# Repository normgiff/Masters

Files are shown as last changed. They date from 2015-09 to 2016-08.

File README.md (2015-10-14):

<!--
Norman Gifford
u0723476
This is my main Page
-->

<head>
<title>University of Utah Masters</title>
<link rel="stylesheet" type="text/css" href="stylesheet.css">

</head>
<body>

<div id="header">
	<h1>Daniel Khoury and Norman Gifford</h1>
	<h2>Computer Engineering Masters Project</h2>
</div>

<div id="main_body">

<p class="center_text">
Welcome to our computer engineering masters project website! Daniel and Norman
are computer engineering masters students at the University of Utah. One of the
important subjects of study st the University of Utah is VLSI (very large circuit 
integration). So important that the university gives it students the opportunity 
design and fabricate a integrated circuit chip. In important part of this process 
is to test these chips an to see if they function properly. The testers they have 
at the school to do this are either so old that it is virtually impossible to find 
replacement parts or it is very complicated to use. For these reasons our masters 
project is to design a tester that will be cheeper and easier to use. Some of the 
features are:

<ul>
	<li>	Real Time Testing.</li>
	<li>	Schmooing both Voltage and Frequency.
</ul

</p>

</div>

</body>
</html>

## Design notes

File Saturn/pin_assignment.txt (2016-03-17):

Header P3 on Numato Saturn: 
Pins 5 - 48, 53 - 88 (80 pins total)
These pins go to the ZIF socket. 

Header P2 on Numato Saturn: 
Pins 7 - 8, 11 - 12, 15 - 44, 53 - 64 (46 pins total)
These pins go to the ZIF socket.

Remaining pins on Header P2: 
65 - 88 (24 pins)

Pins 65 - 66: RX/TX lines for BBB communication
Pins 67 - 71: Four clocks for counter ICs, one reset
Pins 72 - 76: Five output buffer signals
Pins 77:      Enable pin for voltage translators
Pins 78 - 86: One output enable pin (all SRAM ICs), four ~CS signals (one per two ICs), four ~WE signals (one per two ICs)
Pins 87 - 88: Not used

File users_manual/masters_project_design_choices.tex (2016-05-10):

\section{Master's Project: Design Decisions}

\subsection{Initial Plan}
Despite the many areas of improvement for our senior project, we initially believed that a functional tester was adequate for most student-designed VLSI chips. It is worth noting that at the time of our senior project semester, students in VLSI designed their chips using a 0.6 micron process. Generally, chips fabricated using this process cannot run beyond 25 MHz. As such, we believed the best course of action was to polish our system (e.g. simplify the user interface and setup) in order to allow students to test their chips' functionality. For any timing-sensitive chips, students would be advised to construct a development board for their chip and use a logic analyzer or oscilloscope to analyze signals in detail.

When we first proposed expanding upon our senior project for our Master's project, our basic plan was to do the following: 
\begin{itemize}
\item Eliminate the Numato Saturn and fabricate a MOSIS chip containing the finite state machine logic originally used by the Saturn.
\item Replace the double-buffered shift registers inside the Saturn with external double-buffered shift registers controlled by a MOSIS chip.
\item Implement autoschmooing by replacing the trimpot on our variable voltage regulator with a digital pot.
\item Expand upon our C Sharp program (e.g. create schmooing plots).
\item Try to redesign our main PCB with equilibrium tracing.
\end{itemize}

While the plan seemed solid at first, we quickly became concerned that the project may not have been challenging enough for a Master's project. We soon came to believe that attempting to implement both autoschmooing and real-time testing would provide a more suitable challenge to us, and so, we decided to revamp our entire senior project design.

\subsection{Revised Plan}
We redefined the goals of our Master's project as follows: 
\begin{itemize}
\item Simpler interface and setup. Ideally, the entire system would be plug-and-play.
\item Real-time testing (where a test cycle is executed immediately following completion of the preceding test cycle).
\item Timing information (via PCB equilibrium tracing).
\item Automated schmooing.
\item More test cycle configurations.
\end{itemize}

We spent Fall 2015 brainstorming ideas to implement the above goals. We proposed the schematic in Figure \ref{fig:f15_schematic} at the end of the semester. Below, we detail each major component of this schematic.

\begin{figure}
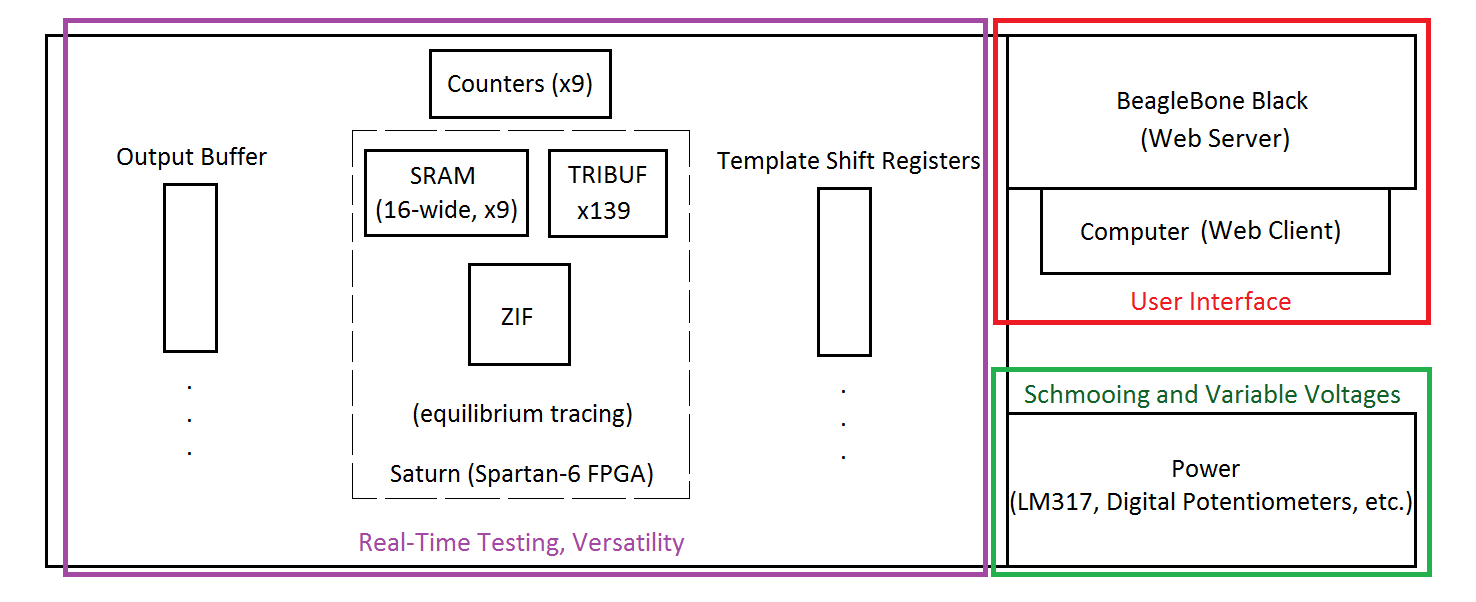
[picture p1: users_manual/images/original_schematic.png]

\caption{Schematic proposed at end of Fall 2015 semester.}
\label{fig:f15_schematic}
\end{figure}

\subsubsection{User Interface}
With our senior project, the user needed to use Windows in order to run our GUI and had to program MicroBlaze every time the system lost power. With our Master's project, we wanted a "plug and play" interface. To eliminate the need for any particular OS, we decided to use a web browser to interface with the testing system. We decided to use the BeagleBone Black board that Norm and Daniel each purchased when they took Advanced Embedded Software in Fall 2014.

The BeagleBone Black works well because it can host a small web server, runs on Linux, has the necessary I/O (SPI, UART, GPIO), and provides plenty of memory. 

\subsubsection{Timing and Voltage Schmooing}
Time schmooing, i.e. modulating the test cycle configuration (delay, width, length) between tests, naturally requires equilibrium tracing. We planned to manually route any PCBs we would design to minimize the difference in trace lengths.

Figure \ref{fig:power_schematic} is a schematic that we designed for voltage schmooing. Much of the schematic is based upon the variable voltage regulator LM317's datasheet. As the LM317 uses a reference voltage of 1.25V, we added a -1.25V bias created by an op-amp buffer (bottom-left of schematic) to set the reference voltage to 0V. We learned of this trick from  \href{http://electronics.stackexchange.com/questions/186760/why-do-linear-voltage-regulators-have-minimum-output-voltage-0-v}{this} StackExchange post. 

\begin{figure}[!h]
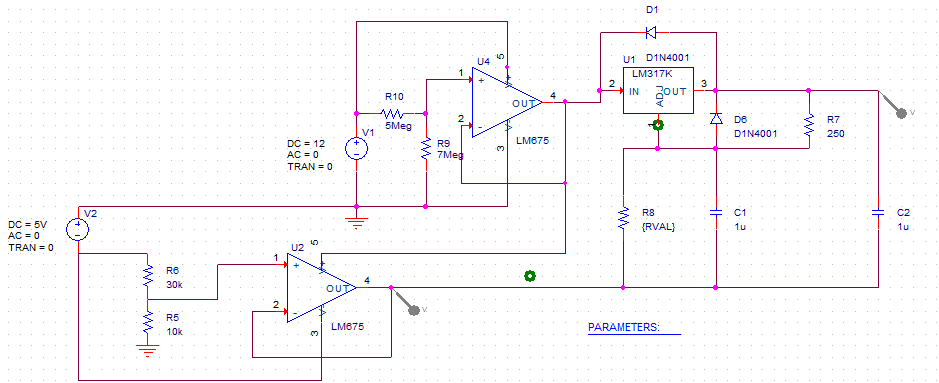
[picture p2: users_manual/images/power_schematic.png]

\caption{Power schematic for voltage schmooing.}
\label{fig:power_schematic}
\end{figure}

We simulated this schematic in PSpice and prototyped the schematic using a trimpot for the variable resistor. Figure \ref{fig:power_results} shows that the output voltage, much to our liking, responds linearly to a change in the resistance of the variable resistor.

There is an important tradeoff worth mentioning with this schematic. A higher variable resistor allows for more granularity in the output voltage. However, there is a small but fixed current that travels through the variable resistor; a larger variable resistor creates a larger error term in the output voltage. Refer to the LM317's datasheet online for more information.

For the variable resistor, we researched digital potentiometers and found that the AD5293, with 10-bit resolution at 20 kOhms, should serve well for the project.

\begin{figure}
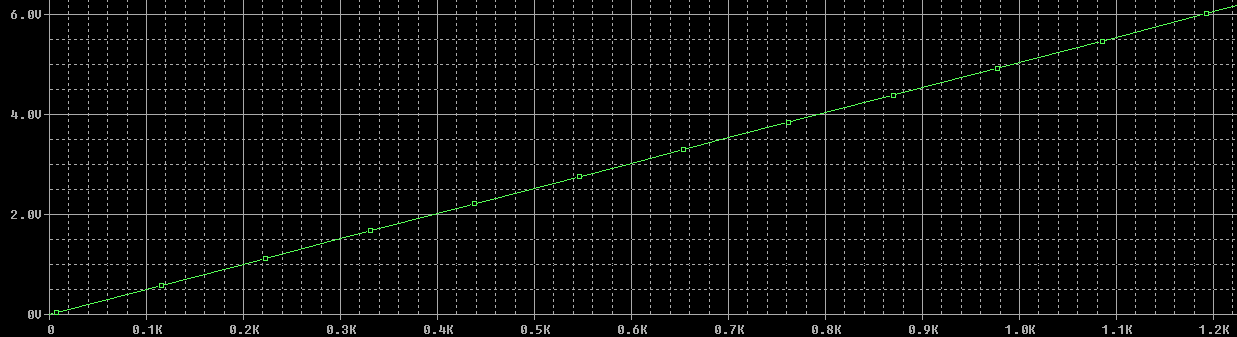
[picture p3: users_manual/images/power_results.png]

\caption{PSpice simulation results for power circuitry.}
\label{fig:power_results}
\end{figure}

\subsubsection{Real-Time Testing}
Devising a plan for real-time testing was easily the most challenging issue we faced. With our senior project, handling one input and output vector at a time was convenient because we only needed one set of double-buffered registers for all of the vectors associated with a test cycle. As such, we had to determine where the input vectors and output vectors should actually be stored.

Ultimately, we proposed the scheme in Figure \ref{fig:real_time_testing}. The basic idea was to store output vectors into external SRAM chips, and then later fetch the SRAM contents using some sort of parallel-to-serial shift register. Not shown in the image, we chose to store the input vectors in the Spartan-6 FPGA's block RAM (which allow for fast reads).

The key idea is that during test execution -- the only moment in which timing is important as far as the DUT goes -- the system only concerns itself with fetching and applying input vectors. 

\begin{figure}
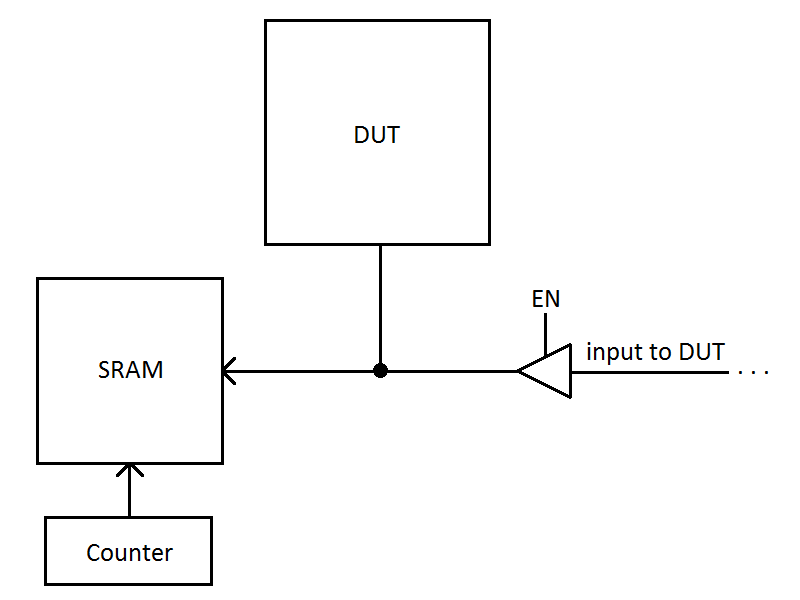
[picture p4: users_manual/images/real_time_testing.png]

\caption{Real-time testing scheme. Input vectors are stored in the FPGA's block RAM; output vectors are stored in separate SRAM chips.}
\label{fig:real_time_testing}
\end{figure}

\subsubsection{Versatility}
Though we had no specific proposals at the end of Fall 2015, we hoped to bring legacy to our project and make it upgradeable and adequate for students to use for at least a few years.

Ultimately, some of the ways we encompassed versatility in our project design is the use of multiple PCBs and the BeagleBone Black web server, which is easy to develop on.

\newpage

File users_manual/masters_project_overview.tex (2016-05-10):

\section{Master's Project: Analysis}

\subsection{Demo Video}
Although we did not have a working Communication Board at the time of our presentation, we were still able to demo our system. The video of our demo is available \href{https://www.youtube.com/watch?v=Cojl8VEp_cA&feature=youtu.be}{here}. Note that the DUT used is a MOSIS-fabricated chip containing several simple combinational and sequnetial circuits.

\subsection{What Worked}
Our demo video proves that the core ideas behind our project are sound: by making use of a Spartan-6 FPGA's block RAM and external circuitry to store output vectors, real-time testing, as well as a decent level of granularity when configuring test cycles, is feasible. 

We are particularly proud of our choice to use a BeagleBone Black for user interfacing. Using a web form to configure the tester is far more straightforward than using the .msa file template supported by the LV500. The BeagleBone Black also provides plenty of memory for storing test configurations and results.

\subsection{Areas of Improvement}
Please refer to Section 8 (Advice for Future Work).

\subsection{Difficulties Encountered}

\subsubsection{Solder Mistakes}
When we first received the DUT Board, Daniel accidentally soldered an SRAM chip upside-down. All of our attempts to remove the SRAM chip failed. Out of concern that we may have damaged the board while trying to remove the chip, we decided to scrap the board and order a new one.

\subsubsection{Communication Board}
The Communication Board, as mentioned early, has proven to be our most challenging board to get right. Power modulation can be tricky!

\subsubsection{Fitting the Verilog}
Initially, we planned to support four force-formats provided by the LV500: R0, R1, DNRZ L, and DNRZ T. When we first synthesized our Verilog, we found that our design required about 110 percent of the available slice LUTs on the board. 

After reducing the number of available force-formats to just R0 (useful for clock signals) and DRNZ L, our design only required 70 percent of the available slice LUTs, but it required about 115 percent of the available area due to routing.

We initially planned to support two completely separate test cycle configurations. To reduce the area required, we modified our design to allow one test cycle configuration, but two different leading edges (delays). After this change, we were able to fit our design into the FPGA board. Our design currently uses about 40 percent of the available slice LUTs and about 60 percent of the available area. 

Lesson learned: the amount of slice LUTs on the Spartan-6 FPGA - a little over 9000 - is not that many!

\subsubsection{Glitches in FPGA Outputs}
The output signals of the FPGA used to clock the counters are sometimes glitchy, causing the counter to increment more than intended. Having a latch driving these outputs does not appear to fix the problem. We will experiment with using the FPGA delay lines to clean the glitches; if that doesn't work, we may try using small external capacitors to clean the glitches.

\subsection{Before We Leave}
As of this writing, Daniel and Norm will both be in Utah before May 28. Before we leave, we plan to do the following:
\begin{itemize}
\item Fix the Communication Board.
\item Write the code that parses the web form and programs the digital potentiometers and the FPGA accordingly.
\item Design housing for the three PCBs.
\item Attempt to fix the glitches in the counter clock signals.
\item Organize and clean up our repository.
\item Update this document accordingly.
\end{itemize}

\newpage

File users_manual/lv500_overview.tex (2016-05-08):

\section{Overview of ASIC Testers}
All ASIC testers build upon the same simple interface: 
\begin{enumerate}
\item The user specifies what outputs to expect from their chip in response to what inputs.
\item The system applies the user-specified inputs to the device under test (DUT) and later samples the outputs of the DUT.
\item The machine reports how the sampled outputs compare to the outputs expected by the user.
\end{enumerate}

Below, we dissect and analyze these three steps both abstractly and via the LV500's implementation. Throughout this section, we define some terminology borrowed from the LV500. 

\subsection{Input and Output Bit Vectors}
Terminology: 
\begin{itemize}
\item \textbf{Input vector}: An ordered list of 0s and 1s that correspond to some ordering of a subset of the DUT's input pins. 
\item \textbf{Output vector}: An ordered list of \textit{expected} 0s and 1s that correspond to some ordering of a subset of the DUT's output pins. 
\end{itemize}

As ASIC testers are generally not designed with any specific DUT in mind, much more information accompanying input and output vectors must be provided.

\subsubsection{Pin Locations}
Any ASIC tester will define "pin locations" that are associated with some kind of socket used to connect a DUT to the tester. Obviously, mapping pins on a DUT to pin locations on an ASIC tester varies per tester. The key idea to keep in mind is that the user does not have to inform the tester of every input and output signal on the DUT. Only the pins on the DUT that the user wishes to test must be mapped to the tester's pin locations. Depending on the tester, any unspecified DUT pins may be left floating or pulled high/low with a resistor.

\subsubsection{Pin Directions}
\begin{flushleft}
Terminology: 
\begin{itemize}
\item \textbf{Pin direction}: A designator that specifies whether a DUT pin is an input or output.
\item \textbf{Template}: A bit vector that maps DUT pins to pin directions.
\end{itemize}
\end{flushleft}

In addition to providing the locations of the DUT pins to test, the user must specify the direction of these types of pins using templates. Every input and output vector is associated with some template. For bidirectional pins, different templates can be applied at different phases throughout a test. One template may designate a signal X as an input while a different template may designate that same signal X as an output. 

Thus far, we have described (abstractly) how to tell an ASIC tester about the pins on a DUT that we wish to test, which of those pins are inputs/outputs, and the signals that we expect to see in response to the signals that we wish to apply to the input pins. We must answer two other questions for the ASIC tester: 

\begin{enumerate}
\item When should input signals be applied to the DUT's input pins, and when should signals from the DUT's output pins be sampled?
\item After we apply the input signals to the DUT, what should we do with the input signals before and after the output pins are sampled?
\end{enumerate}

\subsection{Test Cycles}
One thing we must specify is when input signals to the DUT should be applied and when output signals of the DUT should be sampled.

\begin{flushleft} 
Terminology:  
\begin{itemize}
\item \textbf{Test cycle}: A window of time wherein an input vector is forced upon the DUT and the output signals of the DUT are (later) sampled.
\item \textbf{Test cycle length}: The length (in time) of a test cycle.
\item \textbf{Test cycle delay}: The amount of time between the beginning of the test cycle and when an input vector should be forced upon the DUT.
\item \textbf{Test cycle width}: The amount of time between when an input vector should be forced upon the DUT and when the output signals of the DUT should be sampled.
\item \textbf{Test}: The execution of all input vectors specified by the user.
\end{itemize}
\end{flushleft}

Figure \ref{fig:singleTestCycle} below illustrates how a test cycle can be thought of as just a configurable pulse (though test cycles don't necessarily have to be implemented as an actual pulse). It is important to note that the test cycle itself is NOT sent to the DUT. Test cycles use two edges (a rising edge and falling edge) to signify when to force inputs and sample outputs, respectively.

\begin{flushleft}
Terminology: 
\begin{itemize}
\item \textbf{Leading edge}: A rising edge that corresponds to a test cycle's delay.
\item \textbf{Trailing edge}: A falling edge that corresponds to a test cycle's width.
\end{itemize}
\end{flushleft}

To get a sense of how test cycles are used, consider Figure \ref{fig:ANDGateTestCycle} below. Assume the following setup as the context of this figure: 
\begin{itemize}
\item Our DUT contains three pins mapping to a two-input AND gate that we wish to test.
\item We have informed the ASIC tester of where these three pins are located, which two of the three pins are inputs, and which of the three pins is the output. (We have also named the input pins A and B and the output pin Y for convenience.)
\item We have specified two input vectors: {A = 1, B = 1} and {A = 0, B = 0}, along with two corresponding output vectors: {Y = 1} and {Y = 0}.
\item We specified a test cycle length of 100 ns, a test cycle delay of 20 ns, and a test cycle width of 50 ns.
\end{itemize}

\begin{figure}
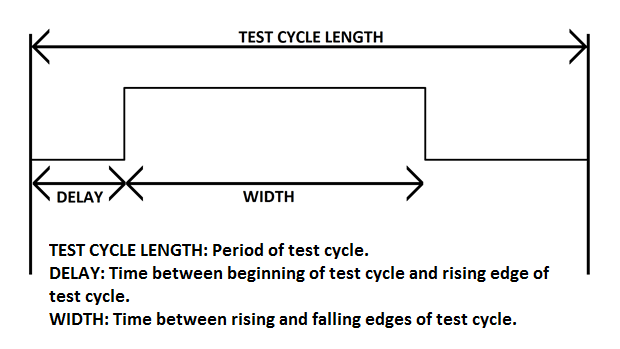
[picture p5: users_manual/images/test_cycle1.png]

\caption{A single test cycle.}
\label{fig:singleTestCycle}
\end{figure}

\begin{figure}
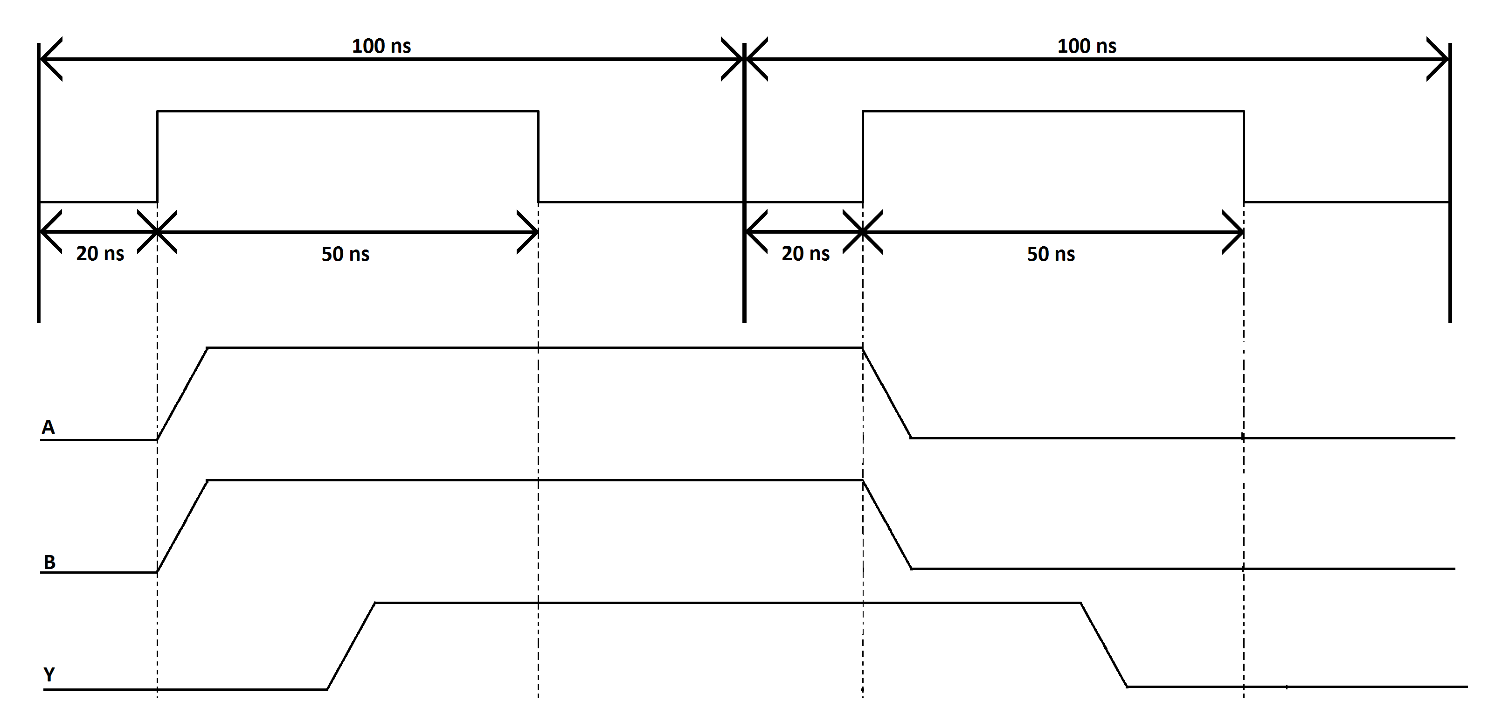
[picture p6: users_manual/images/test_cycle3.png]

\caption{Testing an AND gate with a test cycle configured to have a length of 100 ns, a delay of 20 ns, and a width of 50 ns. Two input vectors (and thus two cycles) are applied to the DUT.}
\label{fig:ANDGateTestCycle}
\end{figure}

\subsection{Force Formats}
Note that in Figure \ref{fig:ANDGateTestCycle}, the inputs A and B latch onto whatever value they are assigned at every leading edge. It may be desirable to have A and B behave differently, however. For instance, we may want A and B to latch onto whatever value they are assigned at every leading edge, but return to 0 at every trailing edge. For versatile testing, an ASIC tester must also provide (what the LV500 calls) force formats to be associated with every input pin.

\begin{flushleft}
Terminology: 
\begin{itemize}
\item \textbf{Force format}: A specification for how an input signal should behave during a test cycle. 
\end{itemize}
\end{flushleft}

\textit{An aside}: The LV500 uses the term "force" to refer to applying inputs to DUT pins, hence the phrase "force format".

The LV500 defines five natural force-formats: 
\begin{itemize}
\item \textbf{R0}: Inputs latch onto their assigned values on leading edges, but return to 0 on trailing edges. (Return to zero.)
\item \textbf{R1}: Inputs latch onto their assigned values on leading edges, but return to 1 on trailing edges. (Return to one.)
\item \textbf{DNRZ L}: Inputs latch onto their assigned values on leading edges. (Delayed non-return-to-zero, leading edge.)
\item \textbf{DNRZ T}: Inputs latch onto their assigned values on trailing edges. (Delayed non-return-to-zero, trailing edge.)
\item \textbf{R INH}: Inputs latch onto their assigned values on leading edges, but return to high-Z on trailing edges. (Return to inhibited.)
\end{itemize}

Figure \ref{fig:ANDGateTestCycleFF} below is the same setup as Figure \ref{fig:ANDGateTestCycle}, but with the R0 force-format used for A and B (as opposed to the DNRZ L force-format). Note that A and B do not have to be assigned the same force-format! Any ASIC tester should allow every individual pin to be associated with its own force-format. In this case, there is nothing invalid about input A being associated force-format R0 and input B being associated force-format R1, for instance.

\begin{figure}
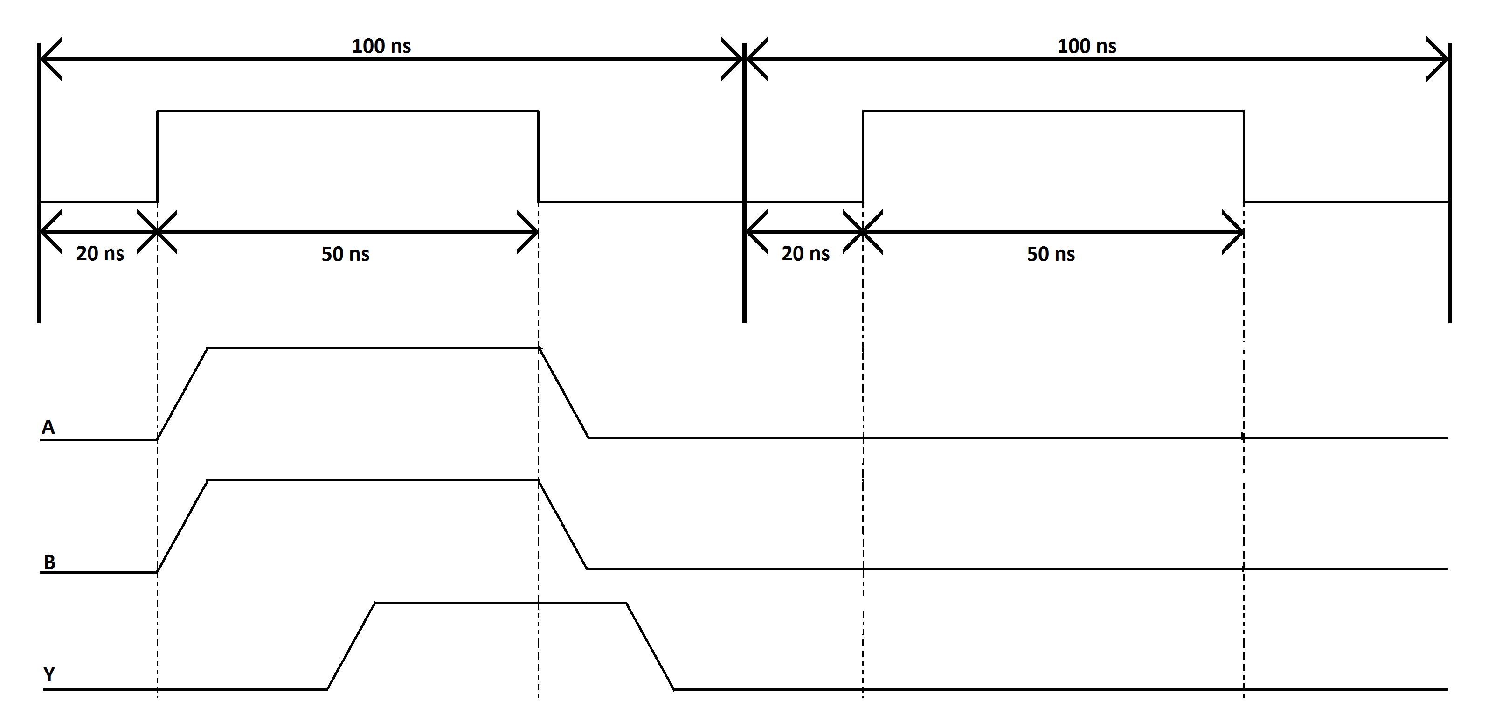
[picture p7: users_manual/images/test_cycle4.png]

\caption{The same configuration as Figure \ref{fig:ANDGateTestCycle} but with a different force format for the inputs.}
\label{fig:ANDGateTestCycleFF}
\end{figure}

\subsection{Combinational Circuits vs. Sequential Circuits}
As shown with Figures \ref{fig:ANDGateTestCycle} and \ref{fig:ANDGateTestCycleFF}, testing a combinational circuit is fairly straightforward. On the other hand, testing a sequential circuit requires more functionality from an ASIC tester. We certainly don't want to transition the clock signal at the same time as the inputs -- otherwise, we may violate the setup times of registers within the DUT. A solution to this problem is to allow every pin to be associated with a test cycle. Consider Figure \ref{fig:DFFTestCycles} below, which demonstrates testing a D Flip-Flop (DFF). We associate the D input to the DFF with the uppermost test cycle and the CLK input to the DFF with the lowermost test cycle. As seen in the figure, we allow D 20 ns to settle on the input to the DFF before we transition the clock. Note that the output of the DFF, Q, needs to be associated with one of the two test cycles in the figure. Whichever test cycle Q is associated with, we sample Q on the trailing edge of the cycle.

\begin{figure}
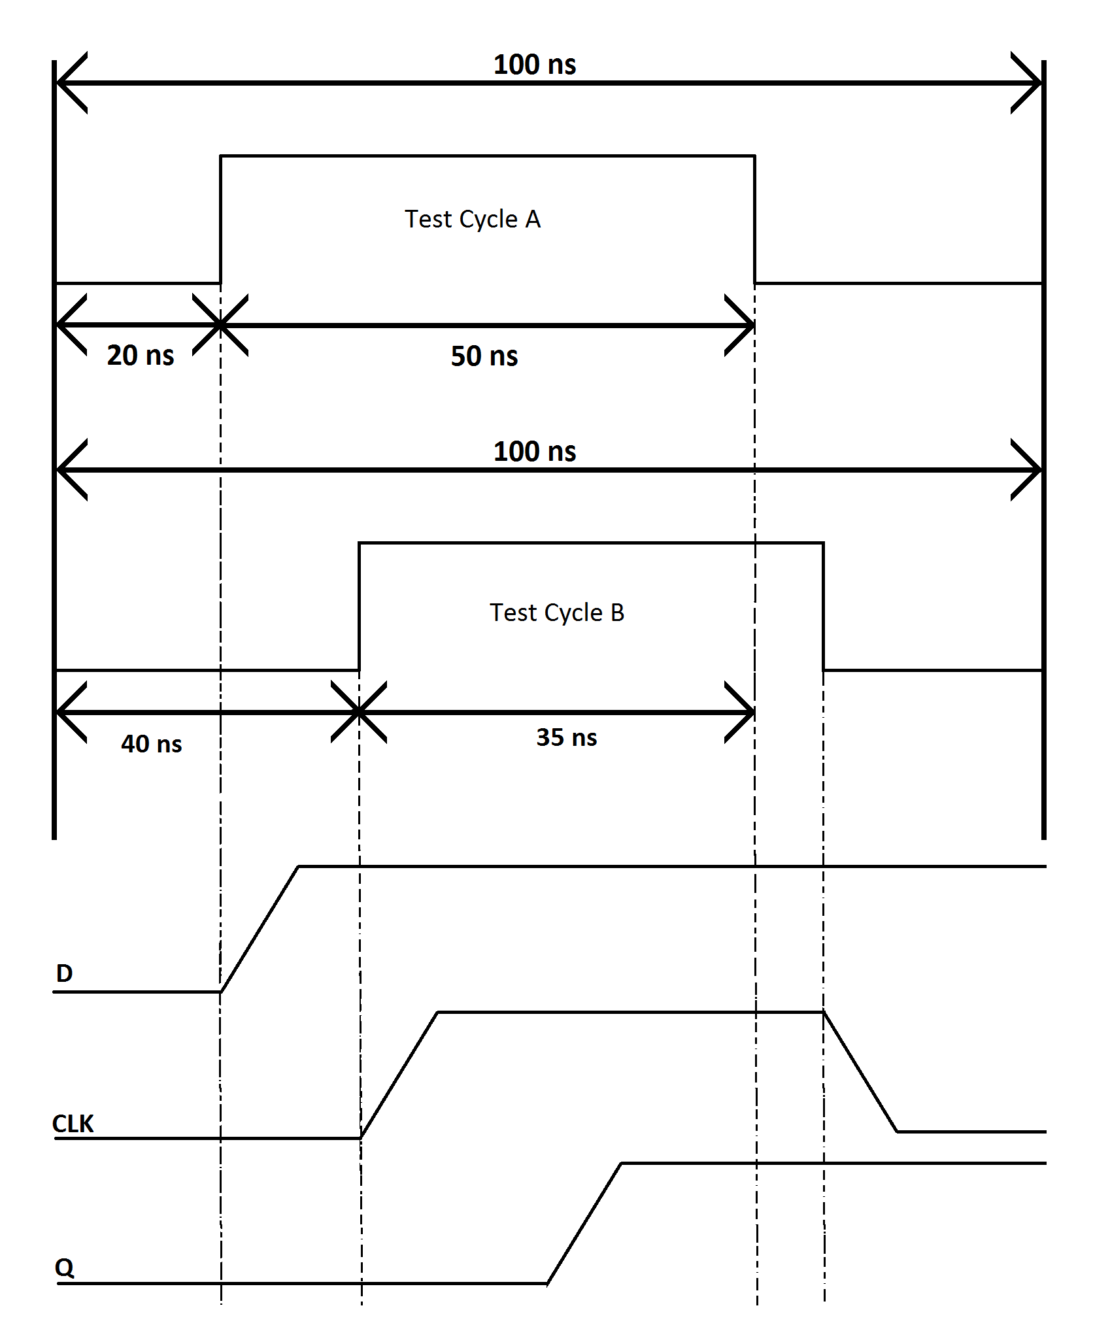
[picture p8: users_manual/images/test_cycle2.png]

\caption{Testing a D Flip-Flop.}
\label{fig:DFFTestCycles}
\end{figure}

\subsection{Electrical and Dynamic Configurations}
A DUT may require a variety of different VDDs -- 5V, 3.3V, 1.8V, etc., so an ASIC tester needs to provide different VDDs for different chips. More interesting, however, is how a DUT may respond to unideal high and low voltage values. For instance, if we know that logic low values may range between 0V and 0.5V and that logic high values may range between 4.2V and 5V, it'd be interesting to know how a DUT will respond to these kinds of voltage values.

Additionally, it may be worth knowing how fast our DUT is. Consider Figure \ref{fig:DFFTestCycles}, where we test a DFF. One way to estimate the setup time of the DFF would be to gradually bring the two leading edges closer to each other until the Q output fails to meet our expectations.

\begin{flushleft}
Terminology: 
\begin{itemize}
\item \textbf{Schmooing}: Repeating a test some number of times, with just one electrical or timing characteristic differing between tests.
\end{itemize}
\end{flushleft}

Consider Figure \ref{fig:ANDGateTestCycleFF}, where we perform a simple test of an AND gate using two input vectors. An example of schmooing would be repeating the entire test, but with the VDD for the input signals starting at 5V for the first test and dropping by 0.2V on each subsequent test until VDD reaches 4.2V. (So, a total of five tests, where each test consists of two test cycles.) Another example, with Figure \ref{fig:DFFTestCycles}, would be to increase the delay of the uppermost test cycle by 1 ns on each subsequent test up to 40 ns. (So, a total of 20 tests.)

Even better, the LV500 allows users to generate plots of the percentage of output vectors that pass in comparison to the one or two electrical/timing characteristics schmooed. 

\subsection{Further Reading}
Refer to \href{https://view.officeapps.live.com/op/view.aspx?src=http://www.ece.utah.edu/~kstevens/6712/tester.ppt}{these slides}, created by Ken Stevens and Erik Brunvand, for more information on how the LV500 works.

\newpage

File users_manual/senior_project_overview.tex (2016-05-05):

\section{Senior Project Overview}

In 2014, Erik Brunvand proposed the idea of constructing an ASIC tester using an FPGA and a digital clock manager. Daniel immediately took interest in the idea and later formed a team with Norm Gifford, Tyler Martinsen, and Ruben Gottardi. This section glosses over our senior project to provide context of where the ideas for our Master's project stem from. Detailed information about our senior project can be found on our repository. 

\subsection{Project Architecture}

\subsubsection{Hardware Flow}
Figure \ref{fig:senior_project_hardware_flow} illustrates the four hardware components of their board: 
\begin{itemize}
\item A \textbf{PC} provides a program for user-interfacing. Written in C Sharp, this program first reads and parses a text file that configures the tester. (This text file is largely based upon the .msa file format used by the LV500.) Through a serial connection, the PC then transmits the contents of the text file to a Xilinx \textbf{MicroBlaze} processor running on a \textbf{Digilent Atlys board}. 
\item The \textbf{MicroBlaze} processor simply converts the serial commands retrieved from the PC into SPI commands suited for the \textbf{Numato Saturn Spartan-6 FPGA board}.
\item The \textbf{Numato Saturn} houses the logic that is used to execute a single test cycle. In particular, the FPGA sends signals to the DUT on the \textbf{main PCB} and samples output signals from the DUT. 
\item The \textbf{main PCB} simply contains 139 voltage translators and a ZIF socket to house the DUT. 
\end{itemize}

\begin{figure}
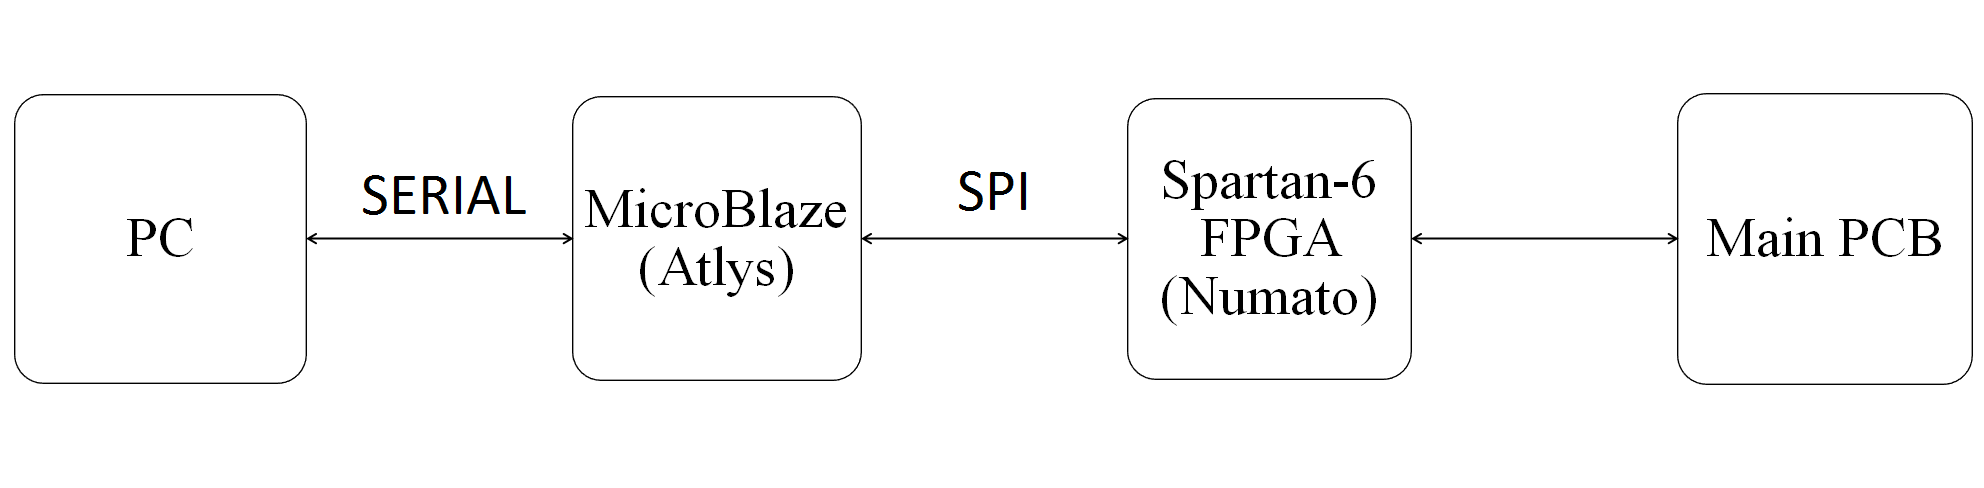
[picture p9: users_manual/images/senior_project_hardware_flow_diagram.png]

\caption{Senior project hardware flow diagram.}
\label{fig:senior_project_hardware_flow}
\end{figure}

\subsubsection{Software Flow}

Figure \ref{fig:senior_project_software_flow} illustrates the flow of the C Sharp program used to interface with the tester. The key observation is that the C Sharp program parses and transmits to the MicroBlaze processor a \textbf{single} input vector at a time. For every input vector parsed, that input vector makes its way to the Numato Saturn, which executes that test vector and samples the outputs of the DUT. The C Sharp program then sends a request to the MicroBlaze processor, asking for the output vector stored in the FPGA. After retrieving the output vector and comparing the sampled bits to the bits expected by the user, the C Sharp program parses and transmits the next input vector. When all input vectors are processed, the results are displayed to the user.

\begin{figure}
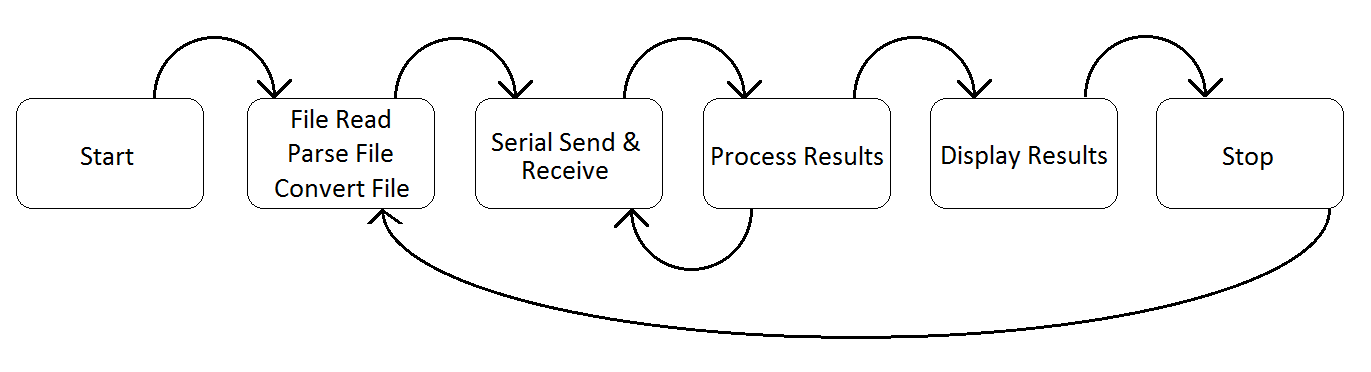
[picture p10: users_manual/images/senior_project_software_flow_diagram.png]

\caption{Senior project hardware flow diagram.}
\label{fig:senior_project_software_flow}
\end{figure}

\subsection{What Worked}
There are three features of our system that we excelled in: 
\begin{itemize}
\item \textbf{Functional testing} appeared to work fine. Our system was able to correctly test circuits like an inverter, AND gate, OR gate, and DFF. (A note: We define functional testing as simply seeing if the outputs of a DUT respond correctly to the inputs applied to the DUT, with no timing or electrical characteristics of the DUT taken into account.)
\item Unlike the LV500, our system \textbf{does not contain fixed VDD and GND locations} for the DUT. VDD and GND are provided to the DUT using jumper wires and jumper pins. 
\item \textbf{Manual schooming} was enabled using a variable voltage regulator and separate power jacks for the DUT VDD and FPGA VDD.
\end{itemize}

\subsection{Areas of Improvement}
Although functional testing - the key feature of our system - appeared to work, there were several areas of improvement that prevented our project from serving as a substitute for the LV500 and Verigy 93000 testers: 
\begin{itemize}
\item Since every input vector must travel through the entire hardware pipeline and back, \textbf{real-time testing}, which we define as executing a test cycle immediately after the completion of a preceding test cycle, is not possible with the design that we chose. Real-time testing can help provide more detailed timing information about a DUT.
\item \textbf{Autoschmooing}, which we define as schmooing controlled by the hardware/software, is not supported. Obviously, autoschmooing is far more convenient than manual schmooing, and autoschmooing allows the system to generate plots of when the DUT's output vectors match expectations and when they don't.
\item Our system only supports \textbf{one template}, due to lack of time. Multiple templates are needed for any chips with bidirectional pins.
\item The MicroBlaze processor had to be reprogrammed everytime power was cut off from the Atlys board. This issue, along with the inclusion of the Atlys board itself, made the system as a whole \textbf{clumsy and unintuitive to use}. (A note: We intended to program MicroBlaze onto the Numato Saturn but had difficulties doing so.)
\item We attempted to utilize a PLL package provided by Xilinx to allow dynamically-reconfigurable frequencies, phase shifts, and duty cycles for the internal test cycles (i.e. the clock waveforms that represent the length, width, and delay of a test cycle). The PLL proved to be problematic, however; the best performance we obtained was from fixing the frequencies of the PLL's outputs at 2 MHz and offering just a few options for phase shifts and duty cycles. Having \textbf{highly configurable} test cycles is crucial to obtain timing information about a chip.
\item  Because our main PCB board lacked equilibrium tracing, we were unable to provide a \textbf{reasonable average for the wire delay} between the DUT and FPGA, which again impeded our ability to provide timing information of the DUT to the user.
\end{itemize}

\newpage

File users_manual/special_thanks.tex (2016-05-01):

\section{Special Thanks}

We are sincerely grateful to the following people: 
\begin{itemize}
\item Ken Stevens, our Master's project advisor, for providing us with proper guidance throughout this project.
\item Erik Brunvand, our senior project advisor, for providing us with FPGA boards for prototyping and the ZIF socket we used for our DUT board.
\item Michelle Gifford, Norm's wife, for helping to create the housing for our project.
\item Advanced Circuits, our go-to PCB manufacturer, for offering student prices that cannot be found anywhere else. 
\item Our families, who put up with our absences and will need to get to know us again.
\end{itemize}

\newpage

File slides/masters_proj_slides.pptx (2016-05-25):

## The LV600 The Spiritual Successor to the Tektronix LV500

Norm Gifford
Daniel Khoury
Project Advisor: Ken Stevens

## Motivation

- CS 6712 requires chip testing, but…
  - LV500 is unreliable
    - Calibration fails
    - Several sectors are dead
  - Verigy 93000 is not operational
    - HDD is dead
    - Support expired
- Potential legacy
- Fun, challenging project

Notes: Norm

## Senior Project (Fall 2014)

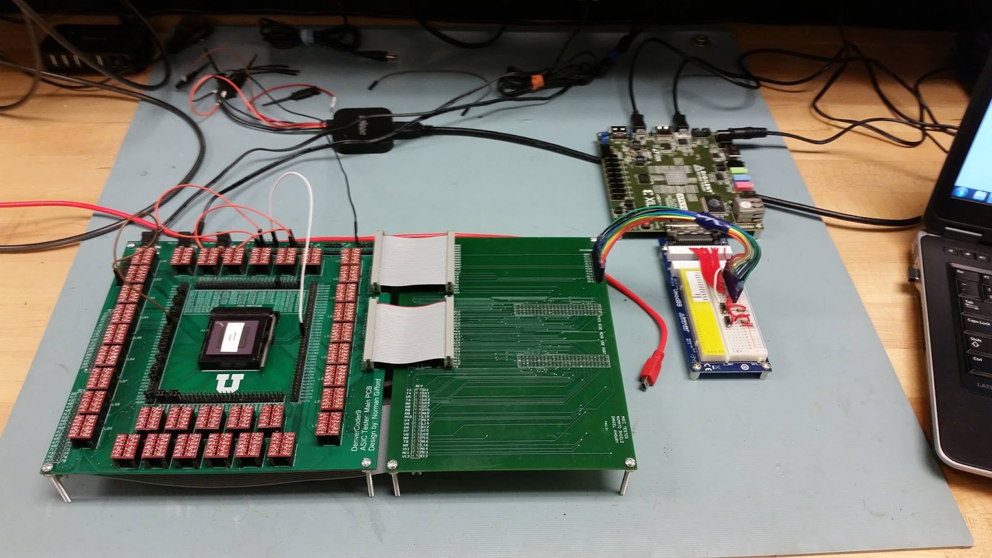
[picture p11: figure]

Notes: Norm

## Senior Project (Fall 2014)

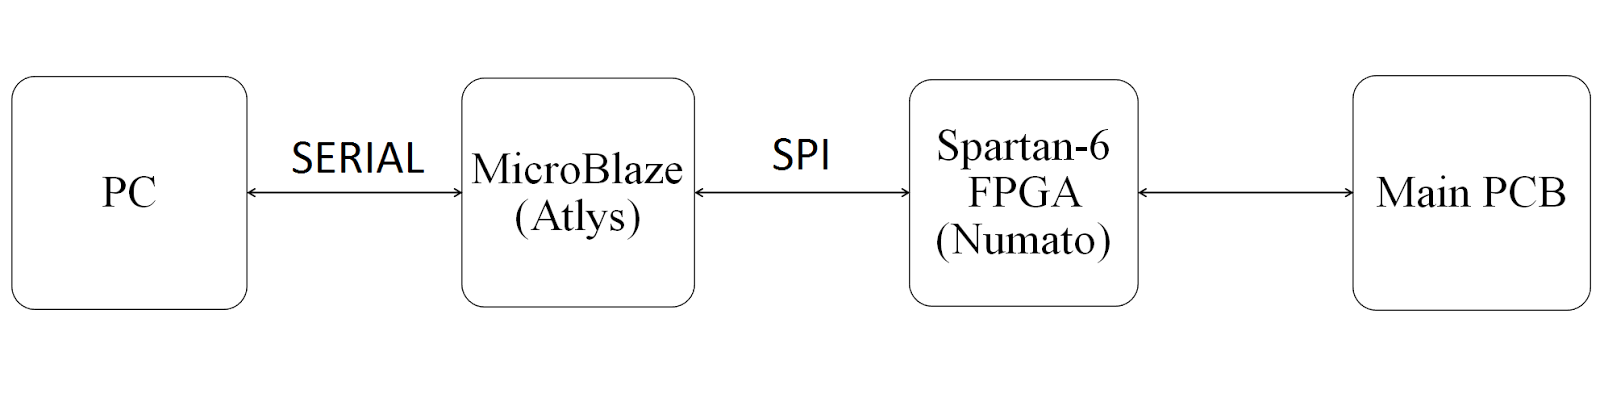
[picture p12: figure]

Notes: Norm
Slow system (huge latency between sending test vector and getting output vector)

## Senior Project (Fall 2014)

- What worked well:
  - Functional testing!
  - Unfixed power and ground locations
  - Manual schmooing
- Areas of improvement:
  - Real-time testing
  - Autoschmooing
  - Support for multiple templates
  - Interface and setup
  - Configuration options for test cycles
  - Accurate timing information

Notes: Norm

## Master’s Project: Initial Plan

- Redo our senior project, but…
  - Simplify the user interface and setup
  - Replace the FPGA logic with a MOSIS-fabricated chip
  - Try to automate schmooing
  - Equilibrium tracing (for accurate timing info)
- Issues:
  - Constrained by MOSIS fabrication deadlines
  - Lack of versatility

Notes: Daniel

## Master’s Project: Revised Plan

- Complete revamp of our senior project design
- Main goals:
  - Simpler interface and setup
  - Real-time testing
  - Timing information (via equilibrium tracing)
  - Automated schmooing
  - More test cycle configurations
- Fall 2015 semester dedicated to planning and prototyping
- Spring 2016 semester dedicated to implementation

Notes: Daniel

## Simpler Interface and Setup

- BeagleBone Black web server
  - Web form to fill out and submit tests
  - Commands FPGA via RX/TX lines
- Numato Saturn FPGA
  - Configuration programs flashes Verilog onto the board

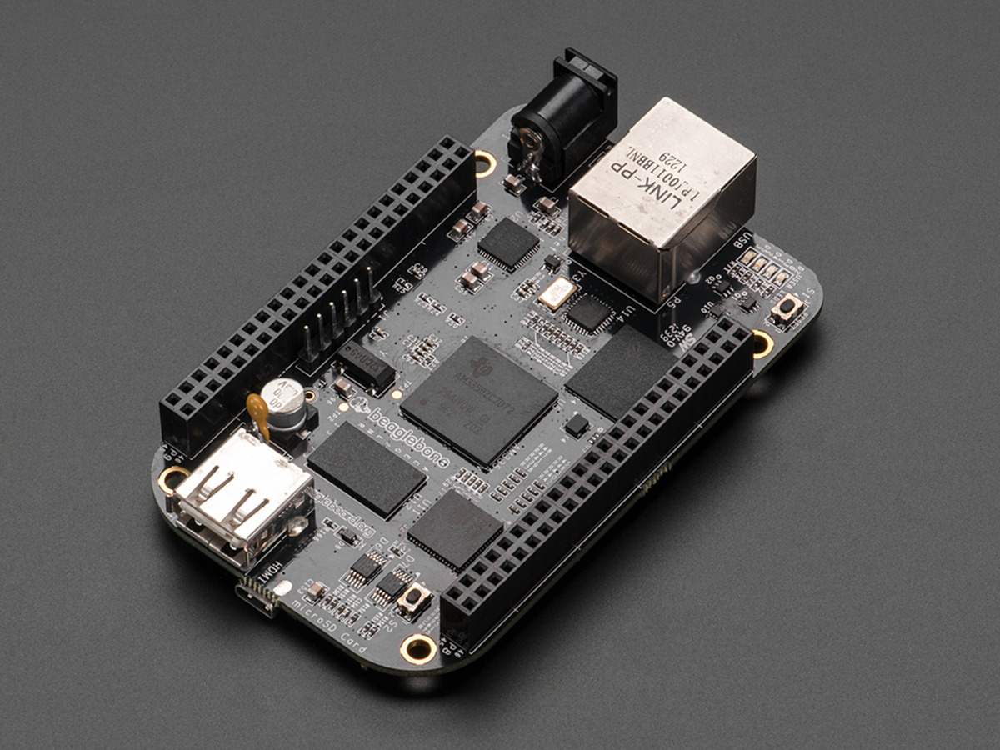
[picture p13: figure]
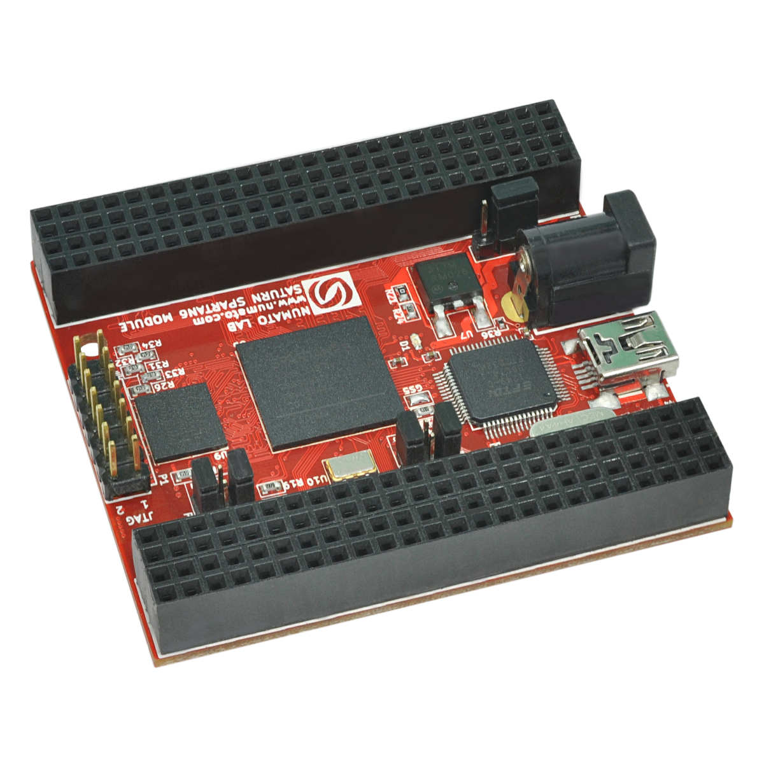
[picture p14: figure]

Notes: Norm

## Real-Time Testing

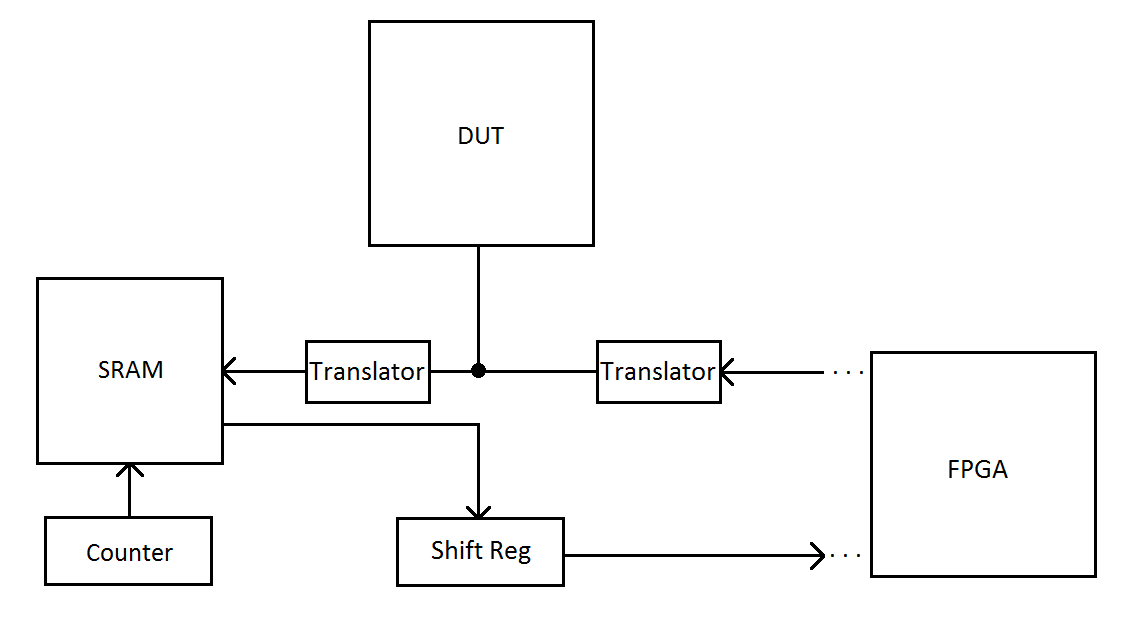
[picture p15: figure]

All bit vectors stored in block RAM for fast read access

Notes: Norm

## Automated Schmooing

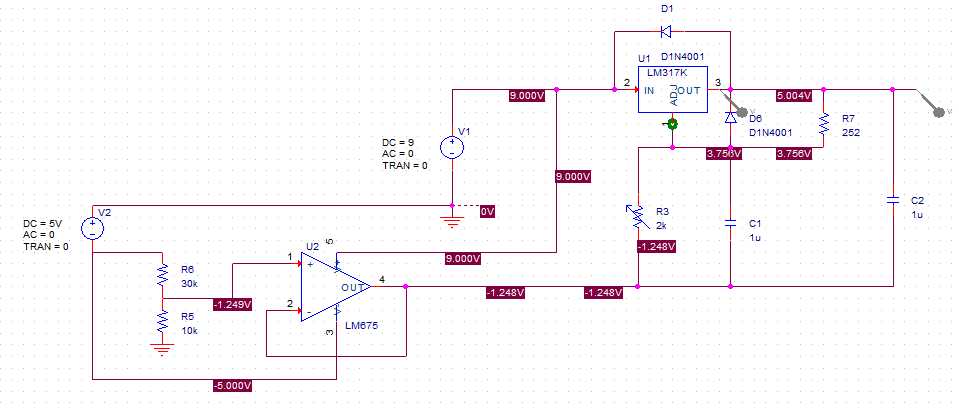
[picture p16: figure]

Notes: Daniel

## Automated Schmooing


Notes: Daniel

## Test Cycle Configurations: Original Idea

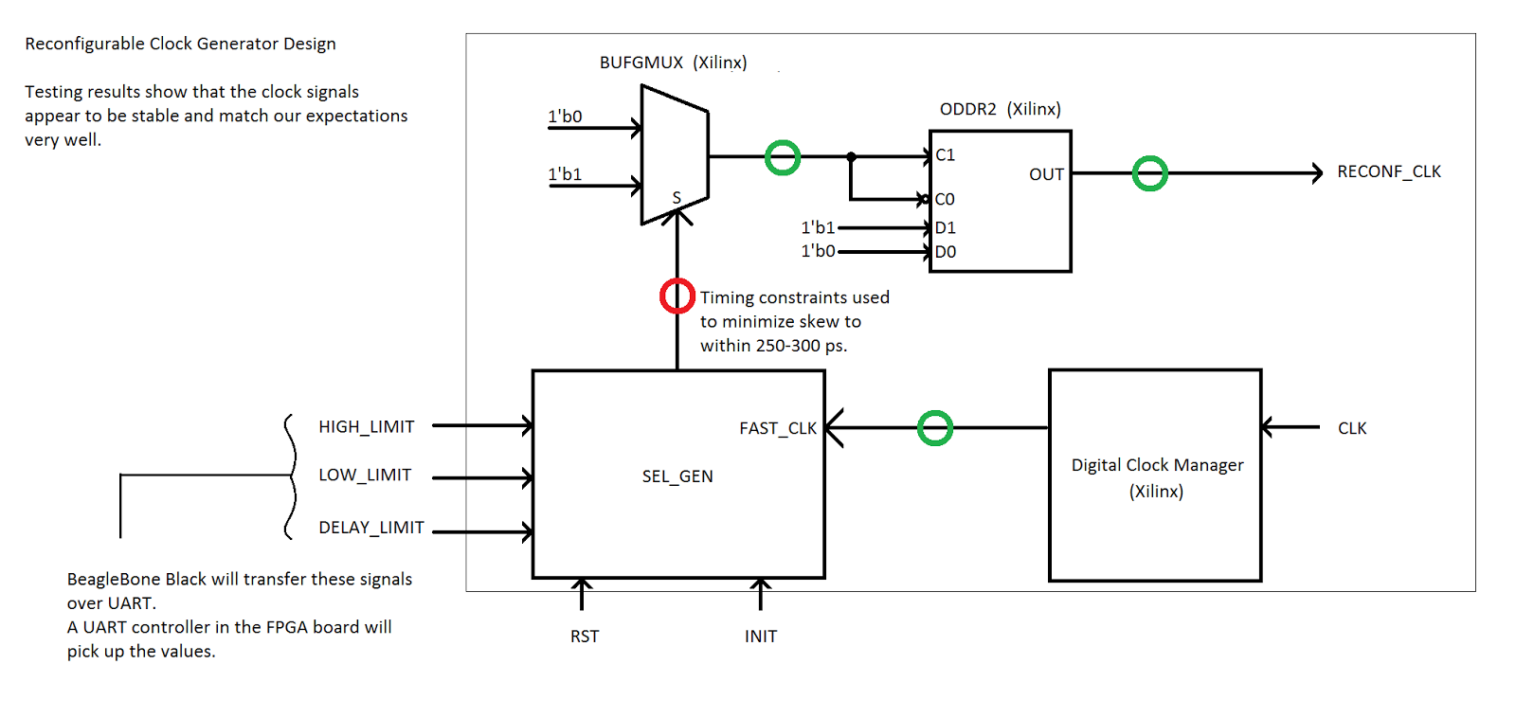
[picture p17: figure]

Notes: Daniel

## Test Cycle Configurations: Later Idea

- Key insight: No need to create the actual test cycle waveforms inside the FPGA
- Instead, count clock edges
  - User specifies leading edges, trailing edge, cycle length as multiples of 10 ns

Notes: Daniel

## PCBs

- Three PCBs:
  - Numato shield
  - Communication board
  - DUT board
- Boards designed with versatility in mind

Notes: Norm

## PCBs: Numato Shield

- Four-layer board
- Manually routed
- Equilibrium tracing
  - Surprisingly tedious and difficult
  - Tolerance: 200 mil

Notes: Norm

## PCBs: Communication Board

- Two-layer board
- Autorouted
- Core functionality:
  - Connects BBB to FPGA via RX/TX lines
  - Connects BBB to schmooing circuitry
  - Connects FPGA to DUT board
  - Contains voltage translators (between FPGA and DUT)

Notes: Norm

## PCBs: DUT Board

- Four-layer board
- Autorouted
  - Trickiest part was component placement
  - 100 minutes to route!
- Contains:
  - ZIF socket (thank you Erik!)
  - Four counters
  - Eight SRAM blocks
  - 16 voltage translators
  - 16 parallel->serial shift registers

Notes: Norm

## Software Flow

- User fills out and submits web form
- BeagleBone Black (BBB) transmits all bit vectors and configuration data to FPGA
- BBB instructs FPGA to execute tests
- FPGA signals BBB when tests are complete
- BBB commands FPGA to send back output vectors
- BBB displays test results

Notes: Norm

## Software Flow (Continued)

- Mostly PHP and HTML
  - PHP provides exec function, can call C code that parses web form input
  - Output stream (printf statements) passed back to web form
- AJAX used to dynamically add/remove vectors
- (Online)
- C code consists of UART and SPI libraries
  - UART for FPGA communication
  - SPI to control digital pots in power circuitry

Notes: Norm

## Hardware Flow

- Handshaking protocol between BBB and FPGA
- Commands BBB can send to FPGA:
  - Store input vector
  - Store cycle vector
  - Store template vector
  - Store force-format vector
  - Store cycle configuration data
  - Execute tests
  - Send back output vector

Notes: Daniel

## Hardware Flow

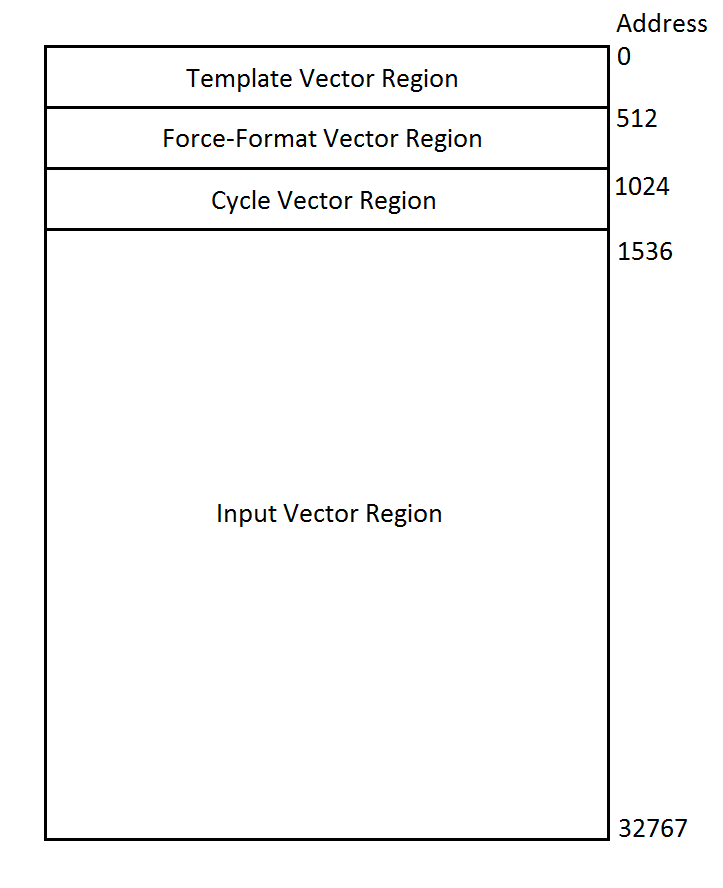
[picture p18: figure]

- All vectors are 128-bit wide
- Up to four templates
- Total number of input vectors: 244
  - Good enough for most chips

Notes: Daniel

## Hardware Flow (Continued)

- FPGA responds to BBB commands as follows
- Store input/cycle/template/force-format vector:
  - Save vector in block RAM
  - If input vector, track how many vectors have been written
- Store cycle configuration data:
  - Load counters with delays for leading edges, trailing edge, cycle length

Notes: Daniel

## Hardware Flow (Continued)

- Execute tests:
  - While there are more input vectors to read:
    - Beginning of cycle: Fetch next input vector
    - Leading edge: Apply inputs, enable SRAM blocks (write-mode)
    - Trailing edge: Disable SRAM blocks
    - End of cycle: Increment counter
      - If the template associated with the new input vector has not changed, load the fetched input vector
      - Else pause real-time testing, load the template, cycle, and force-format vectors associated with the new template, then load the fetched input vector and resume real-time testing
  - Reset the counter

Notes: Daniel

## Design Challenges: PCBs

- Communication board failed twice
  - First time: Short between 3V3 and GND (manufacturing error?)
  - Second time: Power and ground reversed on barrel jacks
  - Third time is the charm!
    - Should have ready mid-May.
- Autorouting the DUT board proved difficult
  - Component placement is key!

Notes: Norm

## Design Challenges: Verilog

- Initial Verilog design included R0, R1, DNRZ_L, DNRZ_T force formats (2-bit encoding)
  - Design required 108% of available LUTs
- Removed DNRZ_T and R1 force formats (1-bit encoding)
  - Design required 70% of available LUTs, but 115% of FPGA area
- Removed ability to specify two different test cycles, replaced with one test cycle but two leading edges
  - Design now utilizes 40% of available LUTs, 70% of available area
- Some timing-sensitive FPGA outputs (e.g. counter clock) are glitchy
  - Capacitors may smooth out glitches – need to investigate

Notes: Daniel

## Demo!

https://www.youtube.com/watch?v=Cojl8VEp_cA

## Remaining Contemporary Work

- Finish web server code that parses web form into C code arguments
- Fix communication board
- Documentation

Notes: Norm

## Estimated cost

- PCBs: ~$220
  - Two four-layer boards + shipping: $170
  - One two-layer board + shipping: $50
- Parts for PCBs: ~$250 (not including ZIF socket)
- Numato shield: ~$80 (student discount)
- BeagleBone Black: ~$50
- Total cost: ~$600 (closer to ~$1000 if we include failed boards and repurchasing parts)

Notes: Norm

## Future Ideas: Web Server

- Security measures…
  - Anyone can log in as root right now…
- User accounts and passwords
- Store test vectors in database
- Schmooing plots

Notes: Norm

## Future Ideas: Hardware

- Bigger, better FPGA
  - Xilinx Spartan-6 isn’t designed to handle very high frequencies
  - 7-series Xilinx FPGAs are designed for fast clock speeds, but are extremely expensive
  - Snickerdoodle board: https://www.crowdsupply.com/krtkl/snickerdoodle
    - ZYNQ SoC (ARM processor + FPGA)
    - Provides 150 I/O pins
    - $150
- Conditional test vectors may be possible with two FPGAs, or an FPGA with ~300 pins
  - Area of further investigation

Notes: Daniel

## Design Challenges: Verilog

- Initial Verilog design included R0, R1, DNRZ_L, DNRZ_T force formats (2-bit encoding)
  - Design required 108% of available LUTs
- Removed DNRZ_T and R1 force formats (1-bit encoding)
  - Design required 70% of available LUTs, but 115% of FPGA area
- Removed ability to specify two different test cycles, replaced with one test cycle but two leading edges
  - Design now utilizes 40% of available LUTs, 70% of available area

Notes: Daniel

## Reflection and Impact

- Project pushed us to our limits
  - Verilog is over 2000 lines, more than 50 states for “main” FSM
  - Hardware boards by far the most complicated we have ever designed
- Proud of our design choices
  - Things we learned (amongst other things):
    - How to utilize hierarchical schematics and autorouting rules in Altium
    - The Spartan-6 FPGA is (relatively) limited!
    - Glitch-free FPGA outputs can be difficult to achieve
      - Double-buffering signals seems to help
    - PHP can call C executables!

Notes: Daniel

## Special Thanks

- Ken Stevens
  - Awesome project advisor, provided useful feedback
- Erik Brunvand
  - Provided (expensive) ZIF socket, FPGA boards, and useful feedback
- Advanced Circuits
  - Reasonable prices (and free popcorn with every board purchase)

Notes: Daniel and Norm wrap up talk

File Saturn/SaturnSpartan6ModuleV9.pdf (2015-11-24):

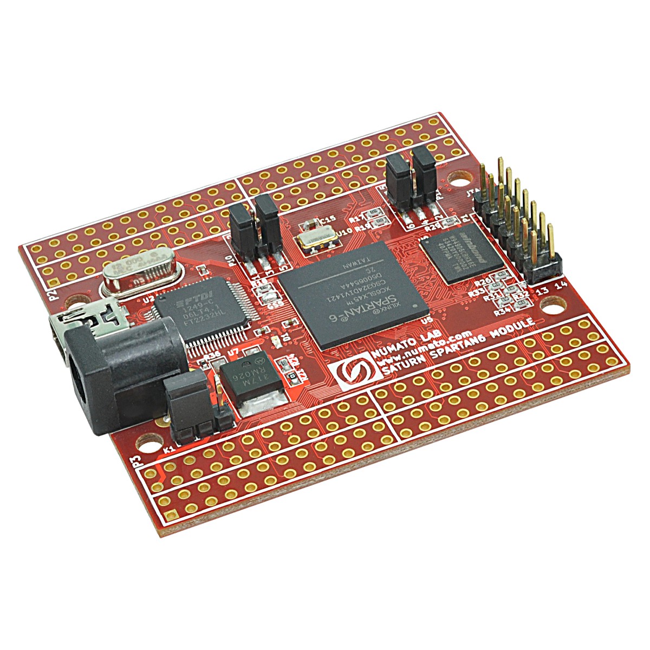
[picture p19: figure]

# Saturn Spartan 6 FPGA Development Board

## User Guide

www.numato.com | Rev 9

## Get in touch with us!

Please feel free to send a mail to one of the mail IDs below or use the Contact Us page at http://www.numato.com to drop us a quick message.

Technical Help
Got technical questions? Please write to help@numato.com

Sales Team
Questions about making payments, volume discounts, academic/open source discounts, purchase orders and quotes? Please write to sales@numato.com

Webmaster
Questions/Suggestions about our website? Please write to webmaster@numato.com

Like us on Facebook! https://www.facebook.com/numato

Visit our blog http://www.numato.cc for news, updates and specials.

Mailing Address
Numato Systems Pvt Ltd
1st Floor, #56C Wipro Avenue
Phase 1 - Electronic City
Bangalore, KA-560100, India

* Mail orders, phone orders and direct pick up are not available at this time. Please visit our online store to place your order. Estimated shipping time to your address will be displayed in the shopping cart before checkout.

You may use, modify or share this publication or part of thereof adhering to Creative Commons Attribution-ShareAlike 3.0 Unported (CC BY-SA 3.0) License.
See complete license text at http://creativecommons.org/licenses/by-sa/3.0/
All trademarks are property of their respective owners.

1 | Saturn Spartan 6 FPGA Developmant Board – User Guide

## Introduction

Saturn is an easy to use FPGA Development board featuring Xilinx Spartan-6 FPGA. Saturn is specially designed for experimenting and learning system design with FPGAs. This development board features Xilinx XC6SLX series FPGA with FTDI’s FT2232H Dual-Channel USB device. The high speed USB 2.0 interface provides fast and easy configuration download to the on-board SPI flash. No programmer or special downloader cable is needed to download the bit stream to the board.

Applications
- Product Prototype Development
| • Development and testing of custom embedded processors
- Signal Processing
- Communication devices development
| • Educational tool for Schools and Universities

Board features
| • FPGA: Spartan-6 XC6SLX9, LX16, LX25 or LX45 in CSG324 package
- DDR: 166MHz 512Mb LPDDR
| • Flash memory: 128 Mb SPI flash memory (N25Q128A13ESE40E)
- 100MHz CMOS oscillator
| • High Speed USB 2.0 interface for On-board flash programming. FT2232H Channel A is dedicated for SPI Flash /JTAG Programming. Channel B can be used for custom

applications.
| • On-board voltage regulators for single power rail operation
- FPGA configuration via JTAG and USB
| • Maximum 158 IOs for user defined purposes
XC6SLX9 - 118 IOs
XC6SLX16 - 150 IOs
XC6SLX25 - 144 IOs
XC6SLX45 - 136 IOs
FT2232H - 8 IOs

©2015 NUMATO SYSTEMS PVT LTD www.numato.com

## How to use the module

The following section describes how to use this module.

### Components/Tools required

Along with the module, you may need the items in the list below for easy and fast installation.

1. USB A to Mini B cable.
2. DC Power supply (Optional).

### Connection Diagram

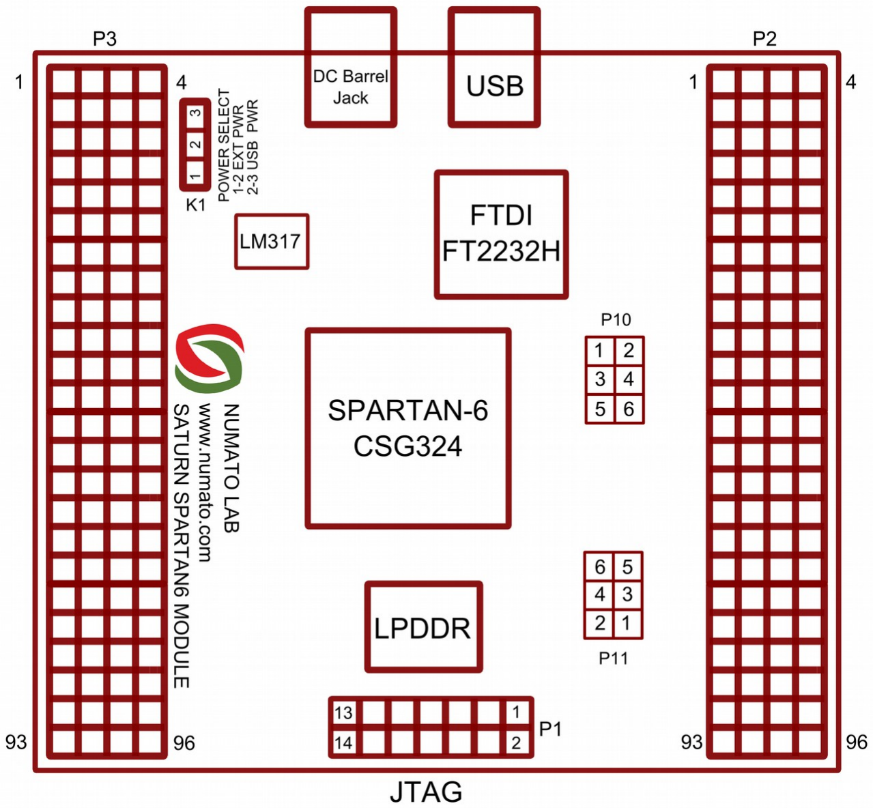
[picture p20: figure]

This diagram should be used as a reference only. For detailed information, see Saturn schematics at the end of this document. Details of individual connectors are as below.

©2015 NUMATO SYSTEMS PVT LTD www.numato.com

## USB Interface

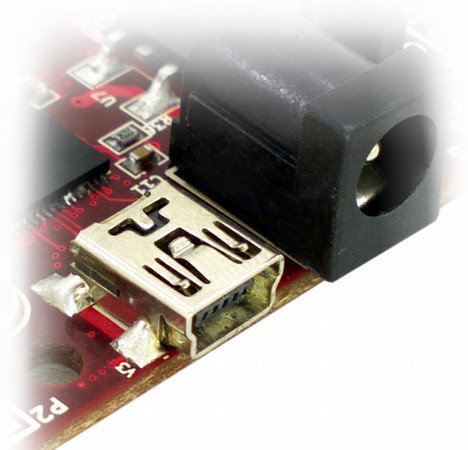
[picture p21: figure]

The on board full speed USB controller helps a PC/Linux/Mac computer to communicate with this module. Use a USB A to Mini B cable to connect with a PC. By default the module is powered from USB so make sure not to overcrowd unpowered USB hubs (the picture on the right shows USB Mini connector).

Visit http://numato.com/cables-accessories to buy cables and accessories for this product.

## DC Power Supply

This module uses +5V power supply to function properly. By default the board is configured to use +5V supply from USB. So an external +5V power is not required unless USB port is unable to supply enough current. In most cases USB ports are capable of providing enough current for the module. Current requirement for this board largely depends on your application. Please consult FPGA data sheet for more details on power requirements. If for any reason, an external 5V power supply needs to be used for the module, the Power select jumper should be configured properly before connecting the power supply. Please refer to the marking
on the board for more details.

## Power Select

The Power Select header K1 is used to configure the power source for the board. The jumper in pin 2 and 3 is shorted to switch the power source to on board USB port and pin 1 and 2 to use the external DC power.

## JTAG Connector

JTAG connector provides access to FPGA's JTAG pins. A XILINX platform cable can be used to for JTAG programming.

©2015 NUMATO SYSTEMS PVT LTD www.numato.com

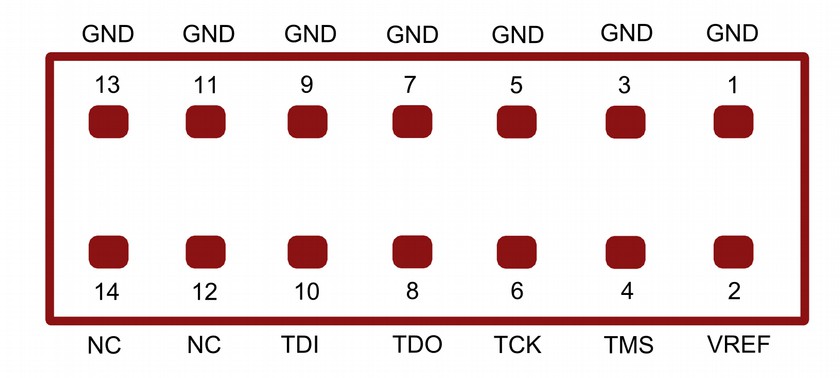
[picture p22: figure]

## JTAG/SPI Configuration on FT2232H channel A

Channel A of FT2232H can be connected to the SPI bus that connects the SPI Flash chip to the FPGA or to the JTAG pins of the FPGA. By connecting SPI bus to FT2232H channel A, the SPI flash can be directly programmed to save the configuration permanently. This is the default configuration set when Saturn is shipped. When FT2232H channel A is connected to SPI, Saturn Configuration Downloader utility can be used to program the board.

When FT2232H channel A is connected to FPGA JTAG, the JTAG signals can be accessed directly through FT2232H. Saturn Configuration Downloader utility currently does not support programming FPGA SRAM through JTAG.

Please see the tables below for information about selecting SPI or JTAG for FT2232H channel A. SPI must be selected for Saturn Configuration Downloader utility to work.
Header P10
Jumber Configration for SPI | Jumber Configration for JTAG
1 - 2 | 2 - 4
5 - 6 | 3 - 5
Header P11
Jumber Configration for SPI | Jumber Configration for JTAG
1 - 2 | 2 - 4
5 - 6 | 3 - 5

©2015 NUMATO SYSTEMS PVT LTD www.numato.com

## GPIOs

This device is equipped with a maximum 158 user IO pins that can be used for various custom applications. Out of 158 user IOs 56 are length matched which can be used as differential pairs. Header P3

Pin No. On The Header | Spartan-6 (CSG324) Pin No. | Pin No. On The Header | Spartan-6 (CSG324) Pin No.
1 | GND | 2 | 3V3
3 | VCCIN | 4 | GND
5 | G13 | 6 | H12
7 | K14 | 8 | J13
9 | H16 | 10 | H15
11 | H14 | 12 | H13
13 | G14 | 14 | F14
15 | G18 | 16 | G16
17 | F16 | 18 | F15
19 | F18 | 20 | F17
21 | E18 | 22 | E16
23 | D18 | 24 | D17
25 | C18 | 26 | C17
27 | A16 | 28 | B16
29 | A15 | 30 | C15
31 | C14 | 32 | D14
33 | A14 | 34 | B14
35 | E13 | 36 | F13
37 | A13 | 38 | C13
39 | E12 | 40 | F12
41 | C12 | 42 | D12
43 | A12 | 44 | B12
45 | E11 | 46 | F11

©2015 NUMATO SYSTEMS PVT LTD www.numato.com

47 | C11 | 48 | D11
49 | GND | 50 | GND
51 | GND | 52 | GND
53 | F10 | 54 | G11
55 | A11 | 56 | B11
57 | A10 | 58 | C10
59 | F9 | 60 | G9
61 | C9 | 62 | D9
63 | A9 | 64 | B9
65 | F8 | 66 | G8
67 | E8 | 68 | E7
69 | C8 | 70 | D8
71 | A8 | 72 | B8
73 | E6 | 74 | F7
75 | A7 | 76 | C7
77 | A6 | 78 | B6
79 | C6 | 80 | D6
81 | A5 | 82 | C5
83 | A4 | 84 | B4
85 | A3 | 86 | B3
87 | A2 | 88 | B2
89 | GND | 90 | GND
91 | GND | 92 | GND
93 | 3V3 | 94 | 3V3
95 | 3V3 | 96 | 3V3
Header P2
Pin No. On The Header | Spartan-6 (CSG324) Pin No. | Pin No. On The Header | Spartan-6 (CSG324) Pin No.
1 | ACBUS0* | 2 | ACBUS1

©2015 NUMATO SYSTEMS PVT LTD www.numato.com

3 | 3V3 | 4 | GND
5 | ACBUS2 | 6 | ACBUS3
7 | K12 | 8 | K13
9 | ACBUS4 | 10 | ACBUS5
11 | L14 | 12 | M13
13 | ACBUS6 | 14 | ACBUS7
15 | M14 | 16 | N14
17 | L12 | 18 | L13
19 | L15 | 20 | L16
21 | K15 | 22 | K16
23 | N15 | 24 | N16
25 | T17 | 26 | T18
27 | P15 | 28 | P16
29 | U16 | 30 | V16
31 | U17 | 32 | U18
33 | T14 | 34 | V14
35 | U15 | 36 | V15
37 | T12 | 38 | V12
39 | U13 | 40 | V13
41 | R11 | 42 | T11
43 | M11 | 44 | N11
45 | GND | 46 | GND
47 | GND | 48 | GND
49 | GND | 50 | GND
51 | GND | 52 | GND
53 | N10 | 54 | P11
55 | U11 | 56 | V11
57 | R10 | 58 | T10
59 | M10 | 60 | N9
61 | T9 | 62 | V9

©2015 NUMATO SYSTEMS PVT LTD www.numato.com

63 | R8 | 64 | T8
65 | N7 | 66 | P8
67 | M8 | 68 | N8
69 | U7 | 70 | V7
71 | U8 | 72 | V8
73 | R7 | 74 | T7
75 | N6 | 76 | P7
77 | N5 | 78 | P6
79 | T6 | 80 | V6
81 | R5 | 82 | T5
83 | U5 | 84 | V5
85 | R3 | 86 | T3
87 | T4 | 88 | V4
89 | INITB | 90 | 3V3
91 | PROGB | 92 | 3V3
93 | GND | 94 | GND
95 | GND | 96 | GND
* ACBUS0 - ACBUS7 are pins of FTDI FT2232H Dual-Channel USB device.

VCC
Ground
GPIO
FTDI IO
No Connect Pins In LX9(CSG324)
SL No. | Pin No On The Header P3 | Spartan-6 (CSG324)
1 | 37 | A13
2 | 38 | C13
3 | 39 | E12
4 | 40 | F12

©2015 NUMATO SYSTEMS PVT LTD www.numato.com

5 | 41 | C12
6 | 42 | D12
7 | 45 | E11
8 | 46 | F11
9 | 53 | F10
10 | 54 | G11
11 | 65 | F8
12 | 66 | G8
13 | 67 | E8
14 | 68 | E7
15 | 73 | E6
16 | 74 | F7
SL No. | Pin No On The Header P2 | Spartan-6 (CSG324)
1 | 35 | U15
2 | 36 | V15
3 | 37 | T12
4 | 38 | V12
5 | 43 | M11
6 | 44 | N11
7 | 53 | N10
8 | 54 | P11
9 | 59 | M10
10 | 60 | N9
11 | 65 | N7
12 | 66 | P8
13 | 67 | M8
14 | 68 | N8
15 | 75 | N6
16 | 76 | P7

©2015 NUMATO SYSTEMS PVT LTD www.numato.com

No Connect Pins In LX25 (CSG324)

SL No. | Pin No On The HeaderP3 | Spartan-6 (CSG324)
1 | 65 | F8
2 | 66 | G8
3 | 67 | E8
4 | 68 | E7
5 | 73 | E6
6 | 74 | F7
No Connect Pins In LX45(CSG324)
SL No. | Pin No On The Header P3 | Spartan-6 (CSG324)
1 | 39 | E12
2 | 40 | F12
3 | 41 | C12
4 | 42 | D12
5 | 45 | E11
6 | 46 | F11
7 | 53 | F10
8 | 54 | G11
9 | 65 | F8
10 | 66 | G8
11 | 67 | E8
12 | 68 | E7
13 | 73 | E6
14 | 74 | F7
FT2232H – Spartan-6 (CSG324) FPGA Connection Details
FTDI Pin No. | Pin Function (245 FIFO) | Spartan-6 Pin No.
38 | D0 | L17
39 | D1 | L18

©2015 NUMATO SYSTEMS PVT LTD www.numato.com

40 | D2 | M16
41 | D3 | M18
43 | D4 | N17
44 | D5 | N18
45 | D6 | P17
46 | D7 | P18
48 | RXF# | K18
52 | TXE# | K17
53 | RD# | J18
54 | WR# | J16
55 | SIWUB | H18

©2015 NUMATO SYSTEMS PVT LTD www.numato.com

## Driver Installation

Windows
This product requires a driver to be installed for proper functioning when used with Windows. The D2XX driver can be downloaded from http://www.ftdichip.com/Drivers/D2XX.htm. Windows Users run the CDM v2.08.30 WHQL Certified.exe application that will prompt to install the FTDI CDM drivers. When driver installation is complete, the module should appear in Saturn Flash Config Tool as Saturn Spartan 6 FPGA Module (see the picture).

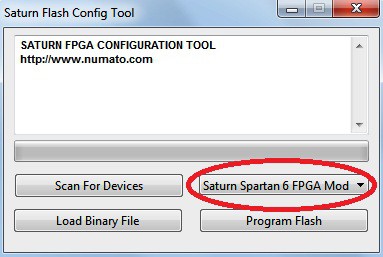
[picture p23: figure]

©2015 NUMATO SYSTEMS PVT LTD www.numato.com

## Generating Bit Stream for Saturn

HDL design needs to be converted to bit stream before it can be programmed to FPGA. Saturn at this
time | accepts | only | binary | (.bin) | bit | stream | created | by | XILINX | ISE
(http://www.xilinx.com/tools/webpack.htm). Once the HDL is synthesized, it is easy to create a binary bit stream out of it. Please follow the steps below to generate binary bit stream from your design using ISE Web Pack.
Step 1: Right click on the “Generate Programming File” option in “Processes” window.

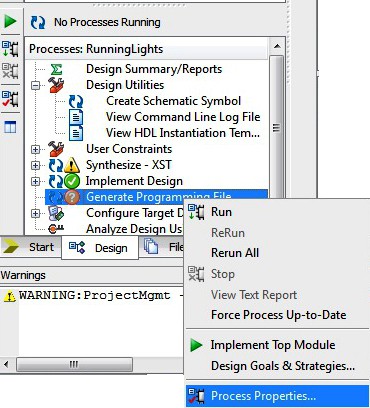
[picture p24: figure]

©2015 NUMATO SYSTEMS PVT LTD www.numato.com

Step 2: Select “Process Properties” from the pop up menu. In the dialog box, check “Create Binary Configuration File” Check box and click “Apply”.


Step 3: Click “OK” to close the dialog box. Right click on “Generate Programming File” option again and select “Run”. Now you will be able to find a “.bin” file in the project directory and that file can be used for Saturn configuration.

©2015 NUMATO SYSTEMS PVT LTD www.numato.com

## Powering Up Saturn

Saturn is factory configured to be powered directly from USB port so make sure that you are using a USB port that can power the board properly. It is recommended to connect the board directly to the PC instead using a hub. It is practically very difficult to estimate the power consumption of the board, as it depends heavily on your design and the clock used. XILINX provides tools to estimate the power consumption. In any case if power from USB is not enough for your application, external supply can be applied to the board. Jumper PWRSEL should be set up properly (short pin 1-2) to use the board on external power. Saturn requires three different voltages, a 3.3V, a 1.8V supplies and a 1.3V supply. On-board regulators derive these voltages from the USB/Ext power supply.

©2015 NUMATO SYSTEMS PVT LTD www.numato.com

Configuring Saturn Spartan6 Module

The Saturn Spartan6 module can be configured by two methods,

a) Using Spartan configuration tool through USB.
b) Using the Xilinx programming cable.

Configuring Saturn using configuration tool

Saturn has an on-board FTDI FT2232 device which facilitates easy reprogramming of on-board SPI flash through USB interface. The FTDI receives bit stream from the host application and program it in to the SPI Flash and lets the FPGA boot from the flash. The Saturn configuration application can be downloaded from www.numato.com for free.

Step 1: Open Saturn Config Tool. Click “Scan for Devices” if “Saturn Spartan 6 FPGA Module” is not detected automatically.


©2015 NUMATO SYSTEMS PVT LTD www.numato.com

Step 2: Click on “Load Binary” Select the “.bin” file, then click on “Program Flash” button. Wait till “Programming Completed” appears on the screen.


©2015 NUMATO SYSTEMS PVT LTD www.numato.com

## Configuring Saturn using JTAG

Saturn Spartan6 module features an on-board JTAG connector which facilitates easy reprogramming of SRAM and on-board SPI flash through JTAG programmer like “XILINX Platform-cable usb”. Programming Saturn using JTAG requires “XILINX ISE iMPACT” software which is bundled with XILINX ISE Design Suite. To program the SPI flash we need a ".mcs" file needs to be generated from the ".bit" file. Steps for generating ".mcs" file are as below. Programming FPGA SRAM does not require a “.mcs” file to be generated.
Generating ".mcs" file for Saturn
Step 1: Open ISE iMPACT. Click on “Create PROM file(PROM file formatter)”. In the dialog box, select “Configure Single FPGA” in storage device type. Then click on the green arrow on the right side.


©2015 NUMATO SYSTEMS PVT LTD www.numato.com

Step 2: Select 128M in Storage Device (bits).Now click on “Add Storage Device”, then the green arrow on the right side.


Step 3: Set an output file name and the output file location (the ".mcs" file will be generated at this location which will be required later for programming the FPGA), then click OK twice, then select the “.bit” file we already generated then click Open and click NO when it prompts to add another device file.


©2015 NUMATO SYSTEMS PVT LTD www.numato.com

Step 4: Double click on “Generate File”. “Generate Succeeded” will be displayed as shown in fig below if the “.mcs” the file is generated successfully.


©2015 NUMATO SYSTEMS PVT LTD www.numato.com

## Programming FPGA using ISE iMPACT

Step 1: Open ISE iMPACT. Click on “Boundary Scan” in the iMPACT flows window on the left top corner. Then right click on the window panel on the right. Select “Initialize Chain”.


©2015 NUMATO SYSTEMS PVT LTD www.numato.com


Step 2: If the device is detected properly you will get a pop up window as shown below, Click OK. Then right click on the SPI/BPI (next to the black arrow in the below fig.), select Add SPI/BPI Flash.
Step 3: Select the ".mcs" file we already created and click OK. Now choose “N25Q128” in the dialogue box appeared, then click OK.

©2015 NUMATO SYSTEMS PVT LTD www.numato.com

Step 4. Click on “Flash”, Double Click on Program, select OK. If the programming is successful, a confirmation message will be displayed.


©2015 NUMATO SYSTEMS PVT LTD www.numato.com

## Length matched GPIOs Pairs

This device is equipped with a maximum of 158 user IOs. Of those, 45 IO pairs are length matched which can be used as differential pairs.

Pin No. on the Header P3 | Spartan-6 Differential Pair
9-10 | H15-H16
17-18 | F16-F15
19-20 | F17-F18
21-22 | E16-E18
23-24 | D17-D18
25-26 | C17-C18
27-28 | B16-A16
31-32 | C14-D14
33-34 | B14-A14
37-38 | C13-A13
41-42 | D12-C12
43-44 | B12-A12
47-48 | D11-C11
53-54 | G11-F10
55-56 | B11-A11
57-58 | C10-A10
59-60 | F9-G9
61-62 | D9-C9
63-64 | B9-A9
69-70 | D8-C8
71-72 | B8-A8

©2015 NUMATO SYSTEMS PVT LTD www.numato.com

75-76 | C7-A7
77-78 | B6-A6
79-80 | C6-D6
81-82 | C5-A5
83-84 | A4-B4
85-86 | B3-A3
87-88 | B2-A2
Pin No. on the Header P2 | Spartan-6 Differential Pair
7-8 | K13-K12
17-18 | L12-L13
19-20 | L15-L16
21-22 | K15-K16
23-24 | N15-N16
33-34 | T14-V14
57-58 | R10-T10
61-62 | T9-V9
63-64 | R8-T8
69-70 | U7-V7
71-72 | U8-V8
73-74 | R7-T7
79-80 | T6-V6
81-82 | R5-T5
83-84 | U5-V5
85-86 | R3-T3
87-88 | T4-V4

©2015 NUMATO SYSTEMS PVT LTD www.numato.com

## Technical Specifications

Parameter * | Value | Unit
Basic Specifications
Number of GPIOs | 158 (Max)
On-board oscillator frequency (FXO-HC536R) | 100 | MHz
LPDDR Capacity | 512 | Mb
LPDDR Clock | 166 | MHz
SPI Flash Memory (N25Q128A13ESE40E) | 128 | Mb
Power supply voltage (USB or external) | 5 – 6 | V
FPGA Specifications
Internal supply voltage relative to GND | –0.5 to 1.32 | V
Auxiliary supply voltage relative to GND | –0.5 to 3.75 | V
Output drivers supply voltage relative to GND | –0.5 to 3.75 | V
* | All parameters considered nominal. Numato Systems Pvt Ltd reserve the right to modify products without notice.

©2015 NUMATO SYSTEMS PVT LTD www.numato.com

## Physical Dimensions


### Schematics

See next page.

©2015 NUMATO SYSTEMS PVT LTD www.numato.com

# ram.sch DDR-D[0..15]

# DDR-RAS DDR-BA0 DDR-BA1 DDR-UDQS

C Date: 15 apr 2014; Size: A4; Rev:; POWER; power.sch; GPIOS; gpios.sch; GPIO-P[1..82]; GPIO-N[1..82]; FTDI-AC[0..7]; INITB PROGB; RAM; DDR-LDM; DDR-CK_P DDR-CK_N; RZQ; SPARTAN6; spartan6.sch; DDR-RAS DDR-CAS; DDR-LDQS; PROGB; INITB; TMS TCK; TDO; TDI FT2232H; POWER SUPPLY; GPIOs; SPARTAN 6 FPGA CSG324; FTDI2232H; ftdi.sch; U1-SCK; U1-SDO U1-SDI U1-CS; TMS TCK TDI TDO

U1-SCK
U1-SDO
U1-SDI
DDR-UDQS U1-RXF# U1-TXE# U1-RD# U1-WR# U1-SIWUB

DDR-D[0..15]
DDR-A[0..12] DDR-UDM

DDR-LDQS
LPDDR
DDR-CKE DDR-WE DDR-CAS

DDR-CK_P
DDR-CK_N
DDR-BA0 DDR-BA1 DDR-WE DDR-CKE

U1-D[0..7] U1-RXF# U1-TXE# U1-RD# U1-WR# U1-SIWUB

License: CC BY-SA
http://www.numato.com
File: saturn.sch Sheet: / Numato Lab

Title: SATURN SPARTAN6 FPGA MODULE
KiCad E.D.A.

## LM1117 ADJ 1

## LM1117ADJ 1


License: CC BY-SA ADJ 1

http://www.numato.com
Sheet: /POWER/ Numato Lab
File: power.sch

Title: SATURN SPARTAN6 FPGA MODULE
KiCad E.D.A.


License: CC BY-SA
http://www.numato.com
Sheet: /GPIOS/ Numato Lab
File: gpios.sch

Title: SATURN SPARTAN6 FPGA MODULE
KiCad E.D.A.


DDR-UDQS
DDR-LDQS DDR-UDM

DDR-CKE DDR-WE DDR-CAS

http://www.numato.com
File: ram.sch Sheet: /RAM/ Numato Lab

Title: SATURN SPARTAN6 FPGA MODULE
KiCad E.D.A.

# IO_L45P_M3A3_3 L7 U5D

DDR-D0 DDR-D1 DDR-D2 DDR-D3 DDR-D4 DDR-D5 DDR-D6 DDR-D7 DDR-D8 DDR-D9 DDR-D10 DDR-D11 DDR-D12 DDR-D13 DDR-D14 DDR-D15 DDR-D[0..15]


U1-SDI
U1-SDO
GPIO-P60 GPIO-P61 GPIO-P62 GPIO-P63 GPIO-P64 GPIO-P65 GPIO-P66 GPIO-P67 GPIO-P68 GPIO-P69 GPIO-P70 GPIO-P71 GPIO-P72 GPIO-P73 GPIO-P74 GPIO-P75 GPIO-P76 GPIO-P77 GPIO-P78 GPIO-P79 GPIO-P80 GPIO-P81 GPIO-P82
GPIO-N60 GPIO-N61 GPIO-N62 GPIO-N63 GPIO-N64 GPIO-N65 GPIO-N66 GPIO-N67 GPIO-N68 GPIO-N69 GPIO-N70 GPIO-N71 GPIO-N72 GPIO-N73 GPIO-N74 GPIO-N75 GPIO-N76 GPIO-N77 GPIO-N78 GPIO-N79 GPIO-N80 GPIO-N81 GPIO-N82

DDR-LDQS DDR-UDM
DDR-A0 DDR-A1 DDR-A2 DDR-A3 DDR-A4 DDR-A5 DDR-A6 DDR-A7 DDR-A8 DDR-A9 DDR-A10 DDR-A11 DDR-A12 DDR-A[0..12]

GCLK2
INIT_B U1-D0 U1-D1 U1-D2 U1-D3 U1-D4 U1-D5 U1-D6 U1-D7 U1-RXF# U1-TXE# U1-RD# U1-WR# U1-SIWUB

License: CC BY-SA
http://www.numato.com
Sheet: /SPARTAN6/ Numato Lab
File: spartan6.sch

Title: SATURN SPARTAN6 FPGA MODULE
KiCad E.D.A.

# R5 12K R6 4K7 VCC1V8 C12


9 AGND 10 VCCIO 20 ACBUS4 30 BDBUS2 40 VREGIN 50 PWREN 60 GND 11 ADBUS4 21 VCCIO 31 BDBUS3 41 GND 51 EEDATA 61 VCORE 12 ADBUS5 22 ACBUS5 32 VCCIO 42 BCBUS1 52 EECLK 62 TEST 13 ADBUS6 23 ACBUS6 33 BDBUS4 43 BCBUS2 53 EECS 63 RESET 14 ADBUS7 24 ACBUS7 34 BDBUS5 44 BCBUS3 54 VCORE 64 GND 15 GND 25 GND 35 BDBUS6 45 BCBUS4 55 ADBUS0 16 ACBUS0 26 SUSPEND 36 BDBUS7 46 VCCIO 56 ADBUS1 17 ACBUS1 27 VCORE 37 GND 47 BCBUS5 57 ADBUS2 18 ACBUS2 28 BDBUS0 38 BCBUS0 48 BCBUS6 58 ADBUS3 19 ACBUS3 29 BDBUS1 39 VREGOUT 49 BCBUS7 59 U2 FT2232H VCC3V3

Jumper on - J1,J2,J3,J4 - JTAG COMMUNICATION
Jumper on - S1,S2,S3,S4 - SPI COMMUNICATION

5 REF 6 DM 7 DP 8 VPLL

EEPROM FOR FT2232H R¹ 10K EEDATA

http://www.numato.com
File: ftdi.sch Sheet: /FTDI2232H/ Numato Lab

Title: SATURN SPARTAN6 FPGA MODULE
KiCad E.D.A.

Saturn V4 GPIO Easy Reference

HEADER P3


Pin No. On The Header | Spartan-6 (CSG324) Pin No. | Pin Description | Pin No. On The Header | Spartan-6 (CSG324) Pin No. | Pin Description | Pin No. On The Header | Spartan-6 (CSG324) Pin No. | Pin Description | Pin No. On The Header | Spartan-6 (CSG324) Pin No. | Pin Description
1 | GND | NA | 2 | 3V3 | NA | 3 | VCCIN | NA | 4 | GND | NA
5 | G13 | IO_L32N_A16_M1A9_1 | 6 | H12 | IO_L32P_A17_M1A8_1 | 7 | K14 | IO_L39N_M1ODT_1 | 8 | J13 | IO_L39P_M1A3_1
9 | H16 | IO_L37N_A6_M1A1_1 | 10 | H15 | IO_L37P_A7_M1A0_1 | 11 | H14 | IO_L36N_A8_M1BA1_1 | 12 | H13 | IO_L36P_A9_M1BA0_1
13 | G14 | IO_L30N_A20_M1A11_1 | 14 | F14 | IO_L30P_A21_M1RESET_1 | 15 | G18 | IO_L38N_A4_M1CLKN_1 | 16 | G16 | IO_L38P_A5_M1CLK_1
17 | F16 | IO_L1N_A24_VREF_1 | 18 | F15 | IO_L1P_A25_1 | 19 | F18 | IO_L35N_A10_M1A2_1 | 20 | F17 | IO_L35P_A11_M1A7_1
21 | E18 | IO_L33N_A14_M1A4_1 | 22 | E16 | IO_L33P_A15_M1A10_1 | 23 | D18 | IO_L31N_A18_M1A12_1 | 24 | D17 | IO_L31P_A19_M1CKE_1
25 | C18 | IO_L29N_A22_M1A14_1 | 26 | C17 | IO_L29P_A23_M1A13_1 | 27 | A16 | IO_L66N_SCP0_0 | 28 | B16 | IO_L66P_SCP1_0
29 | A15 | IO_L64N_SCP4_0 | 30 | C15 | IO_L64P_SCP5_0 | 31 | C14 | IO_L65N_SCP2_0 | 32 | D14 | IO_L65P_SCP3_0
33 | A14 | IO_L62N_VREF_0 | 34 | B14 | IO_L62P_0 | 35 | E13 | IO_L63N_SCP6_0 | 36 | F13 | IO_L63P_SCP7_0
37 | A13 | IO_L50N_0 | 38 | C13 | IO_L50P_0 | 39 | E12 | IO_L51N_0 | 40 | F12 | IO_L51P_0
41 | C12 | IO_L47N_0 | 42 | D12 | IO_L47P_0 | 43 | A12 | IO_L41N_0 | 44 | B12 | IO_L41P_0
45 | E11 | IO_L42N_0 | 46 | F11 | IO_L42P_0 | 47 | C11 | IO_L36N_GCLK14_0 | 48 | D11 | IO_L36P_GCLK15_0
49 | GND | NA | 50 | GND | NA | 51 | GND | NA | 52 | GND | NA
53 | F10 | IO_L40N_0 | 54 | G11 | IO_L40P_0 | 55 | A11 | IO_L39N_0 | 56 | B11 | IO_L39P_0
57 | A10 | IO_L37N_GCLK12_0 | 58 | C10 | IO_L37P_GCLK13_0 | 59 | F9 | IO_L38N_VREF_0 | 60 | G9 | IO_L38P_0
61 | C9 | IO_L34N_GCLK18_0 | 62 | D9 | IO_L34P_GCLK19_0 | 63 | A9 | IO_L35N_GCLK16_0 | 64 | B9 | IO_L35P_GCLK17_0
65 | F8 | IO_L32N_0 | 66 | G8 | IO_L32P_0 | 67 | E8 | IO_L9N_0 | 68 | E7 | IO_L9P_0
69 | C8 | IO_L11N_0 | 70 | D8 | IO_L11P_0 | 71 | A8 | IO_L33N_0 | 72 | B8 | IO_L33P_0
73 | E6 | IO_L7N_0 | 74 | F7 | IO_L7P_0 | 75 | A7 | IO_L10N_0 | 76 | C7 | IO_L10P_0
77 | A6 | IO_L8N_VREF_0 | 78 | B6 | IO_L8P_0 | 79 | C6 | IO_L3N_0 | 80 | D6 | IO_L3P_0
81 | A5 | IO_L6N_0 | 82 | C5 | IO_L6P_0 | 83 | A4 | IO_L5N_0 | 84 | B4 | IO_L5P_0
85 | A3 | IO_L4N_0 | 86 | B3 | IO_L4P_0 | 87 | A2 | IO_L2N_0 | 88 | B2 | IO_L2P_0
89 | GND | NA | 90 | GND | NA | 91 | GND | NA | 92 | GND | NA
93 | 3V3 | NA | 94 | 3V3 | NA | 95 | 3V3 | NA | 96 | 3V3 | NA

HEADER P2

Pin No. On The Header | Spartan-6 (CSG324) Pin No. | Pin Description | Pin No. On The Header | Spartan-6 (CSG324) Pin No. | Pin Description | Pin No. On The Header | Spartan-6 (CSG324) Pin No. | Pin Description | Pin No. On The Header | Spartan-6 (CSG324) Pin No. | Pin Description
1 | FTDI-26 | ACBUS0 | 2 | FTDI-27 | ACBUS1 | 3 | 3V3 | NA | 4 | GND | NA
5 | FTDI-28 | ACBUS2 | 6 | FTDI-29 | ACBUS3 | 7 | K12 | IO_L34P_A13_M1WE_1 | 8 | K13 | IO_L34N_A12_M1BA2_1
9 | FTDI-30 | ACBUS4 | 10 | FTDI-32 | ACBUS5 | 11 | L14 | IO_L61P_1 | 12 | M13 | IO_L61N_1
13 | FTDI-33 | ACBUS6 | 14 | FTDI-34 | ACBUS7 | 15 | M14 | IO_L53P_1 | 16 | N14 | IO_L53N_VREF_1
17 | L12 | IO_L40P_GCLK11_M1A5_1 | 18 | L13 | IO_L40N_GCLK10_M1A6_1 | 19 | L15 | IO_L42P_GCLK7_M1UDM_1 | 20 | L16 | IO_L42N_GCLK6_TRDY1_M1LDM_1
21 | K15 | IO_L41P_GCLK9_IRDY1_M1RASN_1 | 22 | K16 | IO_L41N_GCLK8_M1CASN_1 | 23 | N15 | IO_L50P_M1UDQS_1 | 24 | N16 | IO_L50N_M1UDQSN_1
25 | T17 | IO_L51P_M1DQ12_1 | 26 | T18 | IO_L51N_M1DQ13_1 | 27 | P15 | IO_L74P_AWAKE_1 | 28 | P16 | IO_L74N_DOUT_BUSY_1
29 | U16 | IO_L2P_CMPCLK_2 | 30 | V16 | IO_L2N_CMPMOSI_2 | 31 | U17 | IO_L52P_M1DQ14_1 | 32 | U18 | IO_L52N_M1DQ15_1
33 | T14 | IO_L12P_D1_MISO2_2 | 34 | V14 | IO_L12N_D2_MISO3_2 | 35 | U15 | IO_L5P_2 | 36 | V15 | IO_L5N_2
37 | T12 | IO_L19P_2 | 38 | V12 | IO_L19N_2 | 39 | U13 | IO_L14P_D11_2 | 40 | V13 | IO_L14N_D12_2
41 | R11 | IO_L16P_2 | 42 | T11 | IO_L16N_VREF_2 | 43 | M11 | IO_L15P_2 | 44 | N11 | IO_L15N_2
45 | GND | NA | 46 | GND | NA | 47 | GND | NA | 48 | GND | NA
49 | GND | NA | 50 | GND | NA | 51 | GND | NA | 52 | GND | NA
53 | N10 | IO_L20P_2 | 54 | P11 | IO_L20N_2 | 55 | U11 | IO_L23P_2 | 56 | V11 | IO_L23N_2
57 | R10 | IO_L29P_GCLK3_2 | 58 | T10 | IO_L29N_GCLK2_2 | 59 | M10 | IO_L22P_2 | 60 | N9 | IO_L22N_2
61 | T9 | IO_L32P_GCLK29_2 | 62 | V9 | IO_L32N_GCLK28_2 | 63 | R8 | IO_L31P_GCLK31_D14_2 | 64 | T8 | IO_L31N_GCLK30_D15_2
65 | N7 | IO_L44P_2 | 66 | P8 | IO_L44N_2 | 67 | M8 | IO_L40P_2 | 68 | N8 | IO_L40N_2
69 | U7 | IO_L43P_2 | 70 | V7 | IO_L43N_2 | 71 | U8 | IO_L41P_2 | 72 | V8 | IO_L41N_VREF_2
73 | R7 | IO_L46P_2 | 74 | T7 | IO_L46N_2 | 75 | N6 | IO_L47P_2 | 76 | P7 | IO_L47N_2
77 | N5 | IO_L64P_D8_2 | 78 | P6 | IO_L64N_D9_2 | 79 | T6 | IO_L45P_2 | 80 | V6 | IO_L45N_2
81 | R5 | IO_L48P_D7_2 | 82 | T5 | IO_L48N_RDWR_B_VREF_2 | 83 | U5 | IO_L49P_D3_2 | 84 | V5 | IO_L49N_D4_2
85 | R3 | IO_L62P_D5_2 | 86 | T3 | IO_L62N_D6_2 | 87 | T4 | IO_L63P_2 | 88 | V4 | IO_L63N_2
89 | U3 | IO_L65P_INIT_B_2 | 90 | 3V3 | NA | 91 | V2 | PROGRAM_B_2 | 92 | 3V3 | NA
93 | GND | NA | 94 | GND | NA | 95 | GND | NA | 96 | GND | NA

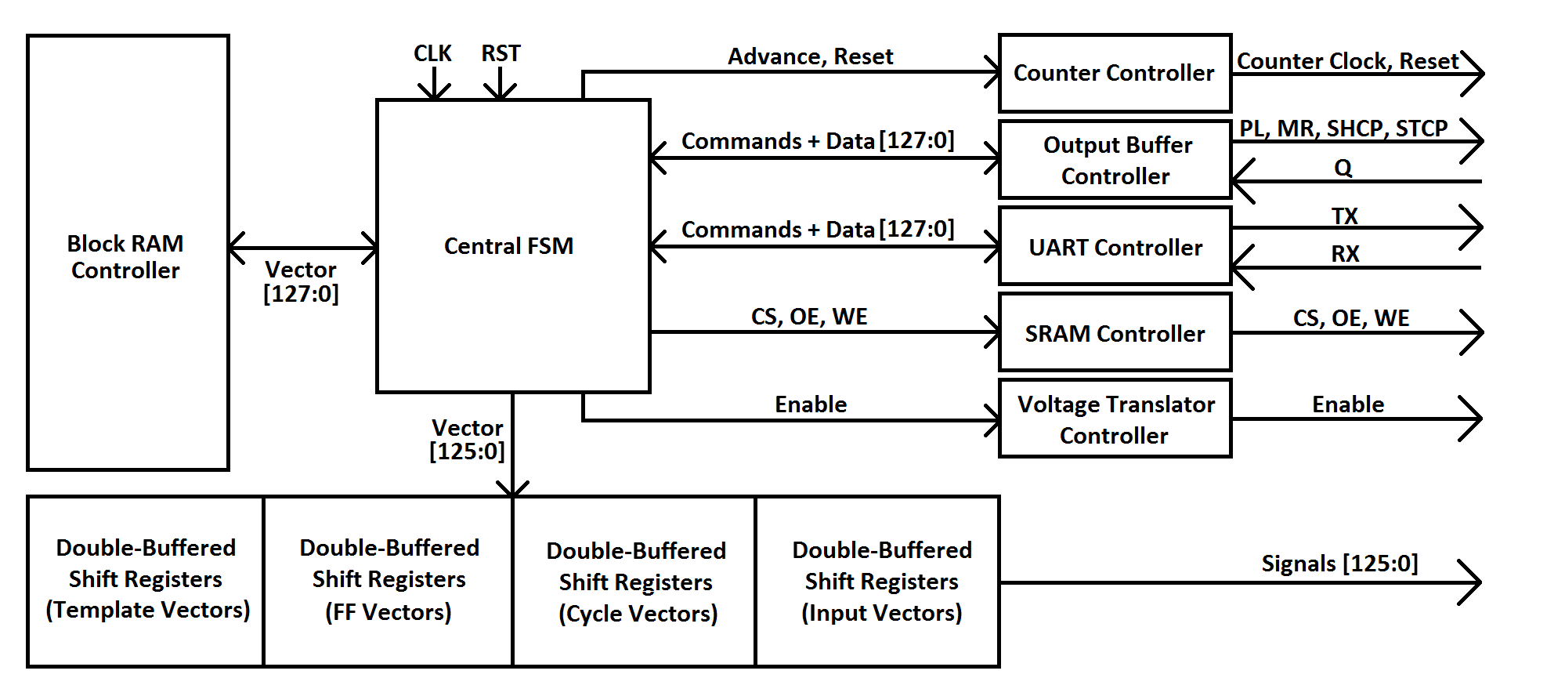
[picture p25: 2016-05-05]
users_manual/images/verilog_schematic.png

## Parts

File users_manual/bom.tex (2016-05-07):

\section{Bill of Materials}

To reconstruct our system costs about \textbf{\$660.51}. Parts that end with * mean that shipping charges are included in the price per unit. Unit prices do not include bulk discounts.

% This list isn't going to change so I'm just computing the numbers off-hand. Also there are better ways to specify the column widths but meh.

\begin{flushleft}
\textbf{PCBs and Development Boards:}
\end{flushleft}
\begin{center}
    \begin{tabular}{| p{0.213\textwidth} | p{0.142\textwidth} | p{0.142\textwidth} | p{0.142\textwidth} | p{0.071\textwidth} | p{0.142\textwidth} |}
    \hline
    Part & Desc. & Supplier & Unit \$ & Amt & Total \$ \\ \hline
    2-Layer PCB* & Comm. Board & Advanced Circuits & 52.80 & 1 & 52.80 \\ \hline
    4-Layer PCB* & Numato Shield, DUT Board & Advanced Circuits & 85.80 & 2 & 171.00 \\ \hline
    BeagleBone Black Rev C* & Web Server & SparkFun & 60.30 & 1 & 60.30 \\ \hline
    Saturn V9* & Spartan-6 FPGA Development Board & Numato & 91.96 & 1 & 91.96 \\ \hline
    \end{tabular}
\end{center}
\textbf{Total cost of PCBs and Development Boards: \$376.06}

\pagebreak

\begin{flushleft}
\textbf{PCB Components:}

Note: We estimate shipping costs as 10 percent of the total cost of all these parts.
\end{flushleft}
\begin{center}
    \begin{tabular}{| p{0.213\textwidth} | p{0.142\textwidth} | p{0.142\textwidth} | p{0.142\textwidth} | p{0.071\textwidth} | p{0.142\textwidth} |}
    \hline
    Part & Desc. & Supplier & Unit \$ & Amt & Total \$ \\ \hline
    200-6313-9UN-1900 & ZIF Socket & Digikey & 44.25 & 1 & 44.25 \\ \hline
    74HC597PW & Output Buffer & Digikey & 0.512 & 16 & 8.19 \\ \hline
    74VHC4040FT & Counter & Digikey & 0.54 & 4 & 2.16 \\ \hline
    AD5293 & Digital Pot & Digikey & 6.31 & 2 & 12.62 \\ \hline
    IDT71V016SA & SRAM & Digikey & 2.71 & 1 & 21.68 \\ \hline
    MAX3004 & Low-to-High Level Shifter & Digikey & 3.012 & 16 & 48.19 \\ \hline
    MAX3012 & High-to-Low Level Shifter & Digikey & 3.012 & 16 & 48.19 \\ \hline
    LM317KTTR & Adjustable Voltage Regulator & Digikey & 0.93 & 2 & 1.86 \\ \hline
    LM321MFX & Op. Amps & Digikey & 0.573 & 1 & 2.92 \\ \hline
    PJ-002AH-SMT-TR & Barrel Jack Connectors & Digikey & 1.89 & 2 & 3.78 \\ \hline
    2x20 Headers & Extra-Tall, Female, SMT & Adafruit & 2.95 & 20 & 59.00 \\ \hline
    Miscellaneous & 0603, Headers, Wall Warts, etc. & Adafruit, Amazon, Digikey & N/A & N/A & Roughly 50.00 \\ \hline
    \end{tabular}
\end{center}
\begin{flushleft}
\textbf{Total cost (with estimated shipping): \$284.45}
\end{flushleft}

\newpage

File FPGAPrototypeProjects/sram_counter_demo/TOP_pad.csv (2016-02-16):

#Release 14.7 - par P.20131013 (nt64)
#Copyright (c) 1995-2013 Xilinx | Inc. All rights reserved.
#Mon Feb 15 17:32:03 2016
#
## NOTE: This file is designed to be imported into a spreadsheet program
# such as Microsoft Excel for viewing | printing and sorting. The
# character is used as the data field separator. This file is also designed
# to support parsing.
#
#INPUT FILE: TOP_map.ncd
#OUTPUT FILE: TOP_pad.csv
#PART TYPE: xc7a100t
#SPEED GRADE: -3
#PACKAGE: csg324
#
# Pinout by Pin Number:
#
# ----- | ----- | ----- | ----- | ----- | ----- | ----- | ----- | ----- | ----- | ----- | ----- | ----- | ----- | -----
Pin Number | Signal Name | Pin Usage | Pin Name | Direction | IO Standard | IO Bank Number | Drive (mA) | Slew Rate | Termination | IOB Delay | Voltage | Constraint | IO Register | Signal Integrity
A1 |  | IOB33S | IO_L9N_T1_DQS_AD7N_35 | UNUSED |  | 35
A2 |  |  | GND
A3 |  | IOB33S | IO_L8N_T1_AD14N_35 | UNUSED |  | 35
A4 |  | IOB33M | IO_L8P_T1_AD14P_35 | UNUSED |  | 35
A5 |  | IOB33S | IO_L3N_T0_DQS_AD5N_35 | UNUSED |  | 35
A6 |  | IOB33M | IO_L3P_T0_DQS_AD5P_35 | UNUSED |  | 35
A7 |  |  | VCCO_35 |  |  | 35 |  |  |  |  | 3.30
A8 |  | IOB33S | IO_L12N_T1_MRCC_16 | UNUSED |  | 16
A9 |  | IOB33S | IO_L14N_T2_SRCC_16 | UNUSED |  | 16
A10 |  | IOB33M | IO_L14P_T2_SRCC_16 | UNUSED |  | 16
A11 |  | IOB33S | IO_L4N_T0_15 | UNUSED |  | 15
A12 |  |  | GND
A13 |  | IOB33M | IO_L9P_T1_DQS_AD3P_15 | UNUSED |  | 15
A14 |  | IOB33S | IO_L9N_T1_DQS_AD3N_15 | UNUSED |  | 15
A15 |  | IOB33M | IO_L8P_T1_AD10P_15 | UNUSED |  | 15
A16 |  | IOB33S | IO_L8N_T1_AD10N_15 | UNUSED |  | 15
A17 |  |  | VCCO_15 |  |  | 15 |  |  |  |  | 3.30
A18 |  | IOB33S | IO_L10N_T1_AD11N_15 | UNUSED |  | 15
B1 |  | IOB33M | IO_L9P_T1_DQS_AD7P_35 | UNUSED |  | 35
B2 |  | IOB33S | IO_L10N_T1_AD15N_35 | UNUSED |  | 35
B3 |  | IOB33M | IO_L10P_T1_AD15P_35 | UNUSED |  | 35
B4 |  | IOB33S | IO_L7N_T1_AD6N_35 | UNUSED |  | 35
B5 |  |  | GND
B6 |  | IOB33S | IO_L2N_T0_AD12N_35 | UNUSED |  | 35
B7 |  | IOB33M | IO_L2P_T0_AD12P_35 | UNUSED |  | 35
B8 |  | IOB33M | IO_L12P_T1_MRCC_16 | UNUSED |  | 16
B9 |  | IOB33S | IO_L11N_T1_SRCC_16 | UNUSED |  | 16
B10 |  |  | VCCO_16 |  |  | 16 |  |  |  |  | any******
B11 |  | IOB33M | IO_L4P_T0_15 | UNUSED |  | 15
B12 |  | IOB33S | IO_L3N_T0_DQS_AD1N_15 | UNUSED |  | 15
B13 | CHIP1_DATA<0> | IOB33 | IO_L2P_T0_AD8P_15 | BIDIR | LVCMOS33 | 15 | 12 | SLOW |  | NONE |  | LOCATED | NO | NONE
B14 |  | IOB33S | IO_L2N_T0_AD8N_15 | UNUSED |  | 15
B15 |  |  | GND
B16 |  | IOB33M | IO_L7P_T1_AD2P_15 | UNUSED |  | 15
B17 |  | IOB33S | IO_L7N_T1_AD2N_15 | UNUSED |  | 15
B18 |  | IOB33M | IO_L10P_T1_AD11P_15 | UNUSED |  | 15
C1 |  | IOB33S | IO_L16N_T2_35 | UNUSED |  | 35
C2 |  | IOB33M | IO_L16P_T2_35 | UNUSED |  | 35
C3 |  |  | VCCO_35 |  |  | 35 |  |  |  |  | 3.30
C4 |  | IOB33M | IO_L7P_T1_AD6P_35 | UNUSED |  | 35
C5 |  | IOB33S | IO_L1N_T0_AD4N_35 | UNUSED |  | 35
C6 |  | IOB33M | IO_L1P_T0_AD4P_35 | UNUSED |  | 35
C7 |  | IOB33S | IO_L4N_T0_35 | UNUSED |  | 35
C8 |  |  | GND
C9 |  | IOB33M | IO_L11P_T1_SRCC_16 | UNUSED |  | 16
C10 |  | IOB33S | IO_L13N_T2_MRCC_16 | UNUSED |  | 16
C11 |  | IOB33M | IO_L13P_T2_MRCC_16 | UNUSED |  | 16
C12 |  | IOB33M | IO_L3P_T0_DQS_AD1P_15 | UNUSED |  | 15
C13 |  |  | VCCO_15 |  |  | 15 |  |  |  |  | 3.30
C14 |  | IOB33S | IO_L1N_T0_AD0N_15 | UNUSED |  | 15
C15 |  | IOB33S | IO_L12N_T1_MRCC_15 | UNUSED |  | 15
C16 |  | IOB33M | IO_L20P_T3_A20_15 | UNUSED |  | 15
C17 | CHIP2_DATA<1> | IOB33 | IO_L20N_T3_A19_15 | BIDIR | LVCMOS33 | 15 | 12 | SLOW |  | NONE |  | LOCATED | NO | NONE
C18 |  |  | GND
D1 |  |  | GND
D2 |  | IOB33S | IO_L14N_T2_SRCC_35 | UNUSED |  | 35
D3 |  | IOB33S | IO_L12N_T1_MRCC_35 | UNUSED |  | 35
D4 |  | IOB33S | IO_L11N_T1_SRCC_35 | UNUSED |  | 35
D5 |  | IOB33M | IO_L11P_T1_SRCC_35 | UNUSED |  | 35
D6 |  |  | VCCO_35 |  |  | 35 |  |  |  |  | 3.30
D7 |  | IOB33S | IO_L6N_T0_VREF_35 | UNUSED |  | 35
D8 |  | IOB33M | IO_L4P_T0_35 | UNUSED |  | 35
D9 |  | IOB33S | IO_L6N_T0_VREF_16 | UNUSED |  | 16
D10 |  | IOB33S | IO_L19N_T3_VREF_16 | UNUSED |  | 16
D11 |  |  | GND
D12 |  | IOB33M | IO_L6P_T0_15 | UNUSED |  | 15
D13 |  | IOB33S | IO_L6N_T0_VREF_15 | UNUSED |  | 15
D14 |  | IOB33M | IO_L1P_T0_AD0P_15 | UNUSED |  | 15
D15 |  | IOB33M | IO_L12P_T1_MRCC_15 | UNUSED |  | 15
D16 |  |  | VCCO_15 |  |  | 15 |  |  |  |  | 3.30
D17 | CHIP1_DATA<2> | IOB33 | IO_L16N_T2_A27_15 | BIDIR | LVCMOS33 | 15 | 12 | SLOW |  | NONE |  | LOCATED | NO | NONE
D18 | CHIP2_DATA<2> | IOB33 | IO_L21N_T3_DQS_A18_15 | BIDIR | LVCMOS33 | 15 | 12 | SLOW |  | NONE |  | LOCATED | NO | NONE
E1 |  | IOB33S | IO_L18N_T2_35 | UNUSED |  | 35
E2 |  | IOB33M | IO_L14P_T2_SRCC_35 | UNUSED |  | 35
E3 | CLK | IOB33 | IO_L12P_T1_MRCC_35 | INPUT | LVCMOS33 | 35 |  |  |  | NONE |  | LOCATED | NO | NONE
E4 |  |  | GND
E5 |  | IOB33S | IO_L5N_T0_AD13N_35 | UNUSED |  | 35
E6 |  | IOB33M | IO_L5P_T0_AD13P_35 | UNUSED |  | 35
E7 |  | IOB33M | IO_L6P_T0_35 | UNUSED |  | 35
E8 |  |  | VCCBATT_0
E9 |  |  | CCLK_0
E10 |  |  | TCK_0
E11 |  |  | TDI_0
E12 |  |  | TMS_0
E13 |  |  | TDO_0
E14 |  |  | GND
E15 |  | IOB33M | IO_L11P_T1_SRCC_15 | UNUSED |  | 15
E16 | RST | IOB33 | IO_L11N_T1_SRCC_15 | INPUT | LVCMOS33 | 15 |  |  |  | NONE |  | LOCATED | NO | NONE
E17 | CHIP1_DATA<3> | IOB33 | IO_L16P_T2_A28_15 | BIDIR | LVCMOS33 | 15 | 12 | SLOW |  | NONE |  | LOCATED | NO | NONE
E18 | CHIP2_DATA<3> | IOB33 | IO_L21P_T3_DQS_15 | BIDIR | LVCMOS33 | 15 | 12 | SLOW |  | NONE |  | LOCATED | NO | NONE
F1 |  | IOB33M | IO_L18P_T2_35 | UNUSED |  | 35
F2 |  |  | VCCO_35 |  |  | 35 |  |  |  |  | 3.30
F3 |  | IOB33S | IO_L13N_T2_MRCC_35 | UNUSED |  | 35
F4 |  | IOB33M | IO_L13P_T2_MRCC_35 | UNUSED |  | 35
F5 |  | IOB33 | IO_0_35 | UNUSED |  | 35
F6 |  | IOB33S | IO_L19N_T3_VREF_35 | UNUSED |  | 35
F7 |  |  | GND
F8 |  |  | VCCINT |  |  |  |  |  |  |  | 1.0
F9 |  |  | GND
F10 |  |  | VCCBRAM
F11 |  |  | GND
F12 |  |  | VCCAUX |  |  |  |  |  |  |  | 1.8
F13 |  | IOB33M | IO_L5P_T0_AD9P_15 | UNUSED |  | 15
F14 | CHIP1_DATA<1> | IOB33 | IO_L5N_T0_AD9N_15 | BIDIR | LVCMOS33 | 15 | 12 | SLOW |  | NONE |  | LOCATED | NO | NONE
F15 |  | IOB33M | IO_L14P_T2_SRCC_15 | UNUSED |  | 15
F16 |  | IOB33S | IO_L14N_T2_SRCC_15 | UNUSED |  | 15
F17 |  |  | GND
F18 |  | IOB33S | IO_L22N_T3_A16_15 | UNUSED |  | 15
G1 |  | IOB33S | IO_L17N_T2_35 | UNUSED |  | 35
G2 |  | IOB33S | IO_L15N_T2_DQS_35 | UNUSED |  | 35
G3 |  | IOB33S | IO_L20N_T3_35 | UNUSED |  | 35
G4 |  | IOB33M | IO_L20P_T3_35 | UNUSED |  | 35
G5 |  |  | VCCO_35 |  |  | 35 |  |  |  |  | 3.30
G6 |  | IOB33M | IO_L19P_T3_35 | UNUSED |  | 35
G7 |  |  | VCCINT |  |  |  |  |  |  |  | 1.0
G8 |  |  | GND
G9 |  |  | VCCINT |  |  |  |  |  |  |  | 1.0
G10 |  |  | GND
G11 |  |  | VCCBRAM
G12 |  |  | GND
G13 | CHIP2_DATA<0> | IOB33 | IO_0_15 | BIDIR | LVCMOS33 | 15 | 12 | SLOW |  | NONE |  | LOCATED | NO | NONE
G14 | WE_BAR | IOB33 | IO_L15N_T2_DQS_ADV_B_15 | OUTPUT | LVCMOS33 | 15 | 12 | SLOW |  |  |  | LOCATED | NO | NONE
G15 |  |  | VCCO_15 |  |  | 15 |  |  |  |  | 3.30
G16 |  | IOB33S | IO_L13N_T2_MRCC_15 | UNUSED |  | 15
G17 |  | IOB33S | IO_L18N_T2_A23_15 | UNUSED |  | 15
G18 |  | IOB33M | IO_L22P_T3_A17_15 | UNUSED |  | 15
H1 |  | IOB33M | IO_L17P_T2_35 | UNUSED |  | 35
H2 |  | IOB33M | IO_L15P_T2_DQS_35 | UNUSED |  | 35
H3 |  |  | GND
H4 |  | IOB33S | IO_L21N_T3_DQS_35 | UNUSED |  | 35
H5 |  | IOB33S | IO_L24N_T3_35 | UNUSED |  | 35
H6 |  | IOB33M | IO_L24P_T3_35 | UNUSED |  | 35
H7 |  |  | GND
H8 |  |  | VCCINT |  |  |  |  |  |  |  | 1.0
H9 |  |  | GNDADC_0
H10 |  |  | VCCADC_0
H11 |  |  | GND
H12 |  |  | VCCAUX |  |  |  |  |  |  |  | 1.8
H13 |  |  | GND
H14 |  | IOB33M | IO_L15P_T2_DQS_15 | UNUSED |  | 15
H15 |  | IOB33S | IO_L19N_T3_A21_VREF_15 | UNUSED |  | 15
H16 |  | IOB33M | IO_L13P_T2_MRCC_15 | UNUSED |  | 15
H17 |  | IOB33M | IO_L18P_T2_A24_15 | UNUSED |  | 15
H18 |  |  | VCCO_15 |  |  | 15 |  |  |  |  | 3.30
J1 |  |  | VCCO_35 |  |  | 35 |  |  |  |  | 3.30
J2 |  | IOB33S | IO_L22N_T3_35 | UNUSED |  | 35
J3 |  | IOB33M | IO_L22P_T3_35 | UNUSED |  | 35
J4 |  | IOB33M | IO_L21P_T3_DQS_35 | UNUSED |  | 35
J5 |  | IOB33 | IO_25_35 | UNUSED |  | 35
J6 |  |  | GND
J7 |  |  | VCCINT |  |  |  |  |  |  |  | 1.0
J8 |  |  | GND
J9 |  |  | VREFN_0
J10 |  | IPAD | VP_0 | UNUSED |  | 0
J11 |  |  | VCCINT |  |  |  |  |  |  |  | 1.0
J12 |  |  | GND
J13 |  | IOB33S | IO_L17N_T2_A25_15 | UNUSED |  | 15
J14 |  | IOB33M | IO_L19P_T3_A22_15 | UNUSED |  | 15
J15 |  | IOB33S | IO_L24N_T3_RS0_15 | UNUSED |  | 15
J16 |  |  | GND
J17 |  | IOB33M | IO_L23P_T3_FOE_B_15 | UNUSED |  | 15
J18 |  | IOB33S | IO_L23N_T3_FWE_B_15 | UNUSED |  | 15
K1 |  | IOB33S | IO_L23N_T3_35 | UNUSED |  | 35
K2 |  | IOB33M | IO_L23P_T3_35 | UNUSED |  | 35
K3 |  | IOB33M | IO_L2P_T0_34 | UNUSED |  | 34
K4 |  |  | VCCO_34 |  |  | 34 |  |  |  |  | 3.30
K5 |  | IOB33M | IO_L5P_T0_34 | UNUSED |  | 34
K6 |  | IOB33 | IO_0_34 | UNUSED |  | 34
K7 |  |  | GND
K8 |  |  | VCCINT |  |  |  |  |  |  |  | 1.0
K9 |  | IPAD | VN_0 | UNUSED |  | 0
K10 |  |  | VREFP_0
K11 |  |  | GND
K12 |  |  | VCCAUX |  |  |  |  |  |  |  | 1.8
K13 |  | IOB33M | IO_L17P_T2_A26_15 | UNUSED |  | 15
K14 |  |  | VCCO_15 |  |  | 15 |  |  |  |  | 3.30
K15 |  | IOB33M | IO_L24P_T3_RS1_15 | UNUSED |  | 15
K16 |  | IOB33 | IO_25_15 | UNUSED |  | 15
K17 |  | IOB33M | IO_L1P_T0_D00_MOSI_14 | UNUSED |  | 14
K18 |  | IOB33S | IO_L1N_T0_D01_DIN_14 | UNUSED |  | 14
L1 |  | IOB33M | IO_L1P_T0_34 | UNUSED |  | 34
L2 |  |  | GND
L3 |  | IOB33S | IO_L2N_T0_34 | UNUSED |  | 34
L4 |  | IOB33S | IO_L5N_T0_34 | UNUSED |  | 34
L5 |  | IOB33S | IO_L6N_T0_VREF_34 | UNUSED |  | 34
L6 |  | IOB33M | IO_L6P_T0_34 | UNUSED |  | 34
L7 |  |  | VCCINT |  |  |  |  |  |  |  | 1.0
L8 |  |  | GND
L9 |  |  | DXN_0
L10 |  |  | DXP_0
L11 |  |  | VCCINT |  |  |  |  |  |  |  | 1.0
L12 |  |  | GND
L13 |  | IOB33M | IO_L6P_T0_FCS_B_14 | UNUSED |  | 14
L14 |  | IOB33M | IO_L2P_T0_D02_14 | UNUSED |  | 14
L15 |  | IOB33M | IO_L3P_T0_DQS_PUDC_B_14 | UNUSED |  | 14
L16 |  | IOB33S | IO_L3N_T0_DQS_EMCCLK_14 | UNUSED |  | 14
L17 |  |  | VCCO_14 |  |  | 14 |  |  |  |  | 3.30
L18 |  | IOB33M | IO_L4P_T0_D04_14 | UNUSED |  | 14
M1 |  | IOB33S | IO_L1N_T0_34 | UNUSED |  | 34
M2 |  | IOB33S | IO_L4N_T0_34 | UNUSED |  | 34
M3 |  | IOB33M | IO_L4P_T0_34 | UNUSED |  | 34
M4 |  | IOB33M | IO_L16P_T2_34 | UNUSED |  | 34
M5 |  |  | GND
M6 |  | IOB33M | IO_L18P_T2_34 | UNUSED |  | 34
M7 |  |  | GND
M8 |  |  | VCCINT |  |  |  |  |  |  |  | 1.0
M9 |  |  | GND
M10 |  |  | VCCINT |  |  |  |  |  |  |  | 1.0
M11 |  |  | GND
M12 |  |  | VCCAUX |  |  |  |  |  |  |  | 1.8
M13 |  | IOB33S | IO_L6N_T0_D08_VREF_14 | UNUSED |  | 14
M14 |  | IOB33S | IO_L2N_T0_D03_14 | UNUSED |  | 14
M15 |  |  | GND
M16 |  | IOB33M | IO_L10P_T1_D14_14 | UNUSED |  | 14
M17 |  | IOB33S | IO_L10N_T1_D15_14 | UNUSED |  | 14
M18 |  | IOB33S | IO_L4N_T0_D05_14 | UNUSED |  | 14
N1 |  | IOB33S | IO_L3N_T0_DQS_34 | UNUSED |  | 34
N2 |  | IOB33M | IO_L3P_T0_DQS_34 | UNUSED |  | 34
N3 |  |  | VCCO_34 |  |  | 34 |  |  |  |  | 3.30
N4 |  | IOB33S | IO_L16N_T2_34 | UNUSED |  | 34
N5 |  | IOB33M | IO_L13P_T2_MRCC_34 | UNUSED |  | 34
N6 |  | IOB33S | IO_L18N_T2_34 | UNUSED |  | 34
N7 |  |  | VCCINT |  |  |  |  |  |  |  | 1.0
N8 |  |  | GND
N9 |  |  | VCCINT |  |  |  |  |  |  |  | 1.0
N10 |  |  | GND
N11 |  |  | VCCINT |  |  |  |  |  |  |  | 1.0
N12 |  |  | GND
N13 |  |  | VCCO_14 |  |  | 14 |  |  |  |  | 3.30
N14 |  | IOB33M | IO_L8P_T1_D11_14 | UNUSED |  | 14
N15 |  | IOB33M | IO_L11P_T1_SRCC_14 | UNUSED |  | 14
N16 |  | IOB33S | IO_L11N_T1_SRCC_14 | UNUSED |  | 14
N17 |  | IOB33M | IO_L9P_T1_DQS_14 | UNUSED |  | 14
N18 |  |  | GND
P1 |  |  | GND
P2 | LED_OUT<15> | IOB33 | IO_L15P_T2_DQS_34 | OUTPUT | LVCMOS33 | 34 | 12 | SLOW |  |  |  | LOCATED | NO | NONE
P3 |  | IOB33S | IO_L14N_T2_SRCC_34 | UNUSED |  | 34
P4 |  | IOB33M | IO_L14P_T2_SRCC_34 | UNUSED |  | 34
P5 | LED_OUT<12> | IOB33 | IO_L13N_T2_MRCC_34 | OUTPUT | LVCMOS33 | 34 | 12 | SLOW |  |  |  | LOCATED | NO | NONE
P6 |  |  | VCCO_34 |  |  | 34 |  |  |  |  | 3.30
P7 |  |  | INIT_B_0
P8 |  |  | CFGBVS_0
P9 |  |  | PROGRAM_B_0
P10 |  |  | DONE_0
P11 |  |  | M2_0
P12 |  |  | M0_0
P13 |  |  | M1_0
P14 |  | IOB33S | IO_L8N_T1_D12_14 | UNUSED |  | 14
P15 |  | IOB33M | IO_L13P_T2_MRCC_14 | UNUSED |  | 14
P16 |  |  | VCCO_14 |  |  | 14 |  |  |  |  | 3.30
P17 |  | IOB33M | IO_L12P_T1_MRCC_14 | UNUSED |  | 14
P18 |  | IOB33S | IO_L9N_T1_DQS_D13_14 | UNUSED |  | 14
R1 | LED_OUT<11> | IOB33 | IO_L17P_T2_34 | OUTPUT | LVCMOS33 | 34 | 12 | SLOW |  |  |  | LOCATED | NO | NONE
R2 | LED_OUT<14> | IOB33 | IO_L15N_T2_DQS_34 | OUTPUT | LVCMOS33 | 34 | 12 | SLOW |  |  |  | LOCATED | NO | NONE
R3 |  | IOB33M | IO_L11P_T1_SRCC_34 | UNUSED |  | 34
R4 |  |  | GND
R5 | SEED<3> | IOB33 | IO_L19N_T3_VREF_34 | INPUT | LVCMOS33 | 34 |  |  |  | NONE |  | LOCATED | NO | NONE
R6 | SEED<4> | IOB33 | IO_L19P_T3_34 | INPUT | LVCMOS33 | 34 |  |  |  | NONE |  | LOCATED | NO | NONE
R7 | SEED<5> | IOB33 | IO_L23P_T3_34 | INPUT | LVCMOS33 | 34 |  |  |  | NONE |  | LOCATED | NO | NONE
R8 | LED_OUT<2> | IOB33 | IO_L24P_T3_34 | OUTPUT | LVCMOS33 | 34 | 12 | SLOW |  |  |  | LOCATED | NO | NONE
R9 |  |  | VCCO_0 |  |  | 0 |  |  |  |  | any******
R10 |  | IOB33 | IO_25_14 | UNUSED |  | 14
R11 |  | IOB33 | IO_0_14 | UNUSED |  | 14
R12 |  | IOB33M | IO_L5P_T0_D06_14 | UNUSED |  | 14
R13 |  | IOB33S | IO_L5N_T0_D07_14 | UNUSED |  | 14
R14 |  |  | GND
R15 |  | IOB33S | IO_L13N_T2_MRCC_14 | UNUSED |  | 14
R16 |  | IOB33M | IO_L15P_T2_DQS_RDWR_B_14 | UNUSED |  | 14
R17 |  | IOB33S | IO_L12N_T1_MRCC_14 | UNUSED |  | 14
R18 |  | IOB33M | IO_L7P_T1_D09_14 | UNUSED |  | 14
T1 |  | IOB33S | IO_L17N_T2_34 | UNUSED |  | 34
T2 |  |  | VCCO_34 |  |  | 34 |  |  |  |  | 3.30
T3 |  | IOB33S | IO_L11N_T1_SRCC_34 | UNUSED |  | 34
T4 | LED_OUT<5> | IOB33 | IO_L12N_T1_MRCC_34 | OUTPUT | LVCMOS33 | 34 | 12 | SLOW |  |  |  | LOCATED | NO | NONE
T5 | LED_OUT<4> | IOB33 | IO_L12P_T1_MRCC_34 | OUTPUT | LVCMOS33 | 34 | 12 | SLOW |  |  |  | LOCATED | NO | NONE
T6 | LED_OUT<3> | IOB33 | IO_L23N_T3_34 | OUTPUT | LVCMOS33 | 34 | 12 | SLOW |  |  |  | LOCATED | NO | NONE
T7 |  |  | GND
T8 | LED_OUT<0> | IOB33 | IO_L24N_T3_34 | OUTPUT | LVCMOS33 | 34 | 12 | SLOW |  |  |  | LOCATED | NO | NONE
T9 |  | IOB33M | IO_L24P_T3_A01_D17_14 | UNUSED |  | 14
T10 |  | IOB33S | IO_L24N_T3_A00_D16_14 | UNUSED |  | 14
T11 |  | IOB33M | IO_L19P_T3_A10_D26_14 | UNUSED |  | 14
T12 |  |  | VCCO_14 |  |  | 14 |  |  |  |  | 3.30
T13 |  | IOB33M | IO_L23P_T3_A03_D19_14 | UNUSED |  | 14
T14 |  | IOB33M | IO_L14P_T2_SRCC_14 | UNUSED |  | 14
T15 |  | IOB33S | IO_L14N_T2_SRCC_14 | UNUSED |  | 14
T16 |  | IOB33S | IO_L15N_T2_DQS_DOUT_CSO_B_14 | UNUSED |  | 14
T17 |  |  | GND
T18 |  | IOB33S | IO_L7N_T1_D10_14 | UNUSED |  | 14
U1 | LED_OUT<13> | IOB33 | IO_L7P_T1_34 | OUTPUT | LVCMOS33 | 34 | 12 | SLOW |  |  |  | LOCATED | NO | NONE
U2 |  | IOB33M | IO_L9P_T1_DQS_34 | UNUSED |  | 34
U3 | LED_OUT<9> | IOB33 | IO_L8N_T1_34 | OUTPUT | LVCMOS33 | 34 | 12 | SLOW |  |  |  | LOCATED | NO | NONE
U4 |  | IOB33M | IO_L8P_T1_34 | UNUSED |  | 34
U5 |  |  | VCCO_34 |  |  | 34 |  |  |  |  | 3.30
U6 | LED_OUT<7> | IOB33 | IO_L22N_T3_34 | OUTPUT | LVCMOS33 | 34 | 12 | SLOW |  |  |  | LOCATED | NO | NONE
U7 | LED_OUT<6> | IOB33 | IO_L22P_T3_34 | OUTPUT | LVCMOS33 | 34 | 12 | SLOW |  |  |  | LOCATED | NO | NONE
U8 | SEED<6> | IOB33 | IO_25_34 | INPUT | LVCMOS33 | 34 |  |  |  | NONE |  | LOCATED | NO | NONE
U9 | SEED<7> | IOB33 | IO_L21P_T3_DQS_34 | INPUT | LVCMOS33 | 34 |  |  |  | NONE |  | LOCATED | NO | NONE
U10 |  |  | GND
U11 | COUNTER_RST | IOB33 | IO_L19N_T3_A09_D25_VREF_14 | OUTPUT | LVCMOS33 | 14 | 12 | SLOW |  |  |  | LOCATED | NO | NONE
U12 |  | IOB33M | IO_L20P_T3_A08_D24_14 | UNUSED |  | 14
U13 |  | IOB33S | IO_L23N_T3_A02_D18_14 | UNUSED |  | 14
U14 |  | IOB33M | IO_L22P_T3_A05_D21_14 | UNUSED |  | 14
U15 |  |  | VCCO_14 |  |  | 14 |  |  |  |  | 3.30
U16 |  | IOB33M | IO_L18P_T2_A12_D28_14 | UNUSED |  | 14
U17 |  | IOB33M | IO_L17P_T2_A14_D30_14 | UNUSED |  | 14
U18 |  | IOB33S | IO_L17N_T2_A13_D29_14 | UNUSED |  | 14
V1 | LED_OUT<10> | IOB33 | IO_L7N_T1_34 | OUTPUT | LVCMOS33 | 34 | 12 | SLOW |  |  |  | LOCATED | NO | NONE
V2 |  | IOB33S | IO_L9N_T1_DQS_34 | UNUSED |  | 34
V3 |  |  | GND
V4 | LED_OUT<8> | IOB33 | IO_L10N_T1_34 | OUTPUT | LVCMOS33 | 34 | 12 | SLOW |  |  |  | LOCATED | NO | NONE
V5 | SEED<0> | IOB33 | IO_L10P_T1_34 | INPUT | LVCMOS33 | 34 |  |  |  | NONE |  | LOCATED | NO | NONE
V6 | SEED<1> | IOB33 | IO_L20N_T3_34 | INPUT | LVCMOS33 | 34 |  |  |  | NONE |  | LOCATED | NO | NONE
V7 | SEED<2> | IOB33 | IO_L20P_T3_34 | INPUT | LVCMOS33 | 34 |  |  |  | NONE |  | LOCATED | NO | NONE
V8 |  |  | VCCO_34 |  |  | 34 |  |  |  |  | 3.30
V9 | LED_OUT<1> | IOB33 | IO_L21N_T3_DQS_34 | OUTPUT | LVCMOS33 | 34 | 12 | SLOW |  |  |  | LOCATED | NO | NONE
V10 | INIT | IOB33 | IO_L21P_T3_DQS_14 | INPUT | LVCMOS33 | 14 |  |  |  | NONE |  | LOCATED | NO | NONE
V11 |  | IOB33S | IO_L21N_T3_DQS_A06_D22_14 | UNUSED |  | 14
V12 |  | IOB33S | IO_L20N_T3_A07_D23_14 | UNUSED |  | 14
V13 |  |  | GND
V14 |  | IOB33S | IO_L22N_T3_A04_D20_14 | UNUSED |  | 14
V15 | COUNTER_CLK | IOB33 | IO_L16P_T2_CSI_B_14 | OUTPUT | LVCMOS33 | 14 | 12 | SLOW |  |  |  | LOCATED | NO | NONE
V16 |  | IOB33S | IO_L16N_T2_A15_D31_14 | UNUSED |  | 14
V17 |  | IOB33S | IO_L18N_T2_A11_D27_14 | UNUSED |  | 14
V18 |  |  | VCCO_14 |  |  | 14 |  |  |  |  | 3.30
# ----- | ----- | ----- | ----- | ----- | ----- | ----- | ----- | ----- | ----- | ----- | ----- | ----- | ----- | -----
#
#* Default value.
#** This default Pullup/Pulldown value can be overridden in Bitgen.
#All RSVD_0 pins must be tied to GROUND.
#****** Special VCCO requirements may apply. Please consult the device
# family datasheet for specific guideline on VCCO requirements.
#
#
#

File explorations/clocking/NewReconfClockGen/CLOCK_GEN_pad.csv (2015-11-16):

#Release 14.7 - par P.20131013 (nt64)
#Copyright (c) 1995-2013 Xilinx | Inc. All rights reserved.
#Sun Nov 15 23:26:03 2015
#
## NOTE: This file is designed to be imported into a spreadsheet program
# such as Microsoft Excel for viewing | printing and sorting. The
# character is used as the data field separator. This file is also designed
# to support parsing.
#
#INPUT FILE: CLOCK_GEN_map.ncd
#OUTPUT FILE: CLOCK_GEN_pad.csv
#PART TYPE: xc6slx16
#SPEED GRADE: -3
#PACKAGE: csg324
#
# Pinout by Pin Number:
#
# ----- | ----- | ----- | ----- | ----- | ----- | ----- | ----- | ----- | ----- | ----- | ----- | ----- | ----- | -----
Pin Number | Signal Name | Pin Usage | Pin Name | Direction | IO Standard | IO Bank Number | Drive (mA) | Slew Rate | Termination | IOB Delay | Voltage | Constraint | IO Register | Signal Integrity
A1 |  |  | GND
A2 |  | IOBS | IO_L2N_0 | UNUSED |  | 0
A3 |  | IOBS | IO_L4N_0 | UNUSED |  | 0
A4 |  | IOBS | IO_L5N_0 | UNUSED |  | 0
A5 |  | IOBS | IO_L6N_0 | UNUSED |  | 0
A6 | LOW_LEVEL_LIMIT<0> | IOB | IO_L8N_VREF_0 | INPUT | LVCMOS33 | 0 |  |  |  | NONE |  | LOCATED | NO | NONE
A7 |  | IOBS | IO_L10N_0 | UNUSED |  | 0
A8 |  | IOBS | IO_L33N_0 | UNUSED |  | 0
A9 |  | IOBS | IO_L35N_GCLK16_0 | UNUSED |  | 0
A10 | LOW_LEVEL_LIMIT<5> | IOB | IO_L37N_GCLK12_0 | INPUT | LVCMOS33 | 0 |  |  |  | NONE |  | LOCATED | NO | NONE
A11 |  | IOBS | IO_L39N_0 | UNUSED |  | 0
A12 |  | IOBS | IO_L41N_0 | UNUSED |  | 0
A13 | HIGH_LEVEL_LIMIT<1> | IOB | IO_L50N_0 | INPUT | LVCMOS33 | 0 |  |  |  | NONE |  | LOCATED | NO | NONE
A14 | HIGH_LEVEL_LIMIT<2> | IOB | IO_L62N_VREF_0 | INPUT | LVCMOS33 | 0 |  |  |  | NONE |  | LOCATED | NO | NONE
A15 | HIGH_LEVEL_LIMIT<3> | IOB | IO_L64N_SCP4_0 | INPUT | LVCMOS33 | 0 |  |  |  | NONE |  | LOCATED | NO | NONE
A16 |  | IOBS | IO_L66N_SCP0_0 | UNUSED |  | 0
A17 |  |  | TCK
A18 |  |  | GND
B1 |  |  | VCCAUX |  |  |  |  |  |  |  | 2.5
B2 |  | IOBM | IO_L2P_0 | UNUSED |  | 0
B3 |  | IOBM | IO_L4P_0 | UNUSED |  | 0
B4 |  | IOBM | IO_L5P_0 | UNUSED |  | 0
B5 |  |  | VCCO_0 |  |  | 0 |  |  |  |  | any******
B6 |  | IOBM | IO_L8P_0 | UNUSED |  | 0
B7 |  |  | GND
B8 |  | IOBM | IO_L33P_0 | UNUSED |  | 0
B9 |  | IOBM | IO_L35P_GCLK17_0 | UNUSED |  | 0
B10 |  |  | VCCO_0 |  |  | 0 |  |  |  |  | any******
B11 |  | IOBM | IO_L39P_0 | UNUSED |  | 0
B12 |  | IOBM | IO_L41P_0 | UNUSED |  | 0
B13 |  |  | GND
B14 |  | IOBM | IO_L62P_0 | UNUSED |  | 0
B15 |  |  | VCCO_0 |  |  | 0 |  |  |  |  | any******
B16 |  | IOBM | IO_L66P_SCP1_0 | UNUSED |  | 0
B17 |  |  | VCCAUX |  |  |  |  |  |  |  | 2.5
B18 |  |  | TMS
C1 |  | IOBS | IO_L83N_VREF_3 | UNUSED |  | 3
C2 |  | IOBM | IO_L83P_3 | UNUSED |  | 3
C3 |  |  | GND
C4 |  | IOBS | IO_L1N_VREF_0 | UNUSED |  | 0
C5 |  | IOBM | IO_L6P_0 | UNUSED |  | 0
C6 |  | IOBS | IO_L3N_0 | UNUSED |  | 0
C7 |  | IOBM | IO_L10P_0 | UNUSED |  | 0
C8 | LOW_LEVEL_LIMIT<2> | IOB | IO_L11N_0 | INPUT | LVCMOS33 | 0 |  |  |  | NONE |  | LOCATED | NO | NONE
C9 | LOW_LEVEL_LIMIT<4> | IOB | IO_L34N_GCLK18_0 | INPUT | LVCMOS33 | 0 |  |  |  | NONE |  | LOCATED | NO | NONE
C10 |  | IOBM | IO_L37P_GCLK13_0 | UNUSED |  | 0
C11 |  | IOBS | IO_L36N_GCLK14_0 | UNUSED |  | 0
C12 | HIGH_LEVEL_LIMIT<0> | IOB | IO_L47N_0 | INPUT | LVCMOS33 | 0 |  |  |  | NONE |  | LOCATED | NO | NONE
C13 |  | IOBM | IO_L50P_0 | UNUSED |  | 0
C14 |  | IOBS | IO_L65N_SCP2_0 | UNUSED |  | 0
C15 |  | IOBM | IO_L64P_SCP5_0 | UNUSED |  | 0
C16 |  |  | GND
C17 |  | IOBM | IO_L29P_A23_M1A13_1 | UNUSED |  | 1
C18 | HIGH_LEVEL_LIMIT<4> | IOB | IO_L29N_A22_M1A14_1 | INPUT | LVCMOS33 | 1 |  |  |  | NONE |  | LOCATED | NO | NONE
D1 |  | IOBS | IO_L52N_M3A9_3 | UNUSED |  | 3
D2 |  | IOBM | IO_L52P_M3A8_3 | UNUSED |  | 3
D3 |  | IOBS | IO_L54N_M3A11_3 | UNUSED |  | 3
D4 |  | IOBM | IO_L1P_HSWAPEN_0 | UNUSED |  | 0
D5 |  |  | GND
D6 |  | IOBM | IO_L3P_0 | UNUSED |  | 0
D7 |  |  | VCCO_0 |  |  | 0 |  |  |  |  | any******
D8 |  | IOBM | IO_L11P_0 | UNUSED |  | 0
D9 |  | IOBM | IO_L34P_GCLK19_0 | UNUSED |  | 0
D10 |  |  | GND
D11 |  | IOBM | IO_L36P_GCLK15_0 | UNUSED |  | 0
D12 |  | IOBM | IO_L47P_0 | UNUSED |  | 0
D13 |  |  | VCCO_0 |  |  | 0 |  |  |  |  | any******
D14 |  | IOBM | IO_L65P_SCP3_0 | UNUSED |  | 0
D15 |  |  | TDI
D16 |  |  | TDO
D17 |  | IOBM | IO_L31P_A19_M1CKE_1 | UNUSED |  | 1
D18 |  | IOBS | IO_L31N_A18_M1A12_1 | UNUSED |  | 1
E1 |  | IOBS | IO_L50N_M3BA2_3 | UNUSED |  | 3
E2 |  |  | VCCO_3 |  |  | 3 |  |  |  |  | any******
E3 |  | IOBM | IO_L50P_M3WE_3 | UNUSED |  | 3
E4 |  | IOBM | IO_L54P_M3RESET_3 | UNUSED |  | 3
E5 |  |  | VCCAUX |  |  |  |  |  |  |  | 2.5
E6 | LOW_LEVEL_LIMIT<1> | IOB | IO_L7N_0 | INPUT | LVCMOS33 | 0 |  |  |  | NONE |  | LOCATED | NO | NONE
E7 |  | IOBM | IO_L9P_0 | UNUSED |  | 0
E8 |  | IOBS | IO_L9N_0 | UNUSED |  | 0
E9 |  |  | VCCAUX |  |  |  |  |  |  |  | 2.5
E10 |  |  | VCCO_0 |  |  | 0 |  |  |  |  | any******
E11 |  | IOBS | IO_L42N_0 | UNUSED |  | 0
E12 |  | IOBS | IO_L51N_0 | UNUSED |  | 0
E13 |  | IOBS | IO_L63N_SCP6_0 | UNUSED |  | 0
E14 |  |  | VCCAUX |  |  |  |  |  |  |  | 2.5
E15 |  |  | GND
E16 |  | IOBM | IO_L33P_A15_M1A10_1 | UNUSED |  | 1
E17 |  |  | VCCO_1 |  |  | 1 |  |  |  |  | any******
E18 | HIGH_LEVEL_LIMIT<5> | IOB | IO_L33N_A14_M1A4_1 | INPUT | LVCMOS33 | 1 |  |  |  | NONE |  | LOCATED | NO | NONE
F1 |  | IOBS | IO_L48N_M3BA1_3 | UNUSED |  | 3
F2 |  | IOBM | IO_L48P_M3BA0_3 | UNUSED |  | 3
F3 |  | IOBS | IO_L51N_M3A4_3 | UNUSED |  | 3
F4 |  | IOBM | IO_L51P_M3A10_3 | UNUSED |  | 3
F5 |  | IOBS | IO_L55N_M3A14_3 | UNUSED |  | 3
F6 |  | IOBM | IO_L55P_M3A13_3 | UNUSED |  | 3
F7 |  | IOBM | IO_L7P_0 | UNUSED |  | 0
F8 | LOW_LEVEL_LIMIT<3> | IOB | IO_L32N_0 | INPUT | LVCMOS33 | 0 |  |  |  | NONE |  | LOCATED | NO | NONE
F9 |  | IOBS | IO_L38N_VREF_0 | UNUSED |  | 0
F10 | LOW_LEVEL_LIMIT<6> | IOB | IO_L40N_0 | INPUT | LVCMOS33 | 0 |  |  |  | NONE |  | LOCATED | NO | NONE
F11 |  | IOBM | IO_L42P_0 | UNUSED |  | 0
F12 |  | IOBM | IO_L51P_0 | UNUSED |  | 0
F13 |  | IOBM | IO_L63P_SCP7_0 | UNUSED |  | 0
F14 |  | IOBM | IO_L30P_A21_M1RESET_1 | UNUSED |  | 1
F15 |  | IOBM | IO_L1P_A25_1 | UNUSED |  | 1
F16 | HIGH_LEVEL_LIMIT<6> | IOB | IO_L1N_A24_VREF_1 | INPUT | LVCMOS33 | 1 |  |  |  | NONE |  | LOCATED | NO | NONE
F17 |  | IOBM | IO_L35P_A11_M1A7_1 | UNUSED |  | 1
F18 |  | IOBS | IO_L35N_A10_M1A2_1 | UNUSED |  | 1
G1 |  | IOBS | IO_L46N_M3CLKN_3 | UNUSED |  | 3
G2 |  |  | GND
G3 |  | IOBM | IO_L46P_M3CLK_3 | UNUSED |  | 3
G4 |  |  | VCCO_3 |  |  | 3 |  |  |  |  | any******
G5 |  |  | GND
G6 |  | IOBS | IO_L53N_M3A12_3 | UNUSED |  | 3
G7 |  |  | VCCINT |  |  |  |  |  |  |  | 1.2
G8 |  | IOBM | IO_L32P_0 | UNUSED |  | 0
G9 |  | IOBM | IO_L38P_0 | UNUSED |  | 0
G10 |  |  | VCCAUX |  |  |  |  |  |  |  | 2.5
G11 |  | IOBM | IO_L40P_0 | UNUSED |  | 0
G12 |  |  | GND
G13 | RST | IOB | IO_L32N_A16_M1A9_1 | INPUT | LVCMOS33 | 1 |  |  |  | NONE |  | LOCATED | NO | NONE
G14 |  | IOBS | IO_L30N_A20_M1A11_1 | UNUSED |  | 1
G15 |  |  | VCCO_1 |  |  | 1 |  |  |  |  | any******
G16 |  | IOBM | IO_L38P_A5_M1CLK_1 | UNUSED |  | 1
G17 |  |  | GND
G18 |  | IOBS | IO_L38N_A4_M1CLKN_1 | UNUSED |  | 1
H1 |  | IOBS | IO_L41N_GCLK26_M3DQ5_3 | UNUSED |  | 3
H2 |  | IOBM | IO_L41P_GCLK27_M3DQ4_3 | UNUSED |  | 3
H3 |  | IOBS | IO_L44N_GCLK20_M3A6_3 | UNUSED |  | 3
H4 |  | IOBM | IO_L44P_GCLK21_M3A5_3 | UNUSED |  | 3
H5 |  | IOBS | IO_L49N_M3A2_3 | UNUSED |  | 3
H6 |  | IOBM | IO_L49P_M3A7_3 | UNUSED |  | 3
H7 |  | IOBM | IO_L53P_M3CKE_3 | UNUSED |  | 3
H8 |  |  | GND
H9 |  |  | VCCINT |  |  |  |  |  |  |  | 1.2
H10 |  |  | GND
H11 |  |  | VCCINT |  |  |  |  |  |  |  | 1.2
H12 |  | IOBM | IO_L32P_A17_M1A8_1 | UNUSED |  | 1
H13 |  | IOBM | IO_L36P_A9_M1BA0_1 | UNUSED |  | 1
H14 |  | IOBS | IO_L36N_A8_M1BA1_1 | UNUSED |  | 1
H15 |  | IOBM | IO_L37P_A7_M1A0_1 | UNUSED |  | 1
H16 | INIT | IOB | IO_L37N_A6_M1A1_1 | INPUT | LVCMOS33 | 1 |  |  |  | NONE |  | LOCATED | NO | NONE
H17 |  | IOBM | IO_L43P_GCLK5_M1DQ4_1 | UNUSED |  | 1
H18 |  | IOBS | IO_L43N_GCLK4_M1DQ5_1 | UNUSED |  | 1
J1 |  | IOBS | IO_L40N_M3DQ7_3 | UNUSED |  | 3
J2 |  |  | VCCO_3 |  |  | 3 |  |  |  |  | any******
J3 |  | IOBM | IO_L40P_M3DQ6_3 | UNUSED |  | 3
J4 |  |  | GND
J5 |  |  | VCCO_3 |  |  | 3 |  |  |  |  | any******
J6 |  | IOBS | IO_L47N_M3A1_3 | UNUSED |  | 3
J7 |  | IOBM | IO_L47P_M3A0_3 | UNUSED |  | 3
J8 |  |  | VCCINT |  |  |  |  |  |  |  | 1.2
J9 |  |  | GND
J10 |  |  | VCCINT |  |  |  |  |  |  |  | 1.2
J11 |  |  | GND
J12 |  |  | VCCAUX |  |  |  |  |  |  |  | 2.5
J13 |  | IOBM | IO_L39P_M1A3_1 | UNUSED |  | 1
J14 |  |  | VCCO_1 |  |  | 1 |  |  |  |  | any******
J15 |  |  | GND
J16 |  | IOBM | IO_L44P_A3_M1DQ6_1 | UNUSED |  | 1
J17 |  |  | VCCO_1 |  |  | 1 |  |  |  |  | any******
J18 |  | IOBS | IO_L44N_A2_M1DQ7_1 | UNUSED |  | 1
K1 |  | IOBS | IO_L38N_M3DQ3_3 | UNUSED |  | 3
K2 |  | IOBM | IO_L38P_M3DQ2_3 | UNUSED |  | 3
K3 |  | IOBS | IO_L42N_GCLK24_M3LDM_3 | UNUSED |  | 3
K4 |  | IOBM | IO_L42P_GCLK25_TRDY2_M3UDM_3 | UNUSED |  | 3
K5 |  | IOBS | IO_L43N_GCLK22_IRDY2_M3CASN_3 | UNUSED |  | 3
K6 |  | IOBS | IO_L45N_M3ODT_3 | UNUSED |  | 3
K7 |  |  | VCCAUX |  |  |  |  |  |  |  | 2.5
K8 |  |  | GND
K9 |  |  | VCCINT |  |  |  |  |  |  |  | 1.2
K10 |  |  | GND
K11 |  |  | VCCINT |  |  |  |  |  |  |  | 1.2
K12 |  | IOBM | IO_L34P_A13_M1WE_1 | UNUSED |  | 1
K13 |  | IOBS | IO_L34N_A12_M1BA2_1 | UNUSED |  | 1
K14 |  | IOBS | IO_L39N_M1ODT_1 | UNUSED |  | 1
K15 |  | IOBM | IO_L41P_GCLK9_IRDY1_M1RASN_1 | UNUSED |  | 1
K16 |  | IOBS | IO_L41N_GCLK8_M1CASN_1 | UNUSED |  | 1
K17 |  | IOBM | IO_L45P_A1_M1LDQS_1 | UNUSED |  | 1
K18 |  | IOBS | IO_L45N_A0_M1LDQSN_1 | UNUSED |  | 1
L1 |  | IOBS | IO_L37N_M3DQ1_3 | UNUSED |  | 3
L2 |  | IOBM | IO_L37P_M3DQ0_3 | UNUSED |  | 3
L3 |  | IOBS | IO_L39N_M3LDQSN_3 | UNUSED |  | 3
L4 |  | IOBM | IO_L39P_M3LDQS_3 | UNUSED |  | 3
L5 |  | IOBM | IO_L43P_GCLK23_M3RASN_3 | UNUSED |  | 3
L6 |  | IOBM | IO_L31P_3 | UNUSED |  | 3
L7 |  | IOBM | IO_L45P_M3A3_3 | UNUSED |  | 3
L8 |  |  | VCCINT |  |  |  |  |  |  |  | 1.2
L9 |  |  | GND
L10 |  |  | VCCINT |  |  |  |  |  |  |  | 1.2
L11 |  |  | GND
L12 |  | IOBM | IO_L40P_GCLK11_M1A5_1 | UNUSED |  | 1
L13 |  | IOBS | IO_L40N_GCLK10_M1A6_1 | UNUSED |  | 1
L14 |  | IOBM | IO_L61P_1 | UNUSED |  | 1
L15 |  | IOBM | IO_L42P_GCLK7_M1UDM_1 | UNUSED |  | 1
L16 |  | IOBS | IO_L42N_GCLK6_TRDY1_M1LDM_1 | UNUSED |  | 1
L17 |  | IOBM | IO_L46P_FCS_B_M1DQ2_1 | UNUSED |  | 1
L18 |  | IOBS | IO_L46N_FOE_B_M1DQ3_1 | UNUSED |  | 1
M1 |  | IOBS | IO_L36N_M3DQ9_3 | UNUSED |  | 3
M2 |  |  | GND
M3 |  | IOBM | IO_L36P_M3DQ8_3 | UNUSED |  | 3
M4 |  |  | VCCO_3 |  |  | 3 |  |  |  |  | any******
M5 |  | IOBS | IO_L31N_VREF_3 | UNUSED |  | 3
M6 |  |  | GND
M7 |  |  | VCCINT |  |  |  |  |  |  |  | 1.2
M8 |  | IOBM | IO_L40P_2 | UNUSED |  | 2
M9 |  |  | VCCAUX |  |  |  |  |  |  |  | 2.5
M10 |  | IOBM | IO_L22P_2 | UNUSED |  | 2
M11 |  | IOBM | IO_L15P_2 | UNUSED |  | 2
M12 |  |  | VCCINT |  |  |  |  |  |  |  | 1.2
M13 |  | IOBS | IO_L61N_1 | UNUSED |  | 1
M14 |  | IOBM | IO_L53P_1 | UNUSED |  | 1
M15 |  |  | VCCO_1 |  |  | 1 |  |  |  |  | any******
M16 |  | IOBM | IO_L47P_FWE_B_M1DQ0_1 | UNUSED |  | 1
M17 |  |  | GND
M18 |  | IOBS | IO_L47N_LDC_M1DQ1_1 | UNUSED |  | 1
N1 |  | IOBS | IO_L35N_M3DQ11_3 | UNUSED |  | 3
N2 |  | IOBM | IO_L35P_M3DQ10_3 | UNUSED |  | 3
N3 |  | IOBS | IO_L1N_VREF_3 | UNUSED |  | 3
N4 |  | IOBM | IO_L1P_3 | UNUSED |  | 3
N5 | OUT1 | IOB | IO_L64P_D8_2 | OUTPUT | LVCMOS33 | 2 | 24 | FAST |  |  |  | LOCATED | YES | NONE
N6 |  | IOBM | IO_L47P_2 | UNUSED |  | 2
N7 |  | IOBM | IO_L44P_2 | UNUSED |  | 2
N8 |  | IOBS | IO_L40N_2 | UNUSED |  | 2
N9 |  | IOBS | IO_L22N_2 | UNUSED |  | 2
N10 |  | IOBM | IO_L20P_2 | UNUSED |  | 2
N11 |  | IOBS | IO_L15N_2 | UNUSED |  | 2
N12 |  | IOBM | IO_L13P_M1_2 | UNUSED |  | 2
N13 |  |  | GND
N14 |  | IOBS | IO_L53N_VREF_1 | UNUSED |  | 1
N15 |  | IOBM | IO_L50P_M1UDQS_1 | UNUSED |  | 1
N16 |  | IOBS | IO_L50N_M1UDQSN_1 | UNUSED |  | 1
N17 |  | IOBM | IO_L48P_HDC_M1DQ8_1 | UNUSED |  | 1
N18 |  | IOBS | IO_L48N_M1DQ9_1 | UNUSED |  | 1
P1 |  | IOBS | IO_L34N_M3UDQSN_3 | UNUSED |  | 3
P2 |  | IOBM | IO_L34P_M3UDQS_3 | UNUSED |  | 3
P3 |  | IOBS | IO_L2N_3 | UNUSED |  | 3
P4 |  | IOBM | IO_L2P_3 | UNUSED |  | 3
P5 |  |  | VCCAUX |  |  |  |  |  |  |  | 2.5
P6 | OUT2 | IOB | IO_L64N_D9_2 | OUTPUT | LVCMOS33 | 2 | 24 | FAST |  |  |  | LOCATED | YES | NONE
P7 |  | IOBS | IO_L47N_2 | UNUSED |  | 2
P8 |  | IOBS | IO_L44N_2 | UNUSED |  | 2
P9 |  |  | VCCO_2 |  |  | 2 |  |  |  |  | 3.30
P10 |  |  | VCCAUX |  |  |  |  |  |  |  | 2.5
P11 |  | IOBS | IO_L20N_2 | UNUSED |  | 2
P12 |  | IOBS | IO_L13N_D10_2 | UNUSED |  | 2
P13 |  |  | CMPCS_B_2
P14 |  |  | VCCAUX |  |  |  |  |  |  |  | 2.5
P15 |  | IOBM | IO_L74P_AWAKE_1 | UNUSED |  | 1
P16 |  | IOBS | IO_L74N_DOUT_BUSY_1 | UNUSED |  | 1
P17 |  | IOBM | IO_L49P_M1DQ10_1 | UNUSED |  | 1
P18 |  | IOBS | IO_L49N_M1DQ11_1 | UNUSED |  | 1
R1 |  |  | GND
R2 |  |  | VCCO_3 |  |  | 3 |  |  |  |  | any******
R3 |  | IOBM | IO_L62P_D5_2 | UNUSED |  | 2
R4 |  |  | GND
R5 |  | IOBM | IO_L48P_D7_2 | UNUSED |  | 2
R6 |  |  | VCCO_2 |  |  | 2 |  |  |  |  | 3.30
R7 |  | IOBM | IO_L46P_2 | UNUSED |  | 2
R8 |  | IOBM | IO_L31P_GCLK31_D14_2 | UNUSED |  | 2
R9 |  |  | GND
R10 |  | IOBM | IO_L29P_GCLK3_2 | UNUSED |  | 2
R11 |  | IOBM | IO_L16P_2 | UNUSED |  | 2
R12 |  |  | VCCO_2 |  |  | 2 |  |  |  |  | 3.30
R13 |  | IOBM | IO_L3P_D0_DIN_MISO_MISO1_2 | UNUSED |  | 2
R14 |  |  | GND
R15 |  | IOBM | IO_L1P_CCLK_2 | UNUSED |  | 2
R16 |  |  | SUSPEND
R17 |  |  | VCCO_1 |  |  | 1 |  |  |  |  | any******
R18 |  |  | GND
T1 |  | IOBS | IO_L33N_M3DQ13_3 | UNUSED |  | 3
T2 |  | IOBM | IO_L33P_M3DQ12_3 | UNUSED |  | 3
T3 |  | IOBS | IO_L62N_D6_2 | UNUSED |  | 2
T4 |  | IOBM | IO_L63P_2 | UNUSED |  | 2
T5 |  | IOBS | IO_L48N_RDWR_B_VREF_2 | UNUSED |  | 2
T6 | OUT3 | IOB | IO_L45P_2 | OUTPUT | LVCMOS33 | 2 | 24 | FAST |  |  |  | LOCATED | YES | NONE
T7 |  | IOBS | IO_L46N_2 | UNUSED |  | 2
T8 |  | IOBS | IO_L31N_GCLK30_D15_2 | UNUSED |  | 2
T9 |  | IOBM | IO_L32P_GCLK29_2 | UNUSED |  | 2
T10 |  | IOBS | IO_L29N_GCLK2_2 | UNUSED |  | 2
T11 |  | IOBS | IO_L16N_VREF_2 | UNUSED |  | 2
T12 |  | IOBM | IO_L19P_2 | UNUSED |  | 2
T13 |  | IOBS | IO_L3N_MOSI_CSI_B_MISO0_2 | UNUSED |  | 2
T14 |  | IOBM | IO_L12P_D1_MISO2_2 | UNUSED |  | 2
T15 |  | IOBS | IO_L1N_M0_CMPMISO_2 | UNUSED |  | 2
T16 |  |  | GND
T17 |  | IOBM | IO_L51P_M1DQ12_1 | UNUSED |  | 1
T18 |  | IOBS | IO_L51N_M1DQ13_1 | UNUSED |  | 1
U1 |  | IOBS | IO_L32N_M3DQ15_3 | UNUSED |  | 3
U2 |  | IOBM | IO_L32P_M3DQ14_3 | UNUSED |  | 3
U3 |  | IOBM | IO_L65P_INIT_B_2 | UNUSED |  | 2
U4 |  |  | VCCO_2 |  |  | 2 |  |  |  |  | 3.30
U5 |  | IOBM | IO_L49P_D3_2 | UNUSED |  | 2
U6 |  |  | GND
U7 |  | IOBM | IO_L43P_2 | UNUSED |  | 2
U8 |  | IOBM | IO_L41P_2 | UNUSED |  | 2
U9 |  |  | VCCO_2 |  |  | 2 |  |  |  |  | 3.30
U10 |  | IOBM | IO_L30P_GCLK1_D13_2 | UNUSED |  | 2
U11 |  | IOBM | IO_L23P_2 | UNUSED |  | 2
U12 |  |  | GND
U13 |  | IOBM | IO_L14P_D11_2 | UNUSED |  | 2
U14 |  |  | VCCO_2 |  |  | 2 |  |  |  |  | 3.30
U15 |  | IOBM | IO_L5P_2 | UNUSED |  | 2
U16 |  | IOBM | IO_L2P_CMPCLK_2 | UNUSED |  | 2
U17 |  | IOBM | IO_L52P_M1DQ14_1 | UNUSED |  | 1
U18 |  | IOBS | IO_L52N_M1DQ15_1 | UNUSED |  | 1
V1 |  |  | GND
V2 |  |  | PROGRAM_B_2
V3 |  | IOBS | IO_L65N_CSO_B_2 | UNUSED |  | 2
V4 |  | IOBS | IO_L63N_2 | UNUSED |  | 2
V5 |  | IOBS | IO_L49N_D4_2 | UNUSED |  | 2
V6 | OUT4 | IOB | IO_L45N_2 | OUTPUT | LVCMOS33 | 2 | 24 | FAST |  |  |  | LOCATED | YES | NONE
V7 |  | IOBS | IO_L43N_2 | UNUSED |  | 2
V8 |  | IOBS | IO_L41N_VREF_2 | UNUSED |  | 2
V9 |  | IOBS | IO_L32N_GCLK28_2 | UNUSED |  | 2
V10 | CLK | IOB | IO_L30N_GCLK0_USERCCLK_2 | INPUT | LVCMOS33 | 2 |  |  |  | NONE |  | LOCATED | NO | NONE
V11 |  | IOBS | IO_L23N_2 | UNUSED |  | 2
V12 |  | IOBS | IO_L19N_2 | UNUSED |  | 2
V13 |  | IOBS | IO_L14N_D12_2 | UNUSED |  | 2
V14 |  | IOBS | IO_L12N_D2_MISO3_2 | UNUSED |  | 2
V15 |  | IOBS | IO_L5N_2 | UNUSED |  | 2
V16 |  | IOBS | IO_L2N_CMPMOSI_2 | UNUSED |  | 2
V17 |  |  | DONE_2
V18 |  |  | GND
# ----- | ----- | ----- | ----- | ----- | ----- | ----- | ----- | ----- | ----- | ----- | ----- | ----- | ----- | -----
#
#* Default value.
#** This default Pullup/Pulldown value can be overridden in Bitgen.
#****** Special VCCO requirements may apply. Please consult the device
# family datasheet for specific guideline on VCCO requirements.
#
#
#

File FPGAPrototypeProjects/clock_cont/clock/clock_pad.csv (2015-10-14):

#Release 14.7 - par P.20131013 (nt64)
#Copyright (c) 1995-2013 Xilinx | Inc. All rights reserved.
#Sat Oct 10 16:48:16 2015
#
## NOTE: This file is designed to be imported into a spreadsheet program
# such as Microsoft Excel for viewing | printing and sorting. The
# character is used as the data field separator. This file is also designed
# to support parsing.
#
#INPUT FILE: clock_map.ncd
#OUTPUT FILE: clock_pad.csv
#PART TYPE: xc7a100t
#SPEED GRADE: -3
#PACKAGE: csg324
#
# Pinout by Pin Number:
#
# ----- | ----- | ----- | ----- | ----- | ----- | ----- | ----- | ----- | ----- | ----- | ----- | ----- | ----- | -----
Pin Number | Signal Name | Pin Usage | Pin Name | Direction | IO Standard | IO Bank Number | Drive (mA) | Slew Rate | Termination | IOB Delay | Voltage | Constraint | IO Register | Signal Integrity
A1 |  | IOB33S | IO_L9N_T1_DQS_AD7N_35 | UNUSED |  | 35
A2 |  |  | GND
A3 |  | IOB33S | IO_L8N_T1_AD14N_35 | UNUSED |  | 35
A4 |  | IOB33M | IO_L8P_T1_AD14P_35 | UNUSED |  | 35
A5 |  | IOB33S | IO_L3N_T0_DQS_AD5N_35 | UNUSED |  | 35
A6 |  | IOB33M | IO_L3P_T0_DQS_AD5P_35 | UNUSED |  | 35
A7 |  |  | VCCO_35 |  |  | 35 |  |  |  |  | 1.80
A8 |  | IOB33S | IO_L12N_T1_MRCC_16 | UNUSED |  | 16
A9 |  | IOB33S | IO_L14N_T2_SRCC_16 | UNUSED |  | 16
A10 |  | IOB33M | IO_L14P_T2_SRCC_16 | UNUSED |  | 16
A11 |  | IOB33S | IO_L4N_T0_15 | UNUSED |  | 15
A12 |  |  | GND
A13 |  | IOB33M | IO_L9P_T1_DQS_AD3P_15 | UNUSED |  | 15
A14 |  | IOB33S | IO_L9N_T1_DQS_AD3N_15 | UNUSED |  | 15
A15 |  | IOB33M | IO_L8P_T1_AD10P_15 | UNUSED |  | 15
A16 |  | IOB33S | IO_L8N_T1_AD10N_15 | UNUSED |  | 15
A17 |  |  | VCCO_15 |  |  | 15 |  |  |  |  | 1.80
A18 |  | IOB33S | IO_L10N_T1_AD11N_15 | UNUSED |  | 15
B1 |  | IOB33M | IO_L9P_T1_DQS_AD7P_35 | UNUSED |  | 35
B2 |  | IOB33S | IO_L10N_T1_AD15N_35 | UNUSED |  | 35
B3 |  | IOB33M | IO_L10P_T1_AD15P_35 | UNUSED |  | 35
B4 |  | IOB33S | IO_L7N_T1_AD6N_35 | UNUSED |  | 35
B5 |  |  | GND
B6 |  | IOB33S | IO_L2N_T0_AD12N_35 | UNUSED |  | 35
B7 |  | IOB33M | IO_L2P_T0_AD12P_35 | UNUSED |  | 35
B8 |  | IOB33M | IO_L12P_T1_MRCC_16 | UNUSED |  | 16
B9 |  | IOB33S | IO_L11N_T1_SRCC_16 | UNUSED |  | 16
B10 |  |  | VCCO_16 |  |  | 16 |  |  |  |  | any******
B11 |  | IOB33M | IO_L4P_T0_15 | UNUSED |  | 15
B12 |  | IOB33S | IO_L3N_T0_DQS_AD1N_15 | UNUSED |  | 15
B13 |  | IOB33M | IO_L2P_T0_AD8P_15 | UNUSED |  | 15
B14 |  | IOB33S | IO_L2N_T0_AD8N_15 | UNUSED |  | 15
B15 |  |  | GND
B16 |  | IOB33M | IO_L7P_T1_AD2P_15 | UNUSED |  | 15
B17 |  | IOB33S | IO_L7N_T1_AD2N_15 | UNUSED |  | 15
B18 |  | IOB33M | IO_L10P_T1_AD11P_15 | UNUSED |  | 15
C1 |  | IOB33S | IO_L16N_T2_35 | UNUSED |  | 35
C2 |  | IOB33M | IO_L16P_T2_35 | UNUSED |  | 35
C3 |  |  | VCCO_35 |  |  | 35 |  |  |  |  | 1.80
C4 |  | IOB33M | IO_L7P_T1_AD6P_35 | UNUSED |  | 35
C5 |  | IOB33S | IO_L1N_T0_AD4N_35 | UNUSED |  | 35
C6 |  | IOB33M | IO_L1P_T0_AD4P_35 | UNUSED |  | 35
C7 |  | IOB33S | IO_L4N_T0_35 | UNUSED |  | 35
C8 |  |  | GND
C9 |  | IOB33M | IO_L11P_T1_SRCC_16 | UNUSED |  | 16
C10 |  | IOB33S | IO_L13N_T2_MRCC_16 | UNUSED |  | 16
C11 |  | IOB33M | IO_L13P_T2_MRCC_16 | UNUSED |  | 16
C12 |  | IOB33M | IO_L3P_T0_DQS_AD1P_15 | UNUSED |  | 15
C13 |  |  | VCCO_15 |  |  | 15 |  |  |  |  | 1.80
C14 |  | IOB33S | IO_L1N_T0_AD0N_15 | UNUSED |  | 15
C15 |  | IOB33S | IO_L12N_T1_MRCC_15 | UNUSED |  | 15
C16 |  | IOB33M | IO_L20P_T3_A20_15 | UNUSED |  | 15
C17 | clk_out | IOB | IO_L20N_T3_A19_15 | OUTPUT | LVCMOS18* | 15 | 12 | SLOW |  |  |  | LOCATED | NO | NONE
C18 |  |  | GND
D1 |  |  | GND
D2 |  | IOB33S | IO_L14N_T2_SRCC_35 | UNUSED |  | 35
D3 |  | IOB33S | IO_L12N_T1_MRCC_35 | UNUSED |  | 35
D4 |  | IOB33S | IO_L11N_T1_SRCC_35 | UNUSED |  | 35
D5 |  | IOB33M | IO_L11P_T1_SRCC_35 | UNUSED |  | 35
D6 |  |  | VCCO_35 |  |  | 35 |  |  |  |  | 1.80
D7 |  | IOB33S | IO_L6N_T0_VREF_35 | UNUSED |  | 35
D8 |  | IOB33M | IO_L4P_T0_35 | UNUSED |  | 35
D9 |  | IOB33S | IO_L6N_T0_VREF_16 | UNUSED |  | 16
D10 |  | IOB33S | IO_L19N_T3_VREF_16 | UNUSED |  | 16
D11 |  |  | GND
D12 |  | IOB33M | IO_L6P_T0_15 | UNUSED |  | 15
D13 |  | IOB33S | IO_L6N_T0_VREF_15 | UNUSED |  | 15
D14 |  | IOB33M | IO_L1P_T0_AD0P_15 | UNUSED |  | 15
D15 |  | IOB33M | IO_L12P_T1_MRCC_15 | UNUSED |  | 15
D16 |  |  | VCCO_15 |  |  | 15 |  |  |  |  | 1.80
D17 |  | IOB33S | IO_L16N_T2_A27_15 | UNUSED |  | 15
D18 |  | IOB33S | IO_L21N_T3_DQS_A18_15 | UNUSED |  | 15
E1 |  | IOB33S | IO_L18N_T2_35 | UNUSED |  | 35
E2 |  | IOB33M | IO_L14P_T2_SRCC_35 | UNUSED |  | 35
E3 | clk | IOB | IO_L12P_T1_MRCC_35 | INPUT | LVCMOS18* | 35 |  |  |  | NONE |  | LOCATED | NO | NONE
E4 |  |  | GND
E5 |  | IOB33S | IO_L5N_T0_AD13N_35 | UNUSED |  | 35
E6 |  | IOB33M | IO_L5P_T0_AD13P_35 | UNUSED |  | 35
E7 |  | IOB33M | IO_L6P_T0_35 | UNUSED |  | 35
E8 |  |  | VCCBATT_0
E9 |  |  | CCLK_0
E10 |  |  | TCK_0
E11 |  |  | TDI_0
E12 |  |  | TMS_0
E13 |  |  | TDO_0
E14 |  |  | GND
E15 |  | IOB33M | IO_L11P_T1_SRCC_15 | UNUSED |  | 15
E16 |  | IOB33S | IO_L11N_T1_SRCC_15 | UNUSED |  | 15
E17 |  | IOB33M | IO_L16P_T2_A28_15 | UNUSED |  | 15
E18 |  | IOB33M | IO_L21P_T3_DQS_15 | UNUSED |  | 15
F1 |  | IOB33M | IO_L18P_T2_35 | UNUSED |  | 35
F2 |  |  | VCCO_35 |  |  | 35 |  |  |  |  | 1.80
F3 |  | IOB33S | IO_L13N_T2_MRCC_35 | UNUSED |  | 35
F4 |  | IOB33M | IO_L13P_T2_MRCC_35 | UNUSED |  | 35
F5 |  | IOB33 | IO_0_35 | UNUSED |  | 35
F6 |  | IOB33S | IO_L19N_T3_VREF_35 | UNUSED |  | 35
F7 |  |  | GND
F8 |  |  | VCCINT |  |  |  |  |  |  |  | 1.0
F9 |  |  | GND
F10 |  |  | VCCBRAM
F11 |  |  | GND
F12 |  |  | VCCAUX |  |  |  |  |  |  |  | 1.8
F13 |  | IOB33M | IO_L5P_T0_AD9P_15 | UNUSED |  | 15
F14 |  | IOB33S | IO_L5N_T0_AD9N_15 | UNUSED |  | 15
F15 |  | IOB33M | IO_L14P_T2_SRCC_15 | UNUSED |  | 15
F16 |  | IOB33S | IO_L14N_T2_SRCC_15 | UNUSED |  | 15
F17 |  |  | GND
F18 |  | IOB33S | IO_L22N_T3_A16_15 | UNUSED |  | 15
G1 |  | IOB33S | IO_L17N_T2_35 | UNUSED |  | 35
G2 |  | IOB33S | IO_L15N_T2_DQS_35 | UNUSED |  | 35
G3 |  | IOB33S | IO_L20N_T3_35 | UNUSED |  | 35
G4 |  | IOB33M | IO_L20P_T3_35 | UNUSED |  | 35
G5 |  |  | VCCO_35 |  |  | 35 |  |  |  |  | 1.80
G6 |  | IOB33M | IO_L19P_T3_35 | UNUSED |  | 35
G7 |  |  | VCCINT |  |  |  |  |  |  |  | 1.0
G8 |  |  | GND
G9 |  |  | VCCINT |  |  |  |  |  |  |  | 1.0
G10 |  |  | GND
G11 |  |  | VCCBRAM
G12 |  |  | GND
G13 |  | IOB33 | IO_0_15 | UNUSED |  | 15
G14 |  | IOB33S | IO_L15N_T2_DQS_ADV_B_15 | UNUSED |  | 15
G15 |  |  | VCCO_15 |  |  | 15 |  |  |  |  | 1.80
G16 |  | IOB33S | IO_L13N_T2_MRCC_15 | UNUSED |  | 15
G17 |  | IOB33S | IO_L18N_T2_A23_15 | UNUSED |  | 15
G18 |  | IOB33M | IO_L22P_T3_A17_15 | UNUSED |  | 15
H1 |  | IOB33M | IO_L17P_T2_35 | UNUSED |  | 35
H2 |  | IOB33M | IO_L15P_T2_DQS_35 | UNUSED |  | 35
H3 |  |  | GND
H4 |  | IOB33S | IO_L21N_T3_DQS_35 | UNUSED |  | 35
H5 |  | IOB33S | IO_L24N_T3_35 | UNUSED |  | 35
H6 | duty<0> | IOB | IO_L24P_T3_35 | INPUT | LVCMOS18* | 35 |  |  |  | NONE |  | LOCATED | NO | NONE
H7 |  |  | GND
H8 |  |  | VCCINT |  |  |  |  |  |  |  | 1.0
H9 |  |  | GNDADC_0
H10 |  |  | VCCADC_0
H11 |  |  | GND
H12 |  |  | VCCAUX |  |  |  |  |  |  |  | 1.8
H13 |  |  | GND
H14 |  | IOB33M | IO_L15P_T2_DQS_15 | UNUSED |  | 15
H15 |  | IOB33S | IO_L19N_T3_A21_VREF_15 | UNUSED |  | 15
H16 |  | IOB33M | IO_L13P_T2_MRCC_15 | UNUSED |  | 15
H17 |  | IOB33M | IO_L18P_T2_A24_15 | UNUSED |  | 15
H18 |  |  | VCCO_15 |  |  | 15 |  |  |  |  | 1.80
J1 |  |  | VCCO_35 |  |  | 35 |  |  |  |  | 1.80
J2 |  | IOB33S | IO_L22N_T3_35 | UNUSED |  | 35
J3 |  | IOB33M | IO_L22P_T3_35 | UNUSED |  | 35
J4 |  | IOB33M | IO_L21P_T3_DQS_35 | UNUSED |  | 35
J5 |  | IOB33 | IO_25_35 | UNUSED |  | 35
J6 |  |  | GND
J7 |  |  | VCCINT |  |  |  |  |  |  |  | 1.0
J8 |  |  | GND
J9 |  |  | VREFN_0
J10 |  | IPAD | VP_0 | UNUSED |  | 0
J11 |  |  | VCCINT |  |  |  |  |  |  |  | 1.0
J12 |  |  | GND
J13 |  | IOB33S | IO_L17N_T2_A25_15 | UNUSED |  | 15
J14 |  | IOB33M | IO_L19P_T3_A22_15 | UNUSED |  | 15
J15 | period<0> | IOB | IO_L24N_T3_RS0_15 | INPUT | LVCMOS18* | 15 |  |  |  | NONE |  | LOCATED | NO | NONE
J16 |  |  | GND
J17 |  | IOB33M | IO_L23P_T3_FOE_B_15 | UNUSED |  | 15
J18 |  | IOB33S | IO_L23N_T3_FWE_B_15 | UNUSED |  | 15
K1 |  | IOB33S | IO_L23N_T3_35 | UNUSED |  | 35
K2 |  | IOB33M | IO_L23P_T3_35 | UNUSED |  | 35
K3 |  | IOB33M | IO_L2P_T0_34 | UNUSED |  | 34
K4 |  |  | VCCO_34 |  |  | 34 |  |  |  |  | 1.80
K5 |  | IOB33M | IO_L5P_T0_34 | UNUSED |  | 34
K6 |  | IOB33 | IO_0_34 | UNUSED |  | 34
K7 |  |  | GND
K8 |  |  | VCCINT |  |  |  |  |  |  |  | 1.0
K9 |  | IPAD | VN_0 | UNUSED |  | 0
K10 |  |  | VREFP_0
K11 |  |  | GND
K12 |  |  | VCCAUX |  |  |  |  |  |  |  | 1.8
K13 |  | IOB33M | IO_L17P_T2_A26_15 | UNUSED |  | 15
K14 |  |  | VCCO_15 |  |  | 15 |  |  |  |  | 1.80
K15 |  | IOB33M | IO_L24P_T3_RS1_15 | UNUSED |  | 15
K16 |  | IOB33 | IO_25_15 | UNUSED |  | 15
K17 |  | IOB33M | IO_L1P_T0_D00_MOSI_14 | UNUSED |  | 14
K18 |  | IOB33S | IO_L1N_T0_D01_DIN_14 | UNUSED |  | 14
L1 |  | IOB33M | IO_L1P_T0_34 | UNUSED |  | 34
L2 |  |  | GND
L3 |  | IOB33S | IO_L2N_T0_34 | UNUSED |  | 34
L4 |  | IOB33S | IO_L5N_T0_34 | UNUSED |  | 34
L5 |  | IOB33S | IO_L6N_T0_VREF_34 | UNUSED |  | 34
L6 |  | IOB33M | IO_L6P_T0_34 | UNUSED |  | 34
L7 |  |  | VCCINT |  |  |  |  |  |  |  | 1.0
L8 |  |  | GND
L9 |  |  | DXN_0
L10 |  |  | DXP_0
L11 |  |  | VCCINT |  |  |  |  |  |  |  | 1.0
L12 |  |  | GND
L13 |  | IOB33M | IO_L6P_T0_FCS_B_14 | UNUSED |  | 14
L14 |  | IOB33M | IO_L2P_T0_D02_14 | UNUSED |  | 14
L15 |  | IOB33M | IO_L3P_T0_DQS_PUDC_B_14 | UNUSED |  | 14
L16 | period<1> | IOB | IO_L3N_T0_DQS_EMCCLK_14 | INPUT | LVCMOS18* | 14 |  |  |  | NONE |  | LOCATED | NO | NONE
L17 |  |  | VCCO_14 |  |  | 14 |  |  |  |  | 1.80
L18 |  | IOB33M | IO_L4P_T0_D04_14 | UNUSED |  | 14
M1 |  | IOB33S | IO_L1N_T0_34 | UNUSED |  | 34
M2 |  | IOB33S | IO_L4N_T0_34 | UNUSED |  | 34
M3 |  | IOB33M | IO_L4P_T0_34 | UNUSED |  | 34
M4 |  | IOB33M | IO_L16P_T2_34 | UNUSED |  | 34
M5 |  |  | GND
M6 |  | IOB33M | IO_L18P_T2_34 | UNUSED |  | 34
M7 |  |  | GND
M8 |  |  | VCCINT |  |  |  |  |  |  |  | 1.0
M9 |  |  | GND
M10 |  |  | VCCINT |  |  |  |  |  |  |  | 1.0
M11 |  |  | GND
M12 |  |  | VCCAUX |  |  |  |  |  |  |  | 1.8
M13 | period<2> | IOB | IO_L6N_T0_D08_VREF_14 | INPUT | LVCMOS18* | 14 |  |  |  | NONE |  | LOCATED | NO | NONE
M14 |  | IOB33S | IO_L2N_T0_D03_14 | UNUSED |  | 14
M15 |  |  | GND
M16 |  | IOB33M | IO_L10P_T1_D14_14 | UNUSED |  | 14
M17 |  | IOB33S | IO_L10N_T1_D15_14 | UNUSED |  | 14
M18 |  | IOB33S | IO_L4N_T0_D05_14 | UNUSED |  | 14
N1 |  | IOB33S | IO_L3N_T0_DQS_34 | UNUSED |  | 34
N2 |  | IOB33M | IO_L3P_T0_DQS_34 | UNUSED |  | 34
N3 |  |  | VCCO_34 |  |  | 34 |  |  |  |  | 1.80
N4 |  | IOB33S | IO_L16N_T2_34 | UNUSED |  | 34
N5 |  | IOB33M | IO_L13P_T2_MRCC_34 | UNUSED |  | 34
N6 |  | IOB33S | IO_L18N_T2_34 | UNUSED |  | 34
N7 |  |  | VCCINT |  |  |  |  |  |  |  | 1.0
N8 |  |  | GND
N9 |  |  | VCCINT |  |  |  |  |  |  |  | 1.0
N10 |  |  | GND
N11 |  |  | VCCINT |  |  |  |  |  |  |  | 1.0
N12 |  |  | GND
N13 |  |  | VCCO_14 |  |  | 14 |  |  |  |  | 1.80
N14 |  | IOB33M | IO_L8P_T1_D11_14 | UNUSED |  | 14
N15 |  | IOB33M | IO_L11P_T1_SRCC_14 | UNUSED |  | 14
N16 |  | IOB33S | IO_L11N_T1_SRCC_14 | UNUSED |  | 14
N17 |  | IOB33M | IO_L9P_T1_DQS_14 | UNUSED |  | 14
N18 |  |  | GND
P1 |  |  | GND
P2 |  | IOB33M | IO_L15P_T2_DQS_34 | UNUSED |  | 34
P3 |  | IOB33S | IO_L14N_T2_SRCC_34 | UNUSED |  | 34
P4 |  | IOB33M | IO_L14P_T2_SRCC_34 | UNUSED |  | 34
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

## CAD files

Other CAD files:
explorations/clocking/NewReconfClockGen/isim/LIMIT_GEN_TB_isim_beh.exe.sim/work/LIMIT_GEN_TB_isim_beh.exe_main.nt64.obj
FPGAPrototypeProjects/clock_cont/clock/isim/clock_isim_beh.exe.sim/work/clock_isim_beh.exe_main.nt64.obj
FPGAPrototypeProjects/clock_cont2/isim/ReconfigurableClockGeneratorTB_isim_beh.exe.sim/work/ReconfigurableClockGeneratorTB_isim_beh.exe_main.nt64.obj
explorations/clocking/NewReconfClockGen/isim/RECONF_PULSE_GEN_isim_beh.exe.sim/work/RECONF_PULSE_GEN_isim_beh.exe_main.nt64.obj
FPGAPrototypeProjects/Force_Format_Register/isim/FF_REG_TB_isim_beh.exe.sim/work/FF_REG_TB_isim_beh.exe_main.nt64.obj
FPGAPrototypeProjects/clock_cont/clock/isim/testbench_isim_beh.exe.sim/work/testbench_isim_beh.exe_main.nt64.obj
explorations/clocking/NewReconfClockGen/isim/CLOCK_GEN_TB_isim_beh.exe.sim/work/CLOCK_GEN_TB_isim_beh.exe_main.nt64.obj
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

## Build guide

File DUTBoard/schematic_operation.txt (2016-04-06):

The "EXTERNAL" bus represents the 128 FPGA pins tied to this board. These pins are used to deliver signals to/from the DUT.

There are four clocks, CLK_1, CLK_2, CLK_3, CLK_4, which are identical clocks used for each counter IC. A single reset is provided for all of the counter ICs.
For real-time testing, the skew on the counter clock should be minimal. When switching from SRAM write mode to SRAM read mode, which requires that we reset the counter, minimizing the skew on the reset signal is not critical.

There are four ~CS signals (~CS_1, ~CS_2, ~CS_3, ~CS_4), four ~WE signals (~WE_1, ~WE_2, ~WE_3, ~WE_4), and one ~OE signal. Each ~CS and ~WE signal drives two SRAM ICs; the ~OE signal drives all of the SRAM blocks.
For real-time testing, the skew on the ~CS and ~WE signals should be minimal. The ~OE signal is set to 0 when the SRAM ICs need to be read/written and is set to 1 otherwise in order to save power.

The ~PL, ~MR, STCP, SHCP, and Q signals (all corresponding to the output buffer IC) are not sensitive to timing, as the output buffer only becomes relevant after real-time testing is complete. 

Similarly, the EN signal (used for the voltage translators) is not timing sensitive since the signal changes value after real-time testing is complete.

GLOBAL_HIGH_POWER is used as the "VCC" input to the voltage translator. For instance, we may need to convert 4V (if the user requests that voltage as their logic high) into 3.3V.

VCC is whatever voltage the user wants to serve as a logic high for their DUT.
3V3 powers all of the ICs on the board.

Total pins used by FPGA: 128 + 4 + 1 + 9 + 5 + 1 = 148 pins
The remaining two pins are used as RX/TX lines for communication with the BeagleBone Black.

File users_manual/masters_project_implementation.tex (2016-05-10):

\section{Master's Project: Implementation}

\subsection{MOSIS Packages Supported}
In our senior project, we were able to support 11x11, 12x12, and 13x13 MOSIS packages. Because we need more FPGA pins to configure external hardware in this project, we are only able to support 11x11 and 12x12 packages on our DUT Board's 13x13 ZIF socket. See Figure \ref{fig:mosis_packages_supported} for details.

\begin{figure}
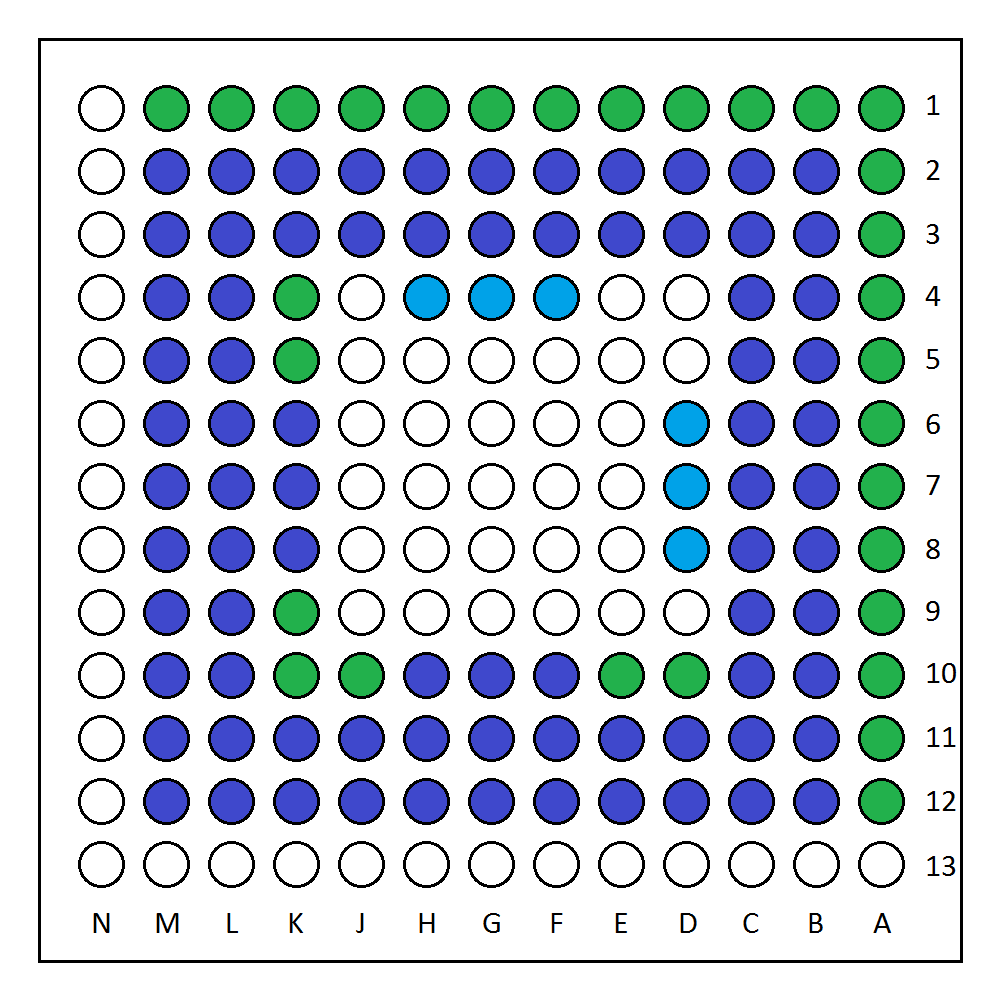
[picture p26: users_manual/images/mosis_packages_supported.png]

\caption{MOSIS packages supported by our tester. Blue: Pins for 11x11 packages. Green: Pins for 12x12 packages. Purple: Pins shared by 11x11 and 12x12 packages.}
\label{fig:mosis_packages_supported}
\end{figure}

\subsection{BeagleBone Black Web Server and C Code}
The code that controls the system consists of the web server, which provides a test form, and the C code called by the server code that runs commands the FPGA and configures the digital potentiometers. 

The web server is designed using three main tools. HTML is used to display the both the initial form for test configuration and to display the results of the tests. JQuery is used to give the user the ability to dynamically add and remove signals and test vectors. PHP is used to take the information from the form and runs the C code. 

Indeed, the PHP function \href{http://php.net/manual/en/function.exec.php}{exec()} allows our web form to execute a binary. The function requires a string form of the shell command that runs a C program. The return value of the exec() call is a vector of any print statements in the C programas well as the actual return value of the C program. Currently, the C code prints HTML lines and the PHP code prints out these statements line by line on a web page.

One task that was tricky was to take the arrays from the web form and provide it to the C program. We were able to perform this task using JSON encoding. Our encoding takes the array from PHP and converts it into a string. This string contains all of the values from the form. Although not written yet, the C code will  parse this string into an array that can be used for programming the FPGA and digital potentiometers.

Figure \ref{fig:web_form} shows the layout for the web form. The layout of this form is relatively simple. We encourage readers to play around with the web form if nobody else is using the system. (See Section 7 for a link to the web form.)

\begin{figure}[!h]
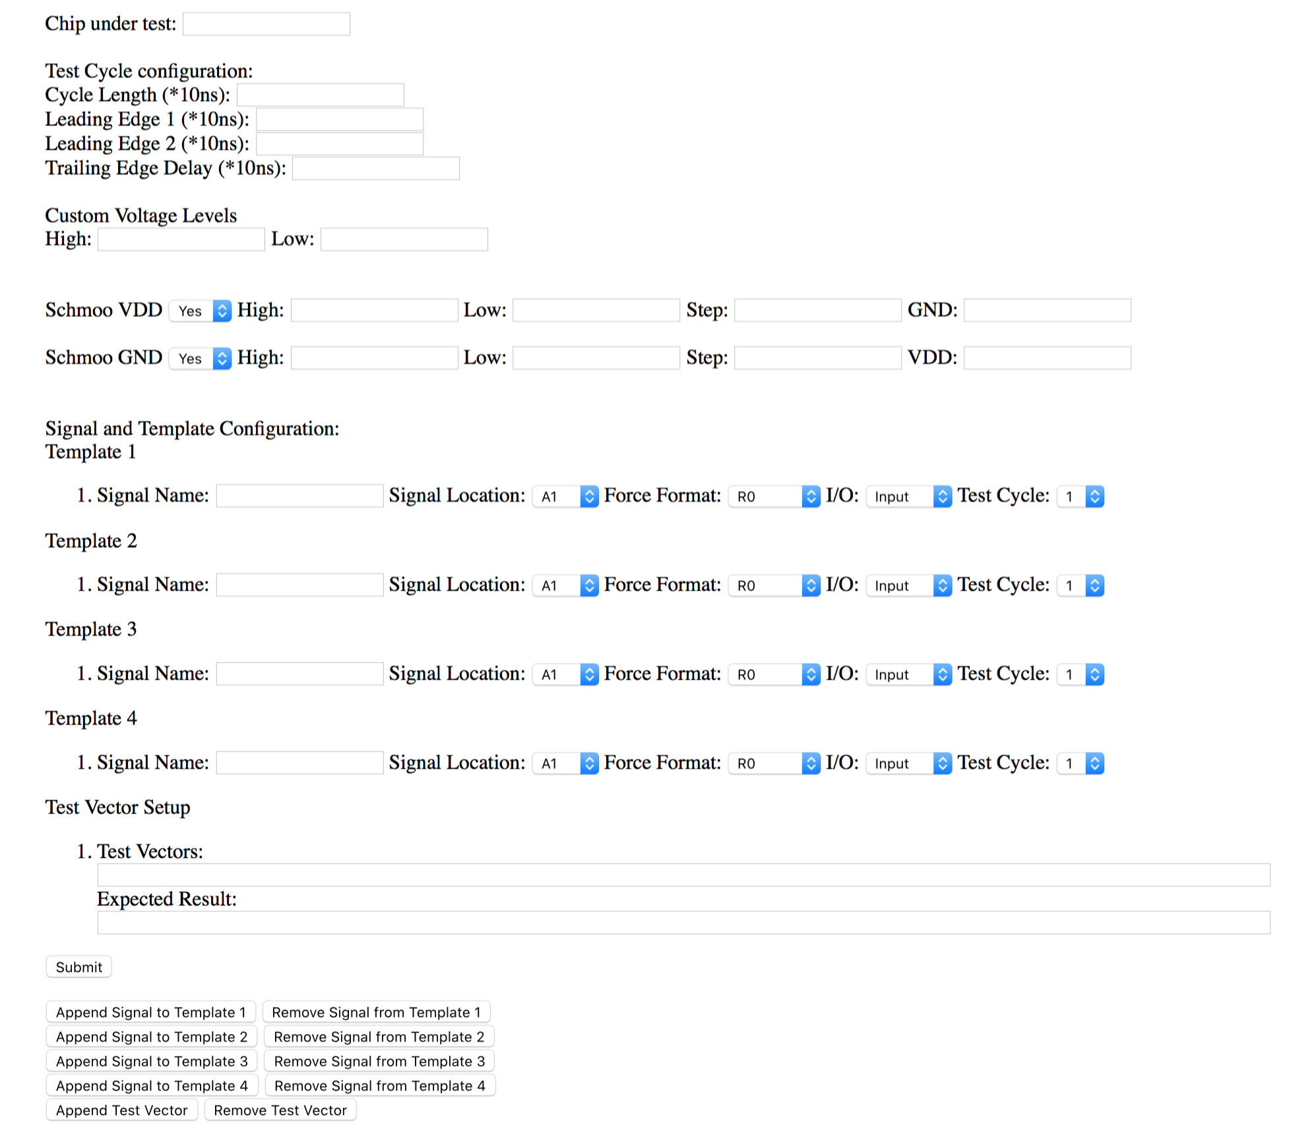
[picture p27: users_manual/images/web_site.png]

\caption{Web form to configure tests.}
\label{fig:web_form}
\end{figure}

\subsection{Verilog for Numato Saturn}
For a detailed understanding of the Verilog coded onto the Numato Saturn, we advise readers to study to the well-commented Verilog code on our repository. In this section, we provide a synopsis of the Verilog design.

Our Verilog design consists of one "central" finite state machine (FSM) that communicates with controllers for the following components: 
\begin{itemize}
	\item Block RAM.
	\item Counters.
	\item DUT input/output signals.
	\item Output buffers.
	\item SRAM blocks.
	\item UART.
	\item Voltage translators.
\end{itemize}

We first describe how the BeagleBone Black communicates with the FPGA. Then, we further detail each controller and finally the central FSM logic.

\subsubsection{BeagleBone Black - FPGA Communication Protocol}
The BeagleBone Black serves as a master device, the FPGA a slave device. The two boards communicate with each other via UART (baud rate 115200, one start bit, eight bits per word, one stop bit, no parity bit). 16 bytes are always sent at a time between the two devices.

The BeagleBone Black may send the following commands (note that only the least significant byte in the transfer is recognized): 
\begin{itemize}
\item 8'b00000000: The next 16 bytes are a template vector.
\item 8'b00000001: The next 16 bytes are a force-format vector.
\item 8'b00000010: The next 16 bytes are a cycle vector.
\item 8'b00000011: The next 16 bytes are an input vector.
\item 8'b00000100: The next 16 bytes will contain, starting with the least significant byte and one byte per entity, DELAY 1, DELAY 2, WIDTH, LENGTH.
\item 8'b00000101: The FPGA should execute all input vectors.
\item 8'b00000110: After the FPGA executes all tests, the counters are reset. The FPGA should send back the SRAM contents at the address, then increment the counter. Note that the BeagleBone Black must invoke this command as many times as there are input vectors.
\end{itemize}

The FPGA may send the following commands: 
\begin{itemize}
\item 8'b00000000: Acknowledge of command received from BeagleBone Black.
\item 8'b00000001: This command is sent if the BeagleBone Black requests that all input vectors be executed, but no input vectors have been loaded.
\item 8'b11111111: Unknown command received.
\end{itemize}

Figure \ref{fig:uart_vector_transfer} details  how a template, force-format, cycle, or input vector is sent to the FPGA. 126 bits consist of the vector data while the uppermost two bits (T1 and T0) indicate which template the vector is associated with. Thus, up to four template vectors are allowed.

\begin{figure}
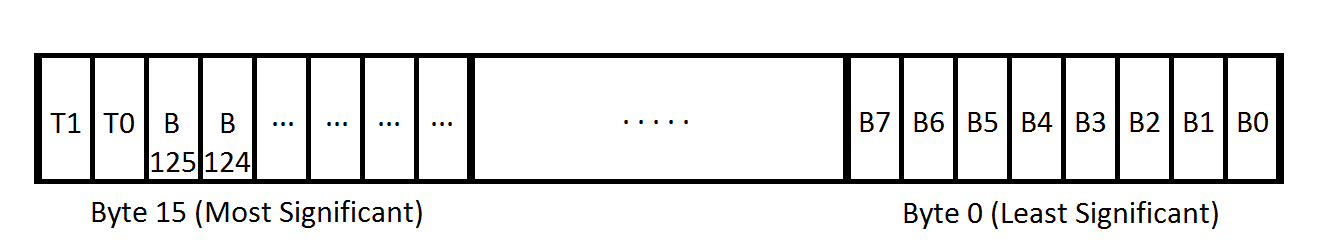
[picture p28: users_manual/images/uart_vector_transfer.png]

\caption{UART bit-vector transfers.}
\label{fig:uart_vector_transfer}
\end{figure}

\subsubsection{Block RAM Controller}
The block RAM on the Spartan-6 FPGA is configured to support 13-bit addresses, 32-bit reads/writes, and dual-port access. Block RAM is partitioned into four sections, as shown in Figure \ref{fig:block_ram_layout}. Note that all bit vectors are 128 bits in length, so any read/write requires two accesses (using two ports allows for 64-bit reads/writes per clock cycle).

With 32 kilobits of block RAM available, the FPGA can store 256 vectors. Up to four template vectors, and thus four FF and cycle vectors, are supported, allowing for a total of 244 input vectors to be stored.

The controller abstracts this partitioning of block RAM, enabling users to read/write a specified type of vector. The controller also keeps track of how many input vectors have been read/written during test execution.

\begin{figure}
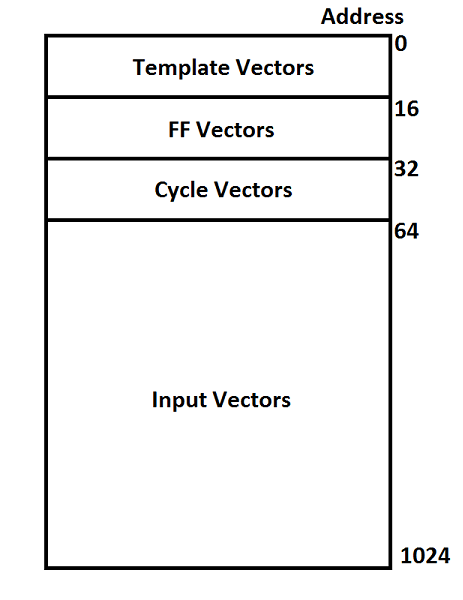
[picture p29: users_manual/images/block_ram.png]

\caption{Block RAM layout.}
\label{fig:block_ram_layout}
\end{figure}

\subsubsection{Counter Controller}
This controller allows a user to advance or reset the counter.

\subsubsection{DUT Controller}
This controller consists of double-buffered registers for test-cycle logic. Figure \ref{fig:block_ram_layout} illustrates our symbol for a double-buffered register, and Figure \ref{fig:test_cycle_logic} illustrates the logic per input vector bit.

The idea is as follows: an input vector bit (SIG), along with the associated FF bit, CYCLE bit, and TEMPLATE bit are loaded into double-buffered registers. 
\begin{itemize}
\item The FF bit denotes whether SIG should follow R0 or DRNZ L logic.
\item The CYCLE bit denotes whether SIG should force its value on the DELAY 1 or DELAY 2 edge. 
\item The TEMPLATE bit denotes whether SIG maps to an input on the DUT (in which case the tristate buffer is enabled) or an output of the DUT (in which case the tristate buffer is disabled).
\end{itemize}

Once all of the appropriate signals have been loaded into the double-buffered registers, they may be transferred at the beginning of a test cycle. Note that separate load and transfer signals are associated with each double-buffered register (not shown in Figure \ref{fig:test_cycle_logic}). 

\subsubsection{Output Buffer Controller}
This controller provides two commands: load the output buffers (parallel-to-serial shift registers) with whatever signals lie on the inputs, and clock the contents of the output buffers into the FPGA. Note that because the shift-registers are daisy-chained on the DUT Board, we deliberately picked very slow registers. As such, the controller carefully accounts for the propagation delay of the chips.

\subsubsection{SRAM Controller}
This controller allows a user to configure the CS, OE, and WE lines on the DUT Board's SRAM blocks.

\subsubsection{UART Controller}
This controller notifies when data has been retrieved over UART and allows users to abstractly transmit data over UART. Note that data read/written is always 16 bytes (128 bits).

\subsection{Central FSM}
With nearly 60 states, explaining the operation of this FSM through a state-flow diagram is intractable. Again, users seeking more information should study the Verilog code itself. We summarize the FSM's operation as follows: 
\begin{enumerate}
\item Remain IDLE until UART data is received.
\item Decode the UART command.
\item If we are told to expect a template/force-format/cycle/input vector: 
  \begin{enumerate}[label=\arabic*.]
    \item Transmit an acknowledgement.
    \item Wait for the vector to arrive.
    \item Store the vector in block RAM.
    \item Transmit an acknowledgement.
    \item Return to IDLE.
  \end{enumerate}
\item Else, if we are told to expect test cycle configuration data: 
  \begin{enumerate}[label=\arabic*.]
    \item Transmit an acknowledgement.
    \item Wait for the vector to arrive.
    \item Store the DELAY 1, DELAY 2, WIDTH, and LENGTH data into designated registers.
    \item Transmit an acknowledgement.
    \item Return to IDLE.
  \end{enumerate}
\item Else, if we are told to execute tests: 
  \begin{enumerate}[label=\arabic*.]
  	\item If no input vectors exist, transmit an error and return to IDLE.
    \item Load the first input vector from block RAM into the corresponding double-buffered register.
    \item Using the upper two bits of the input vector, load the corresponding template, force-format, and cycle vectors into the corresponding double-buffered registers.
    \item  Transfer all of the double-buffered registers' contents, then load the test cycle. 
    \item Fetch the next input vector from block RAM. 
    \item If the template bits of the new input vector are the same, load the input vector bits and transfer them at the end of the test cycle.
    \item Else, pause real-time testing, fetch the corresponding template, force-format, and cycle vectors from block RAM into the corresponding double-buffered registers.
    \ Transfer the new vector bits and resume testing.
    \item If more input vectors exist, go to step 2.
    \item Else, transmit an acknowledgement.
    \item Return to IDLE.
  \end{enumerate}
\item Else, if we are told to transmit SRAM data: 
  \begin{enumerate}[label=\arabic*.]
    \item Load the SRAM data into the output buffers.
    \item Clock in the SRAM data from the output buffers.
    \item Transmit the data back to the BeagleBone Black.
    \item Return to IDLE.
  \end{enumerate}
  \item Else, transmit an error code and return to IDLE.
\end{enumerate}

Regarding hardware signals: 
\begin{itemize}
	\item SRAM should be enabled in \textit{write-mode} at the beginning of a test cycle and disabled at the trailing edge of a test cycle.
	\item SRAM should be enabled in \textit{read-mode} when reading data into the output buffers.
	\item After a test cycle, counters should be incremented. After all test cycles are executed, counters should be reset.
	\item Voltage translators are always enabled except when reading from SRAM.
	\item Output buffers are disabled except when reading from SRAM.
\end{itemize}

\begin{figure}
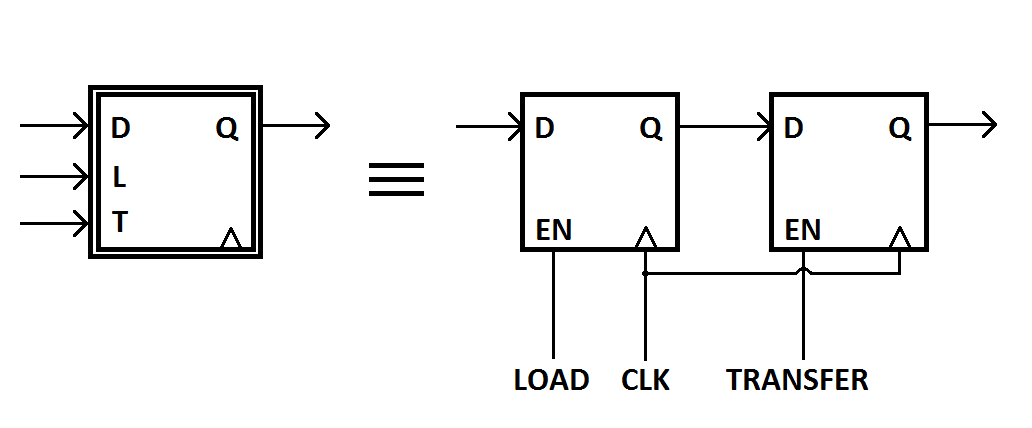
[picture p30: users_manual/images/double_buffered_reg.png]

\caption{Double-buffered register symbol.}
\label{fig:double_buf_reg}
\end{figure}

\begin{figure}
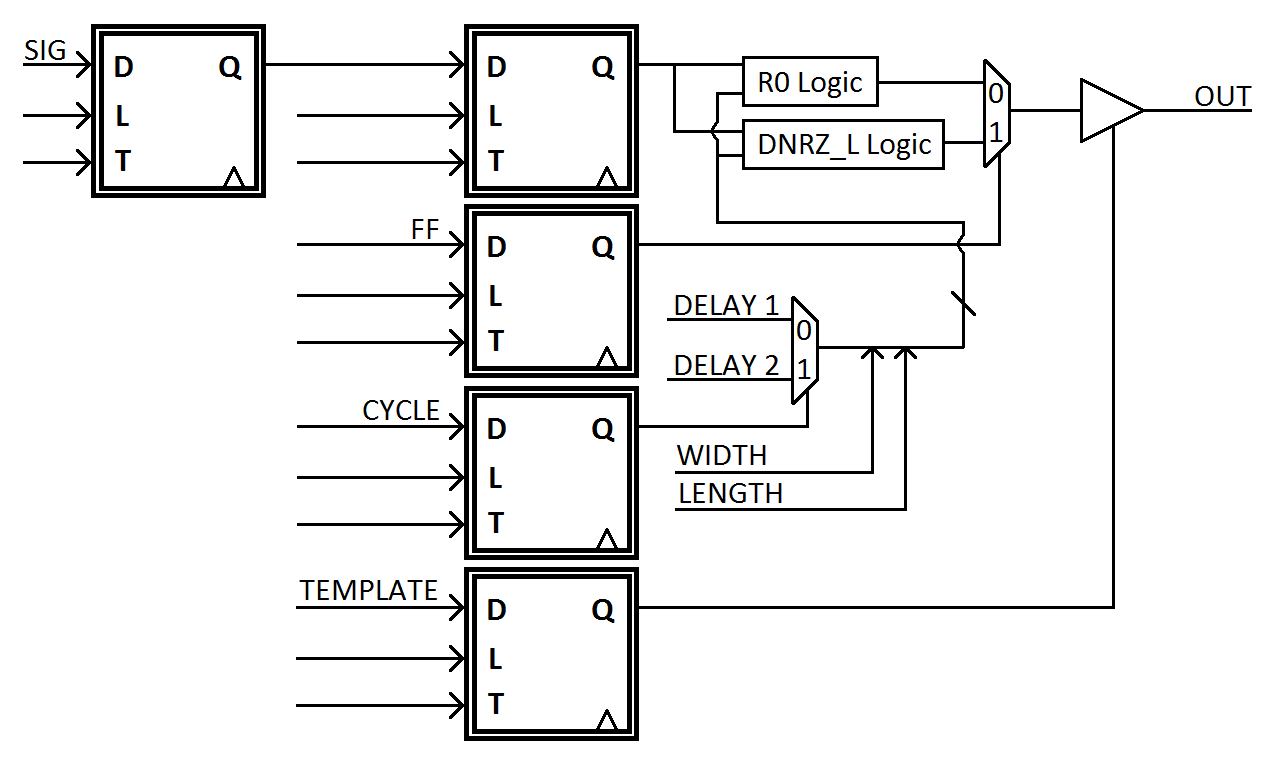
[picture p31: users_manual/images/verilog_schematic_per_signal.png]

\caption{Test cycle logic.}
\label{fig:test_cycle_logic}
\end{figure}

\subsection{PCB Boards}
Figure \ref{fig:three_pcbs} shows the three PCBs that we designed for this project. Figure \ref{fig:final_schematic} shows how the three PCBs interact with each other. Figure \ref{fig:final_schematic_per_pin} shows the schematic that we implemented for every input/output vector bit; note that the implementation spans all three PCBs.

\begin{figure}
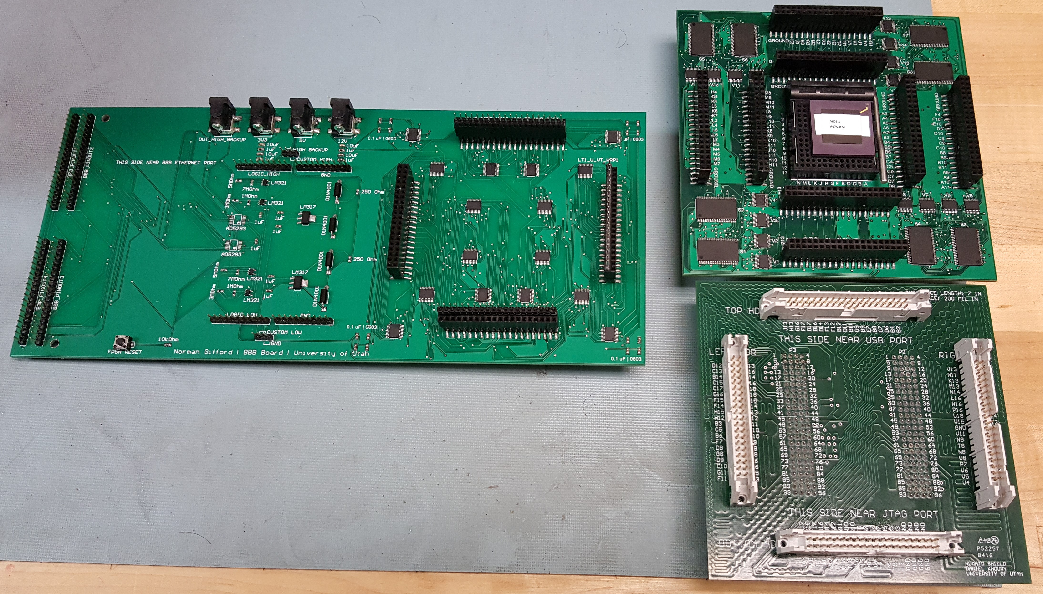
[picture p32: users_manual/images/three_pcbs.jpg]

\caption{Clockwise from left: Communication Board, DUT Board, Numato Shield.}
\label{fig:three_pcbs}
\end{figure}

\begin{figure}
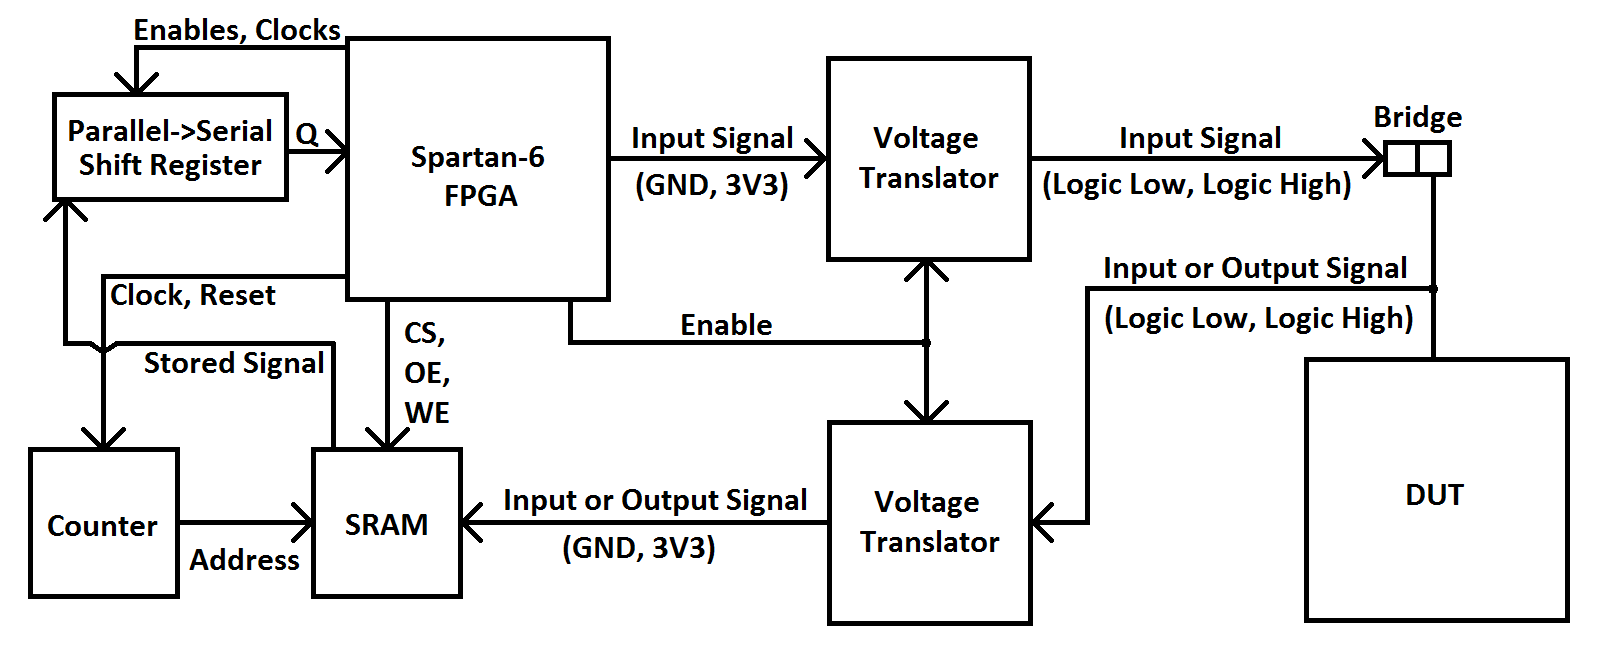
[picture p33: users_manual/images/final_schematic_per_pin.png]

\caption{Schematic implemented (across all three boards) for input/output vector bits.}
\label{fig:final_schematic_per_pin}
\end{figure}

\begin{figure}
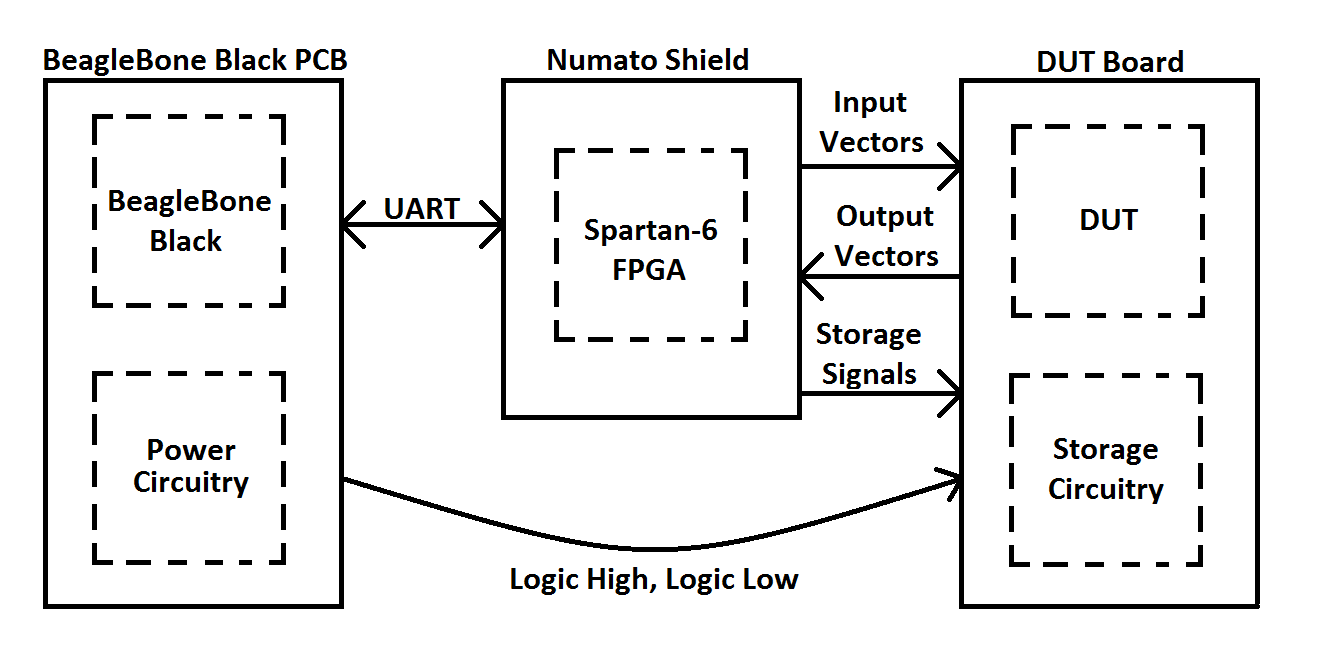
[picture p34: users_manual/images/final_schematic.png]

\caption{How the three PCBs serve each other.}
\label{fig:final_schematic}
\end{figure}

It is important to note that Figure \ref{fig:final_schematic_per_pin}, in the top-right of the image, shows a bridge effectively between the FPGA and DUT. There is one hard problem to answer when designing any ASIC tester: what do we do if the user accidentally designates an output of the DUT as an input? 

Fuses are one option, but they're bulky and can take several seconds before breaking. We investigated the use of resettable fuses, which are essentially resistors whose resistance increases exponentially in response to increases in thermal energy, but they merely taper off the current rather than physically break the connection. We decided that our best option of handling shorts is to allow users to bridge connections between the FPGA and DUT with a 1 Ohm resistor, rated at 0.125 Watts. These resistors should burn quickly in case of a short and are easily replaceable, though we are unsure if this mechanism can prevent damage to both the DUT and the surrounding circuitry in the case of a short.

\subsubsection{Numato Shield}
This four-layer board simply routes all 150 I/O pins from the Numato board to four headers. 

By manually routing the board, we were able to achieve equilibrium tracing; all traces are within 200 mils of each other. Routing took approximately two weeks. Of the three PCBs that we designed, only this board features equilibrium tracing. The other two boards (especially the DUT Board) were too dense to allow for equilibrium tracing.

\subsubsection{DUT Board}
This four-layer board houses the following components: 
\begin{itemize}
\item A 13x13 ZIF socket (top of the board) to house the DUT.
\item Eight headers (top) used to bridge connections between the DUT and signals from the FPGA board. Note that bridges are performed by using a 1 Ohm resistor to tie both pins in a row of the header. The innermost pin goes to the DUT, the outermost pin to the FPGA. Also note that power and ground must be manually connected via jumper wires from the Communication Board.
\item Four headers (bottom of board) to connect to the Communication Board (see below).
\item Eight SRAM ICs (top), four counter ICs (bottom), 16 high-to-low (logic high value of DUT to 3.3V) level shifter ICs (top), and 16 parallel-to-serial shift register ICs (bottom). 
\end{itemize}

Routing this board proved to be extremely difficult. Initially, Altium's autorouter failed to route a good chunk of the connections after three hours. With strategic component placement, we were able to get the autorouter to route all but one connection after 100 minutes. 

It is worth noting that because of the large number of counters and SRAM blocks, we became concerned that the load seen by an FPGA pin driving, for instance, all of the SRAM WE pins may be large enough to cause problems. As such, we use separate FPGA pins for the CS and WE signals of each SRAM block, as well as the clock of each counter, to help reduce the load seen by these pins.

\subsubsection{Communication Board}
Conceptually, this two-layer board is relatively simple. However, it's proven to be our most problematic board. 

From the perspective of the board in Figure \ref{fig:three_pcbs}, the left of the board serves as a shield for our BeagleBone Black. For versatility, we pinned out all of the unused BeagleBone Black pins onto headers (extreme left of board). 

The middle section of the board houses our power circuitry for variable high and low voltages. We initially opted for four separate power connections (12V, 5V, 3.3V, and a backup high voltage in case the power circuitry failed) out of concern that the current draw from a single voltage supply may cause loading effects. 

The right of the board simply connects signals from the Numato shield to the DUT board, with low-to-high level shifters (3.3V to the logic high value for the DUT) used for any input vector bits. 

Routing the board was somewhat tedious; Altium's autorouter required about 40 minutes, and we had to route a few signals manually. We've had two bigger problems with this board, however: 
\begin{enumerate}
	\item The first time we fabricated the board, we saw smoke after soldering the power circuitry components and connecting 3.3V to the system. We later found that 3.3V was shorted to GND. Altium did not show a short between the two signals, so although we did not probe the board before soldering our components, we believe a manufacturing error caused the short. (An aside: Our BeagleBone Black was connected to the PCB at the time, and the short appeared to have somehow erased some of the data on the BeagleBone Black. As of now, we restored the data onto the BeagleBone Black and it appears to work fine.) 
	\item The second time we sent the board for fabrication, we ordered two versions: one with power and ground planes, and one without. In the case of another power-to-ground short, our hope was that we could find the short on the board that lacked power planes. Fortunately, both boards arrived free of any power-to-ground shorts. Unfortunately, we still saw smoke. We came to realize that we mistakenly reversed the power and ground connections on the barrel jack connectors that we used, but reversing those connections with pigtail connectors failed to fix the problem.
\end{enumerate}

Before we leave, we plan to scrutinize the board for any issues that we may have missed. We also plan to reduce the number of barrel jack connectors needed by using regulators to create 3.3V and 5V (a backup logic high value compatible with VLSI chips designed using the 0.6 micron process).

\newpage

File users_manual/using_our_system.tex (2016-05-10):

\section{Using Our System}
Using our system is simple: 
\begin{enumerate}
\item If the system is not turned on, connect all necessary power connections. The BeagleBone Black requires 5V and an ethernet cable; the FPGA requires a 5V; the Communication Board requires 12V and 5V. 
\item Plug the DUT into the ZIF socket.
\item Access, fill out, and submit our web form \href{http://line-norm-gifford.cs.utah.edu:8080/}{here}.
\end{enumerate}

\subsection{Repository and Website}
Our repository is currently located \href{https://github.com/normgiff/Masters}{here} and our website \href{http://normgiff.github.io/Masters/}{here}.

\newpage

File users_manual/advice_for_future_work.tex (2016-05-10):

\section{Advice for Future Work}

\subsection{More Advanced FPGA}
Although the Spartan-6 FPGA served its purpose, our tester would be far more powerful if a Xilinx 7-series FPGA is used in place. Reasons: 
\begin{itemize}
	\item Unlike the Xilinx 6-series FPGAs, the 7-series FPGAs are designed to handle large clock speeds. A faster internal clock allows for more granularity when configuring test cycles. According to Xilinx ISE, we cannot clock our Verilog design faster than about 150 MHz (we left the internal clock speed at 100 MHz as a safety measure). 
	\item There are likely 7-series FPGAs that offer more block RAM than the 6-series FPGAs. Although our system supports up to four templates and 244 input vectors - likely enough for most student-designed chips - having room for more templates and input vectors certainly wouldn't hurt.
\end{itemize}

As of this writing, the 7-series FPGA boards are generally very expensive (on the order of thousands of dollars), with the exception of the Artix-7 FPGA. It is also worth noting that Xilinx recommends (and in some cases requires) Vivado over ISE for programming 7-series FPGAs.

\subsection{Equilibrium Tracing}
Equilibrium tracing on all of the PCBs is ideal for accurate timing information of the chip. Equilibrium tracing may be possible if more than 3 PCBs are designed, though the costs of manufacturing add up quickly.

\subsection{BeagleBone Black Development}
Our ideas for expanding upon the BeagleBone Black include: 
\begin{itemize}
	\item Storing test configurations and test results in a \textbf{database}, e.g. with mySQL. We included a microSD card in the BeagleBone Black to help facilitate this expansion.
	\item Requiring users to set up usernames and passwords, and requiring a login to perform a test. This constraint allows users to more easily find their stored test configurations and results, and also helps ensure that only student runs a test at a time.
	\item Using some library to generate schmooing plots.
\end{itemize}

\newpage

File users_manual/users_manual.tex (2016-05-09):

\documentclass[letterpaper, 12 pt]{report}

\usepackage{color}
\usepackage{hyperref}
\hypersetup{
    colorlinks,
    linktoc=all,
    citecolor=black,
    filecolor=black,
    linkcolor=black,
    urlcolor=blue
}
\usepackage{enumitem}
\usepackage{graphicx}
\graphicspath{ {images/} }
\renewcommand\thesection{\arabic{section}}
% -------------------------------------------------------------------------------------
% BEGIN DOCUMENT
% -------------------------------------------------------------------------------------
\begin{document}
\title{LV600 User's Manual}
\author{Authors: \\ Alfred Norman Gifford IV \\ Daniel Khoury \\ \\ Project Advisor: \\ Ken Stevens \\ \\ University of Utah}
\maketitle
\pagestyle{empty}

% -------------------------------------------------------------------------------------
% TABLE OF CONTENTS
% -------------------------------------------------------------------------------------
\tableofcontents
\newpage

% -------------------------------------------------------------------------------------
% ALL OTHER SECTIONS
% -------------------------------------------------------------------------------------

\input{introduction.tex}
\input{lv500_overview.tex}
\input{senior_project_overview.tex}
\input{masters_project_design_choices.tex}
\input{masters_project_implementation.tex}
\input{masters_project_overview.tex}
\input{using_our_system.tex}
\input{advice_for_future_work.tex}
\input{bom.tex}
\input{special_thanks.tex}
\input{contact_info.tex}

% -------------------------------------------------------------------------------------
% REFERENCES
% -------------------------------------------------------------------------------------
%\bibliography{}

% -------------------------------------------------------------------------------------
% END DOCUMENT
% -------------------------------------------------------------------------------------
\end{document}

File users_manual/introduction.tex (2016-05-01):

\section{Introduction and Motivation}
At the University of Utah, students enrolled in Digital VLSI Design (CS/ECE 5710/6710) work in teams to design an integrated circuit (IC) for their final project. Optionally, students may send their chip designs to MOSIS, an IC foundry, for fabrication. As per MOSIS's rules, students who fabricate their chip designs are required to test their received chips and report their results back to MOSIS. 

At least one student from any team that chooses to fabricate their chip must enroll in CS/ECE 6712, which teaches students how to test their chips using a device called an application-specific integrated circuit (ASIC) tester. Presently, the University of Utah has two ASIC testers: a Verigy 93000 and a Tektronix LV500. As of this writing, both machines are in troubled states. The Verigy 93000 is no longer operational due to a hard drive failure. The LV500 has many failed sectors, so the system as a whole may prove unreliable when testing a chip. 

Simply purchasing a new ASIC tester is not feasible. ASIC testers are extremely expensive machines (millions to billions of dollars) --  partly because of a niche market, but mainly because they are incredibly difficult systems to engineer, construct, and maintain. 

Our project, which we term the LV600, is an ASIC tester based largely upon the LV500. The project's intention is to provide an ASIC tester that is good enough for most student-designed VLSI chips. This document serves as both the final report for our project and the user's manual for the system that we hope to ultimately provide to the University. 

In this document, we also include ideas for how to build upon our project, and we strongly encourage students to consider building an ASIC tester for their senior project if they have any interest in such machines. The project provides so many learning experiences -- it's conceptually simple, but the devil lies in the details. 

\newpage

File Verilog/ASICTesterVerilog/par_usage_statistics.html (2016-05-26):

Par Statistics

Total Non-vccgnd Signals=5178

Total Non-vccgnd Design Pins=26408

Total Non-vccgnd Conns=26408

Total Non-vccgnd Timing Constrained Conns=24741

Phase 1 CPU=4.6 sec

Phase 2 CPU=5.1 sec

Phase 3 CPU=18.8 sec

Phase 4 CPU=19.5 sec

Phase 5 CPU=29.8 sec

Phase 6 CPU=29.8 sec

Phase 7 CPU=29.8 sec

Phase 8 CPU=29.8 sec

Phase 9 CPU=29.8 sec

Phase 10 CPU=30.8 sec

AvgWirelenPerPin Fanout 1=2.0

AvgWirelenPerPin Fanout 2=1.5

AvgWirelenPerPin Fanout 3=0.7

AvgWirelenPerPin Fanout 4=2.8

AvgWirelenPerPin Fanout 10=3.5

AvgWirelenPerPin Fanout 50=2.0

AvgWirelenPerPin Fanout 100=10.2

AvgWirelenPerPin Fanout 500=8.3

AvgWirelenPerPin Fanout 5000=5.0

AvgWirelenPerPin Fanout 20000=0.0

AvgWirelenPerPin Fanout 50000=0.0

AvgWirelenPerPin Fanout 100000=0.0

IRR Gamma=6.0326

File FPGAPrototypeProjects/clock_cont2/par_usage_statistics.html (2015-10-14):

Par Statistics

Total Non-vccgnd Signals=78

Total Non-vccgnd Design Pins=284

Total Non-vccgnd Conns=284

Total Non-vccgnd Timing Constrained Conns=176

Phase 1 CPU=10.8 sec

Phase 2 CPU=11.0 sec

Phase 3 CPU=11.1 sec

Phase 4 CPU=14.6 sec

Phase 5 CPU=14.7 sec

Phase 6 CPU=14.7 sec

Phase 7 CPU=14.7 sec

Phase 8 CPU=14.7 sec

Phase 9 CPU=14.7 sec

AvgWirelenPerPin Fanout 1=4.0

AvgWirelenPerPin Fanout 2=6.0

AvgWirelenPerPin Fanout 3=2.0

AvgWirelenPerPin Fanout 4=2.3

AvgWirelenPerPin Fanout 10=6.3

AvgWirelenPerPin Fanout 50=7.6

AvgWirelenPerPin Fanout 100=0.0

AvgWirelenPerPin Fanout 500=0.0

AvgWirelenPerPin Fanout 5000=0.0

AvgWirelenPerPin Fanout 20000=0.0

AvgWirelenPerPin Fanout 50000=0.0

AvgWirelenPerPin Fanout 100000=0.0

IRR Gamma=1.0024

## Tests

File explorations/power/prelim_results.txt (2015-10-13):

Using a value of R1 = 490 ohms and this equation:

R2 = R1*((Vout/Vref) - 1)

Where Vref = 1.25V (equation taken from the datasheet).

R2 should be 1470 ohms to get an output of 5V.
Setting R2 to that value produces an output of 5.03V.

R2 should be 1274 ohms to get an output of 4.5V.
Setting R2 to that value produces an output of 4.49V.

So far, things are looking good!

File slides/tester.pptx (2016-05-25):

## Testing with the LV-500

- Tektronix LV-500
- Built in 1989-1991
  - I.e. Ancient technology!
  - eBay is a good source for spare parts these days…
- Specifically designed to be a stand-alone tester for ASICs
  - I.e. More testing features than a basic logic analyzer

## What’s an ASIC Tester?

- Ours is built on a Tektronix DAS 9200 logic analyzer platform
- The main differences are in the test head, the pattern/error cards, and the Schmoo
  - The test head has up to 256 bi-directional pins where each pin has programmable electronics
    - voltage drive, current drive, voltage sense, etc.
  - The pattern/error cards store and compare the test vectors at up to 50MHz
    - fast for 1989!
  - A Schmoo lets you run repeated tests while the tester alters one or two independent variables like threshold, delay, cycle length, voltage, etc.

## Flavors of LV500s

- Common Features
  - Test speeds up to 50MHz
  - Up to 64,000 unique test vectors
  - Network connection for uploading tests
    - Thinlan ethernet
  - 8 Meg of RAM
  - 21 or 43 Meg hard drive
  - 5.25 floppy (1.2M floppy)

## Flavors of LV500s

- LV514
  - 192 test channels (12 sectors)
    - 160 are usable (two sectors are bad)
  - Pre-wired test card for class chips
  - (should really be called LV513, but that’s a long story)
- LV512
  - 128 test channels (8 sectors)
    - All channels are usable
  - Used mostly for tutorial purposes
    - No pre-wired class chip test card yet…

## LV514

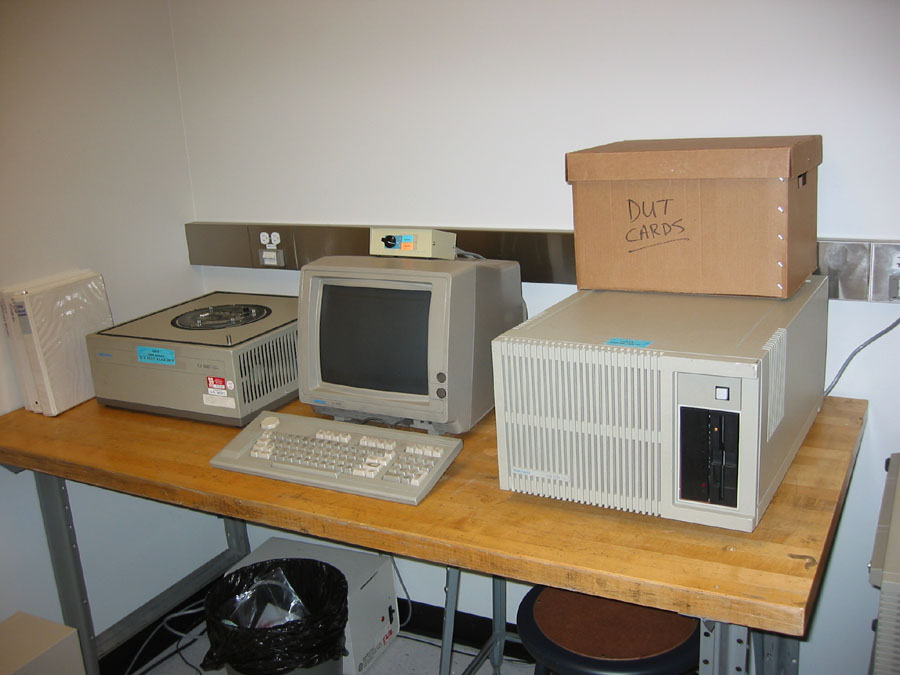
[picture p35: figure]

## LV512

## The Big Picture

1010010100100
1001000010100
1110101001110
1010100010011
0100100010001

Input Vector Table

DUT
(Device
Under
Test)

Compare

Actual
Output
Vectors

Pass/Fail
Display

Expected
Output
Vector
Table

11010100101010
11110101010101
00101001010100
10010100010101
01010010010101

Expected
Output
Vectors

## The More Detailed Picture

- Conceptually this is simple, in practice there are lots of details…
  - Define the input and expected-output vectors
    - Can do this using your Verilog simulations
  - Define which signals are inputs and outputs on your chip
  - Define how those signals are mapped to tester channels
  - Wire up the DUT card so that those channels map to your chip pins
  - Define the timing and electrical characteristics of your test

## Three Essential Parts of a Test

1. A properly wired DUT (Device Under Test) card
  - This electrically connects each of your chip pins to the correct tester channels
2. A properly configured LV-500
  - Configure the timing of when inputs are applied, when outputs are checked, what the voltages and currents are, etc.
3. A complete set of test vectors
  - Vectors are applied and checked on each cycle
  - “Force data” are inputs to your chip
  - “Compare data” are expected outputs from your chip

## Tester Channels

- The 256 possible pins (channels) on the test head are grouped into 16 “sectors” labeled 0-f
  - Each sector has 16 channels
  - Labeled sector.channel (I.e. 0.2, d.3, a.c)
- On each cycle, each channel may be either a “force” channel or a “compare” channel, but not both
  - If you have bi-directional pins on your chip, you need to define which are inputs and which are outputs on each cycle!

## DUT Card

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
## LV514 Usable Channels

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
## LV512 Usable Channels

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
## DUT Card Sectors & Channels

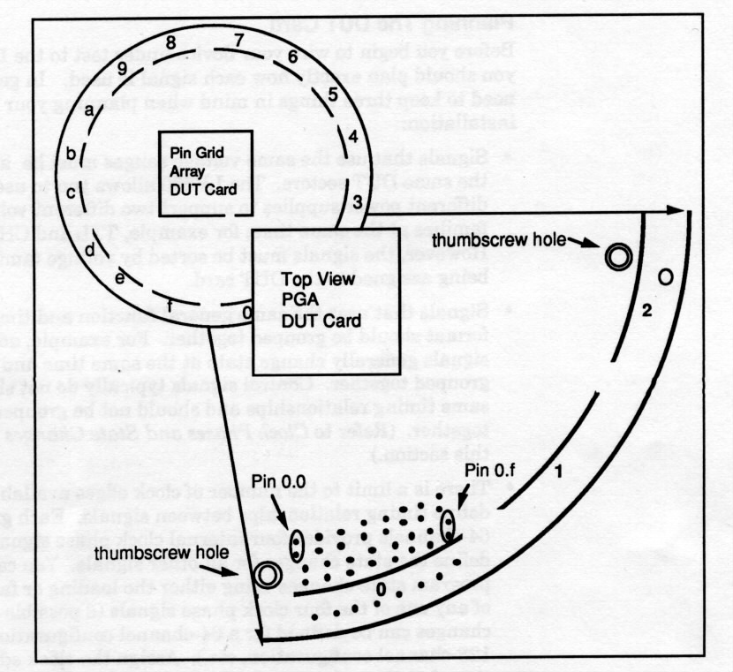
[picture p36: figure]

## DUT Cards

- The DUT cards are how you wire from tester channels to chip pins
- These cards also have VDD, VTT and GND power supply connections
  - VDD and VTT are two independently controllable power supply voltages

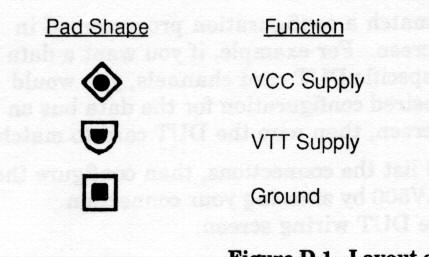
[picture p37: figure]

## Wiring the DUT Card

- Essentially two choices:
  - Solder wires on a PGA DUT card
    - Remember that VDD and GND are not connected to tester channels
    - Probably only want to do this once for the whole class
    - Which means standardizing VDD and GND!
  - Use a “Quick-Connect” card
    - Uses 3M Scotch-Connect to wire (using wire-wrap wire) from the tester channels to the chip socket
    - Can also use quick-connect for VDD and GND

## Quick-Connect DUT Card

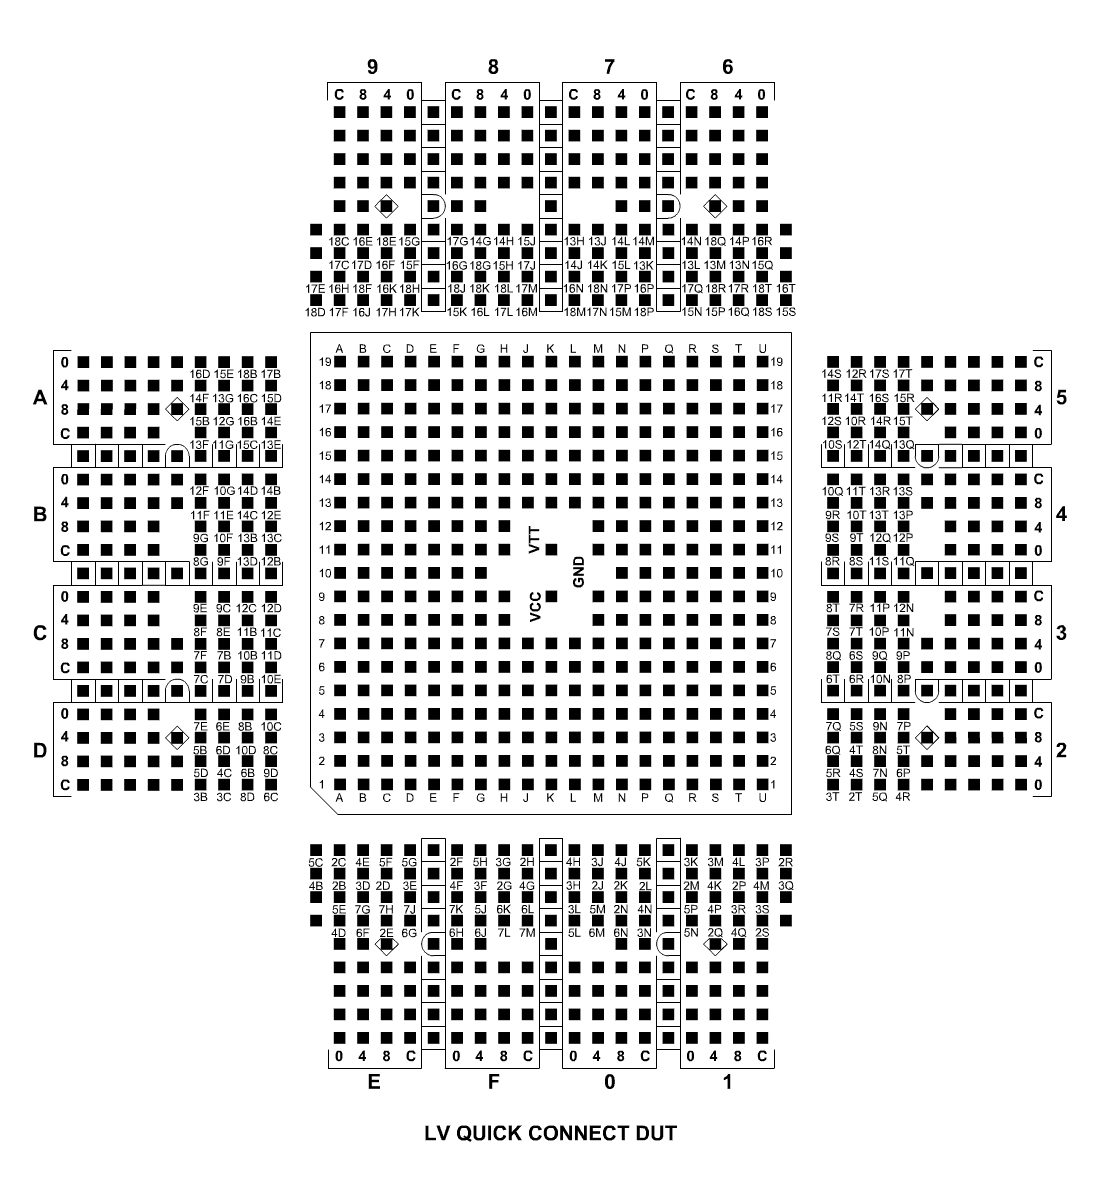
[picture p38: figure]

## Quick-Connect DUT Card

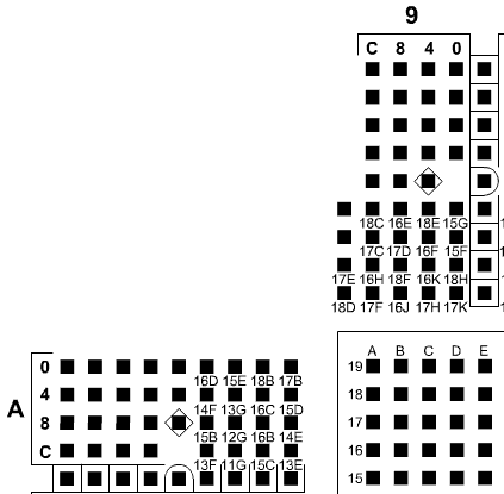
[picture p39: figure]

## Knowing What to Wire

- A “Bonding Diagram” is a picture that shows how your chip was bonded to the chip frame
- It also shows how the chip frame is connected to the chip pins

## Bonding/Chip Diagram

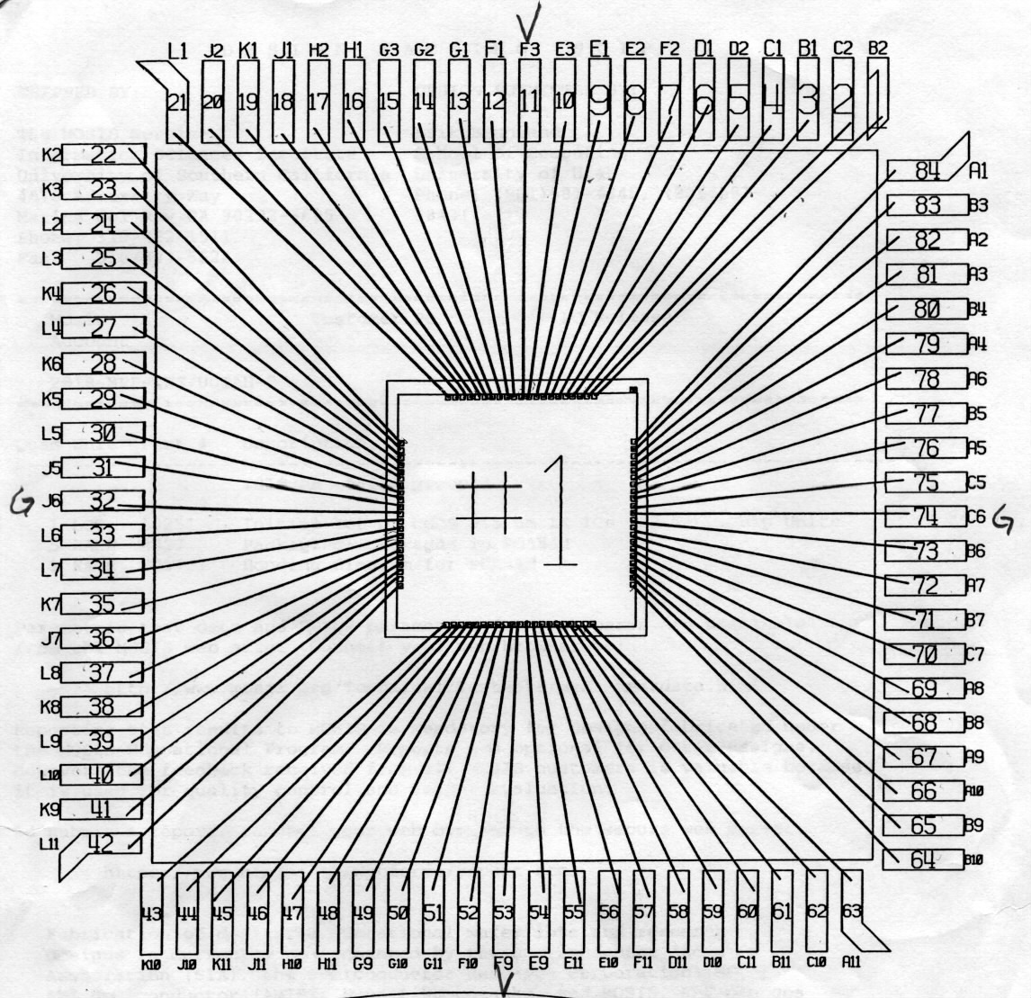
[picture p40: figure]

## Map Your Pins to Channels

- Pick tester sector.channel assignments for each of your pins
  - Signals that need the same voltage characteristics should be grouped in the same sector
    - Each sector gets common voltage ranges
    - More on this later…
  - Signals that need the same timing should be grouped in the same quadrant
    - Sectors 0-3, 4-7, 8-b, c-f are the four quadrants
    - More on this later…
  - Wire things up!
    - Remember to keep a list of what you’ve wired!

## Class DUT Card

- Pre-wired for class chips
  - 84 pin PGA with specific VDD and GND placements in the pad ring
  - /usr/local/contrib/elb/lv500/DUTmap.txt

## DUTmap.txt

PAD-PIN-TESTER CHANNEL MAP FOR CS/EE 5710 DUT CARD
Pad locations are taken from MOSIS bonding diagram
PGA locations are taken from 84pin PGA bonding diagram
Tester channels 6,7,8,9,A are used. The notation is sector.channel
Vdd and GND connections are as per 5710 standard pad frame
TESTER SIGNAL
PAD PGA sec.chn NAME (no spaces)
1 B02 6.C
2 C02 7.7
3 B01 6.B
4 C01 7.6
5 D02 7.D
6 D01 7.C
7 F02 GND GND
8 E02 8.1
9 E01 8.0
10 E03 8.7
12 F01 8.6
13 G01 8.A etc….

## Finished DUT Card

- Now you have part 1 – a wired DUT card that connects your chip to the tester
- On to part 2 – configuring the tester…

## LV512 Boot Menu

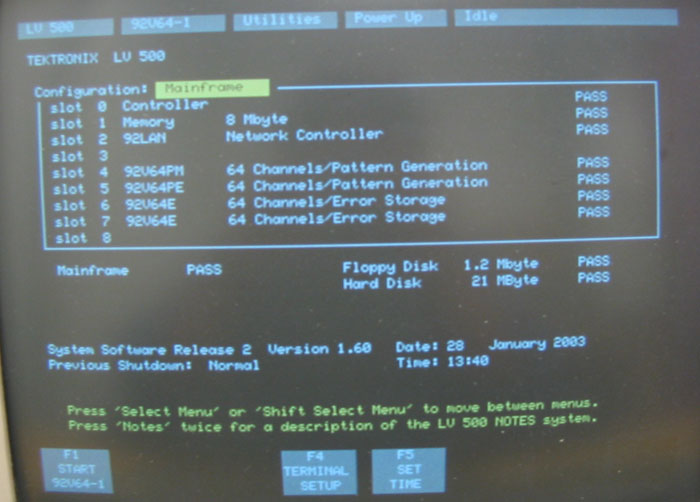
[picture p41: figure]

## LV500 Main Menu

## LV500 Keyboard Layout

## Important Menu Choices

- Config Menu
  - Defines voltages for VDD, VTT, GND
  - Defines voltages for two force/compare sets
- DUT Wiring menu
  - Defines how your signals are assigned to tester sector.channels
- Channel menu
  - Defines how your signals are collected into groups (I.e. buses)
    - ALL signals must be a part of some group
    - Groups are assigned to specific timing templates (clock phases)

## Important Menu Choices

- Template Menu
  - Defines timing of tests
    - When to force data?
    - When to compare data
    - When to ignore data?
- Schmoo Menu
  - Defines which variables to vary, and by how much
- Pattern Menu
  - Defines data vectors for each tester cycle

## Basic Procedure…

- Tell tester which chip signals are connected to which channels (DUT wiring menu)
- Combine signals into groups (Channel menu)
- Define timing for each group (Template menu)
  - Only four “clock phases” per quadrant
  - A “template” assigns clock phases to groups, and timing of clock phases…
- Define patterns (Pattern menu)
  - Each pattern starts with a template
  - Includes force, compare, and mask data for each test cycle

## Config Menu

- Defines the electronics for this test
  - VDD, VTT, GND, current limit, etc.
- You can also define two different “force” and “compare” voltage sets for data channels
  - Each sector uses one of these two sets

## Config Menu (diagram)

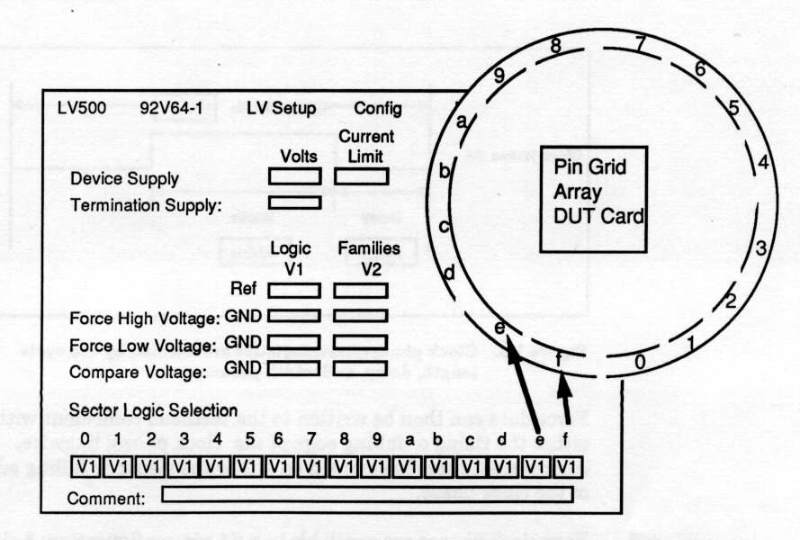
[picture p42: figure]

## Config Menu (LV512)

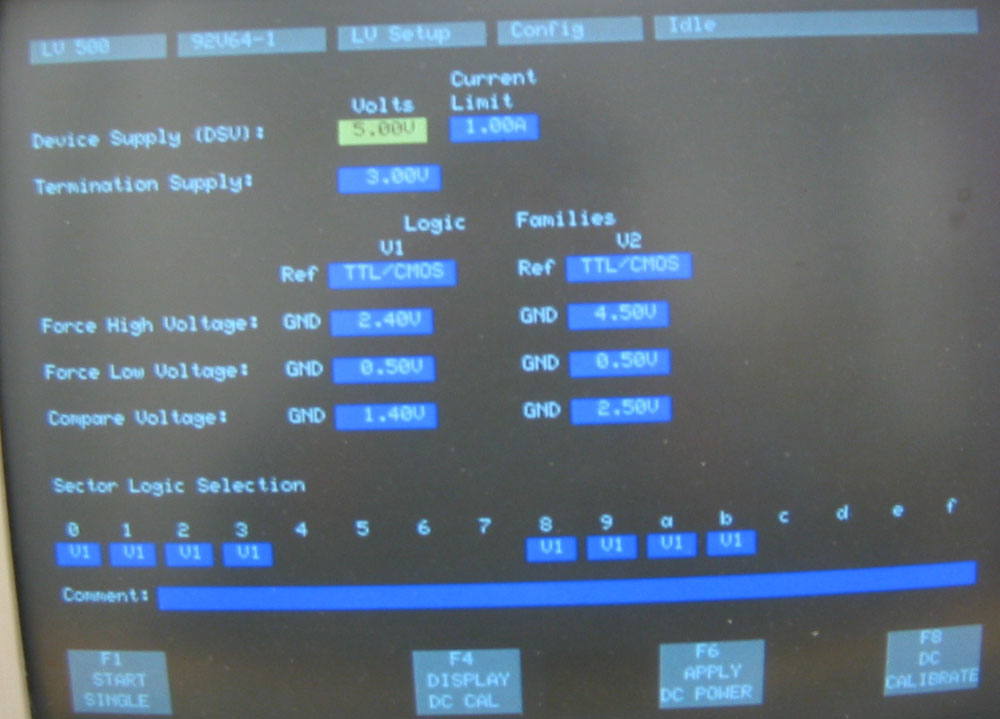
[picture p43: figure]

## DUT Wiring Menu

- Defines how your signals are assigned to tester sector.channels
  - List signal names
  - Define which tester channels they connect to
  - Optionally define which actual chip (DUT) pins they are connected to
    - This is just a comment for documentation

## DUT Wiring Menu

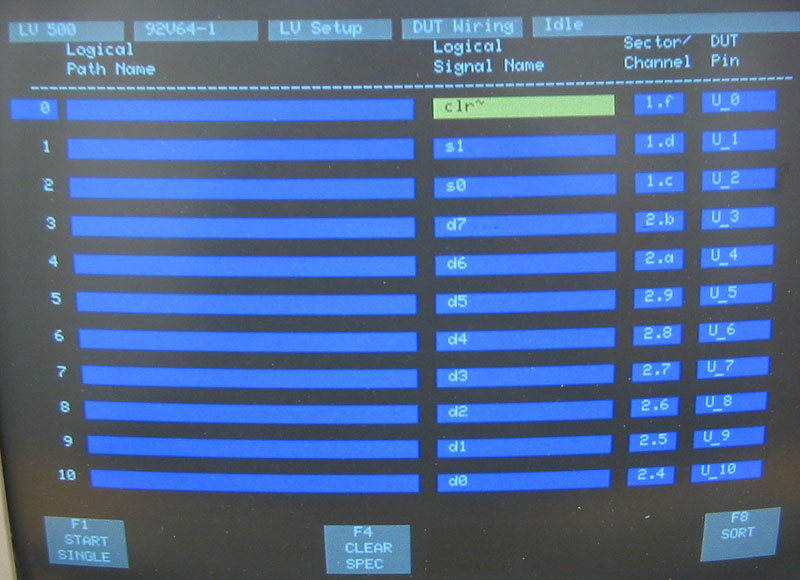
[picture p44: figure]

## Channel Menu

- Defines how your signals are collected into groups
- EVERY signal must be a part of some group (even single signals)
  - Groups can make data entry and evaluation easier
  - Can define how group data is printed
    - Dec, Hex, Oct, Bin
  - Can specify timing once for the whole group
  - In general, inputs vs. outputs is a good group…
    - Or control vs. data, etc.

## Channel Menu (LV500)

## Channel Menu (LV500)

## Templates

- Templates
  - Defines timing of tests
    - When to force data?
    - When to compare data
    - When to ignore data?
  - Set up using a “clock phase”
    - Bad name – really a timing waveform
    - Defines when things happen in each tester cycle
  - You can define up to four clock phases per quadrant

## Clock Phases

  - Cycle Length: 20ns – 496ns
  - Delay is delay to Leading Edge
    - Can be 0ns
  - Width is delay from Leading to Trailing edge

## DUT Card Quadrants


Each quadrant has up to four timing waveforms you can use to control signal timing (called “Clock Phases” in LV500-speak)

## Force Formats

  - Within a clock phase, you can define when values are “forced” to your chip in relation to the edges

## Force Formats Example

  - This is an example of a pattern driven on five consecutive tester cycles with each of the different force formats


## Compare Formats

  - You can also define when you Compare outputs in relation to the clock phase edges

## Template Menu

## Pattern Menu

- Defines data vectors for each tester cycle
  - Data for each signal is defined in the data vector
  - Some of those signals are “Force”, some are “Compare” and some are “Mask”
    - These are set in the templates
    - Assign a template to each vector
    - On each tester cycle, the next vector, with that vector’s template, is applied to the DUT and compared

## Pattern Menu


## Pattern Display

- The Pattern screen is where you see the results of your test
  - Before the test you can see all the vectors (and their templates) that you will be using
  - After running the test you see the same display with any errors highlighted in red
    - Red means that the output of the DUT didn’t match the expected output vector
  - You run the test with F1-Start (the F1 function key)

## Successful Test


## Failed Test


## Schmoo Menu

- After you have your basic test working, you can run a Schmoo test
  - Repeat the test while changing 1 or 2 variables
    - Variables can be things like VDD voltage, delay time, cycle time. Compare voltage, etc.
  - Generates a graph showing where the part worked or didn’t work

## Schmoo Menu


## Schmoo Result


## Logistics

- The LV500 is old and cranky…
  - Basic rule – if you’re not SURE about what you’re doing, ask me first!!!!
    - Replacement parts are very hard (impossible?) to find.
  - Leave terminal ON
    - Turn down brightness when you leave,
    - Check brightness when you come into the lab
  - Do NOT turn the LV500 off without good cause!
    - We’ll leave the LV512 up and running for tutorials, and then switch to the LV514 when chips come back…

## Logistics continued

- Be very gentle with the DUT cards
  - They connect to the machine through elastomer connectors
    - These are basically rubber-like connectors wrapped with wire
    - They are very fragile, and a little worse for wear
    - We have no replacements…
- Schedule some time with me to run tests!
  - Once you’ve got some LV500 time under you belt you can go it alone…

## Tester Setup Simplified

- All this stuff can be defined in a .msa file
  - Module Setup, Ascii
  - Each section of the .msa file corresponds roughly to a tester menu
  - You can (fairly easily) write your own .msa file
    - Templates on /usr/local/contrib/elb/lv500/

## Tester Setup with msa Files

- You can ftp to the lv500 and upload the .msa file which defines your test
  - You can ONLY ftp from vlsi-nat.cs.utah.edu so ssh to there first!
  - lv512.cs.utah.edu, lv514.cs.utah.edu
  - No username/password required…
  - Put your .msa file into the Simulation directory on the LV500
  - Convert to tester setup using the LV Toolkit menu

## LV512 LAN Screen


## LV Toolkit Menu (LV512)


## LV Toolkit Issues

- Note that the conversion process goes to an ms_04_4.msp file (or something close to that)
  - You are not allowed to change this name!
  - If you want to save this setup under a different name you need to convert to the standard name, and then save the setup to a new name using the Disk Services menu.
- Once the .msa is converted, you can look at the setup using all the previous menus

## Running Tests

- The .msa conversion is a great first step
  - But, after that’s running you may want to change things or try new things
    - Like Schmoo, or changing parameters
  - You can change the data using the menus shown earlier
  - You can also save the changed tests into new .msa files
  - And you can retrieve those new .msa files using FTP if you like

## Overview

- On every tester cycle the LV500:
  - Applies a set of signals to the DUT
    - The data to “Force” is defined in the Pattern
    - Which signals are “Forced” on this cycle is defined in the template
    - When the data are applied is defined relative to the “clock phase” template
    - The names of the signals and which tester channels they are on are defined in the DUT wiring menu
  - At the right time (defined in the template) the tester captures and compares the data from the DUT
    - Compares against the data in the Pattern

## Procedure

1. Get your bonding diagram and map where your signals are on your chip
2. Decide how those pins will map to tester channels (DUTmap.txt)
3. Decide on timing templates for all signals
4. Generate test vectors that include pin names, templates, and data vectors for every cycle
5. Put it all in a .msa file

## Procedure 2

6. Upload the .msa file to the LV500
7. Convert the .msa file to a tester setup file
8. Check all menus to make sure things are how you want them
  1. Config
  2. DUT wiring
  3. Channel
  4. Template
  5. Pattern

## Procedure 3

9. Fix or modify test parameters
10. Run your test
11. Look at the results
  1. Celebrate!
  2. Or diagnose and debug…
  3. Or decide to schmoo to get more info…

## Tutorial DUT Card

## Tutorial 1: 74LS547

- 3 to 8 decoder

## 74LS547


## 547 DUT Wiring


## 547 Template

## 547 Pattern

## 547 Schmoo

## Tutorial 2: 74LS299

- Shift Register, shift L or R, parallel load and output
  - Bidirectional data bus


## 74LS299 Timing

- Control should be set up ahead of the clock
- Data should be sampled after the rising edge of the clock
- Data should be driven after the control is set up
  - Avoid drive fights on bidirectional path


## 74LS299 Timing

Cycle = 200ns

- Control signals
- Clock
- Shift data

Delay = 0ns, Width = 100ns

Delay = 40ns, Width = 100ns

Delay = 20ns, Width = 80ns

## 74LS299 Shift/Clear Template

## 74LS299 Load Template

## 74LS299 Pattern

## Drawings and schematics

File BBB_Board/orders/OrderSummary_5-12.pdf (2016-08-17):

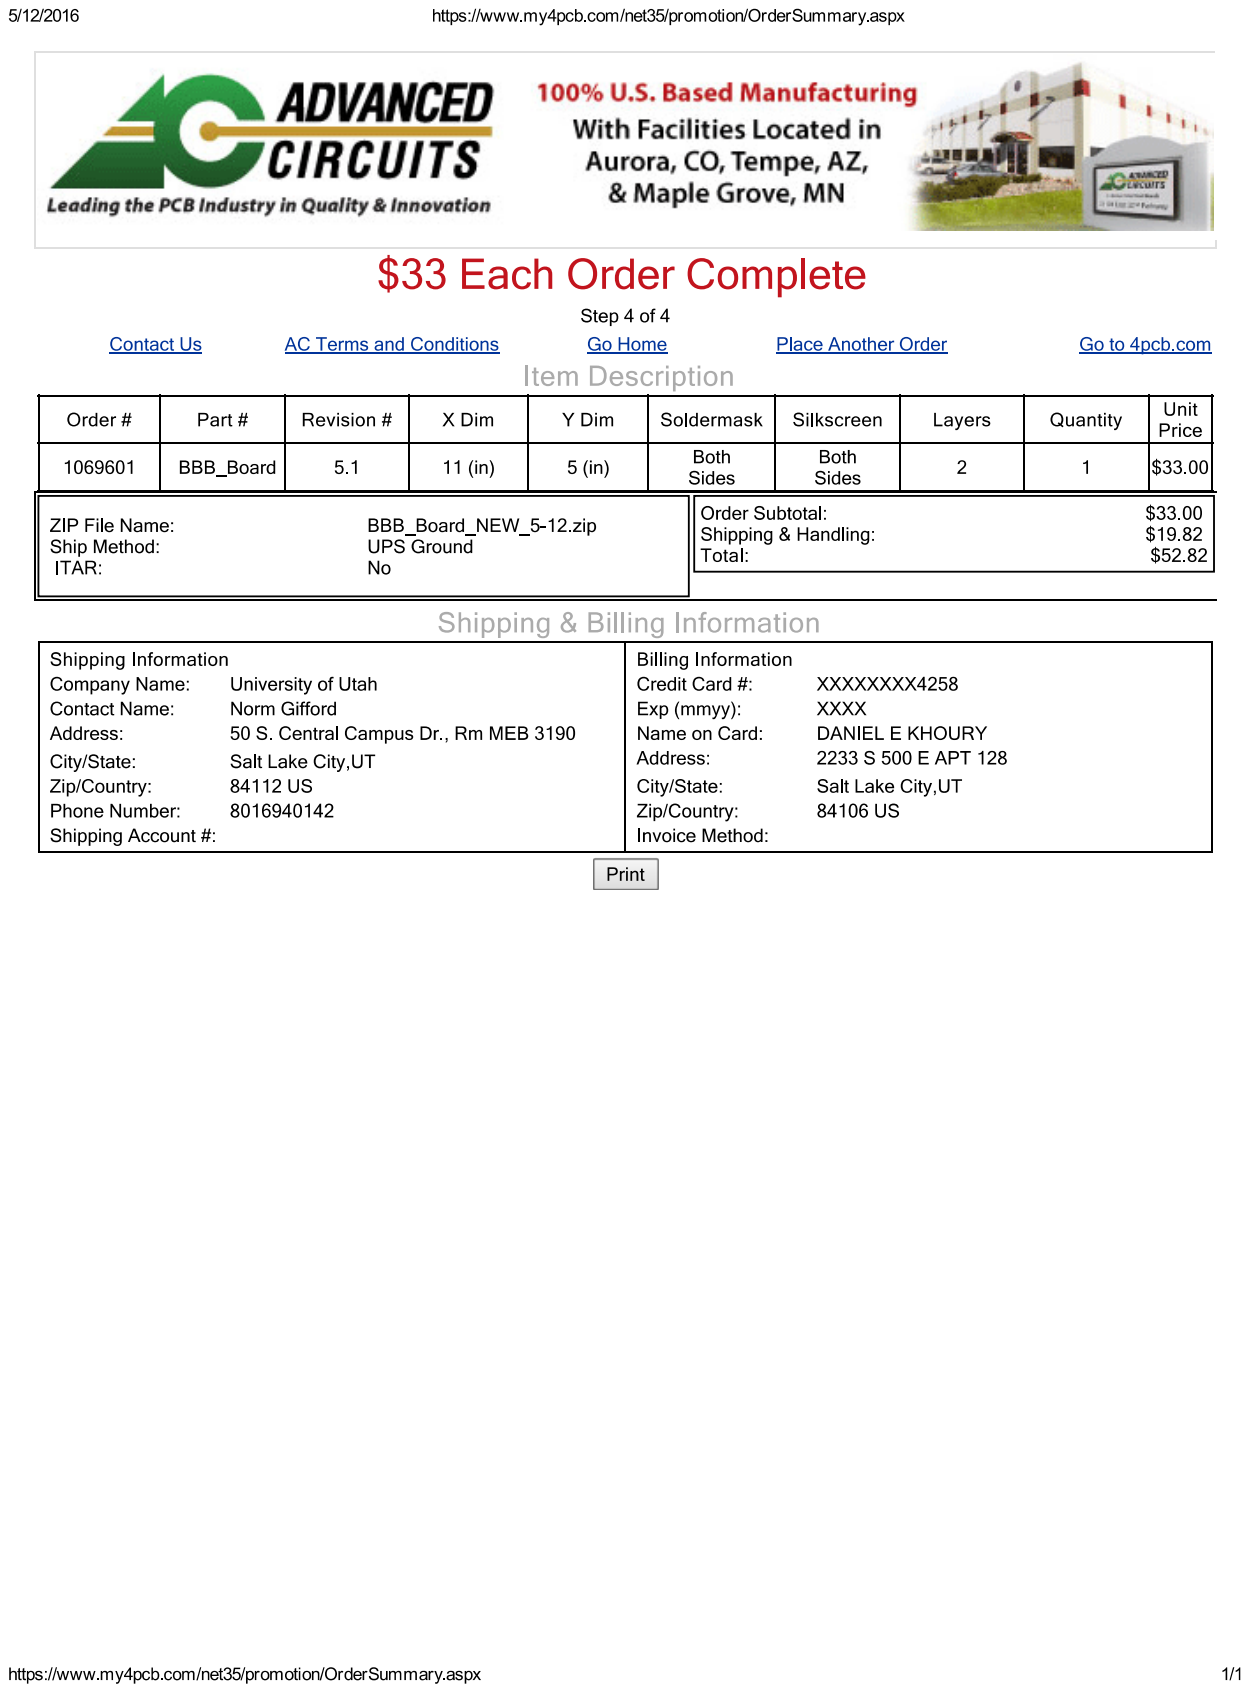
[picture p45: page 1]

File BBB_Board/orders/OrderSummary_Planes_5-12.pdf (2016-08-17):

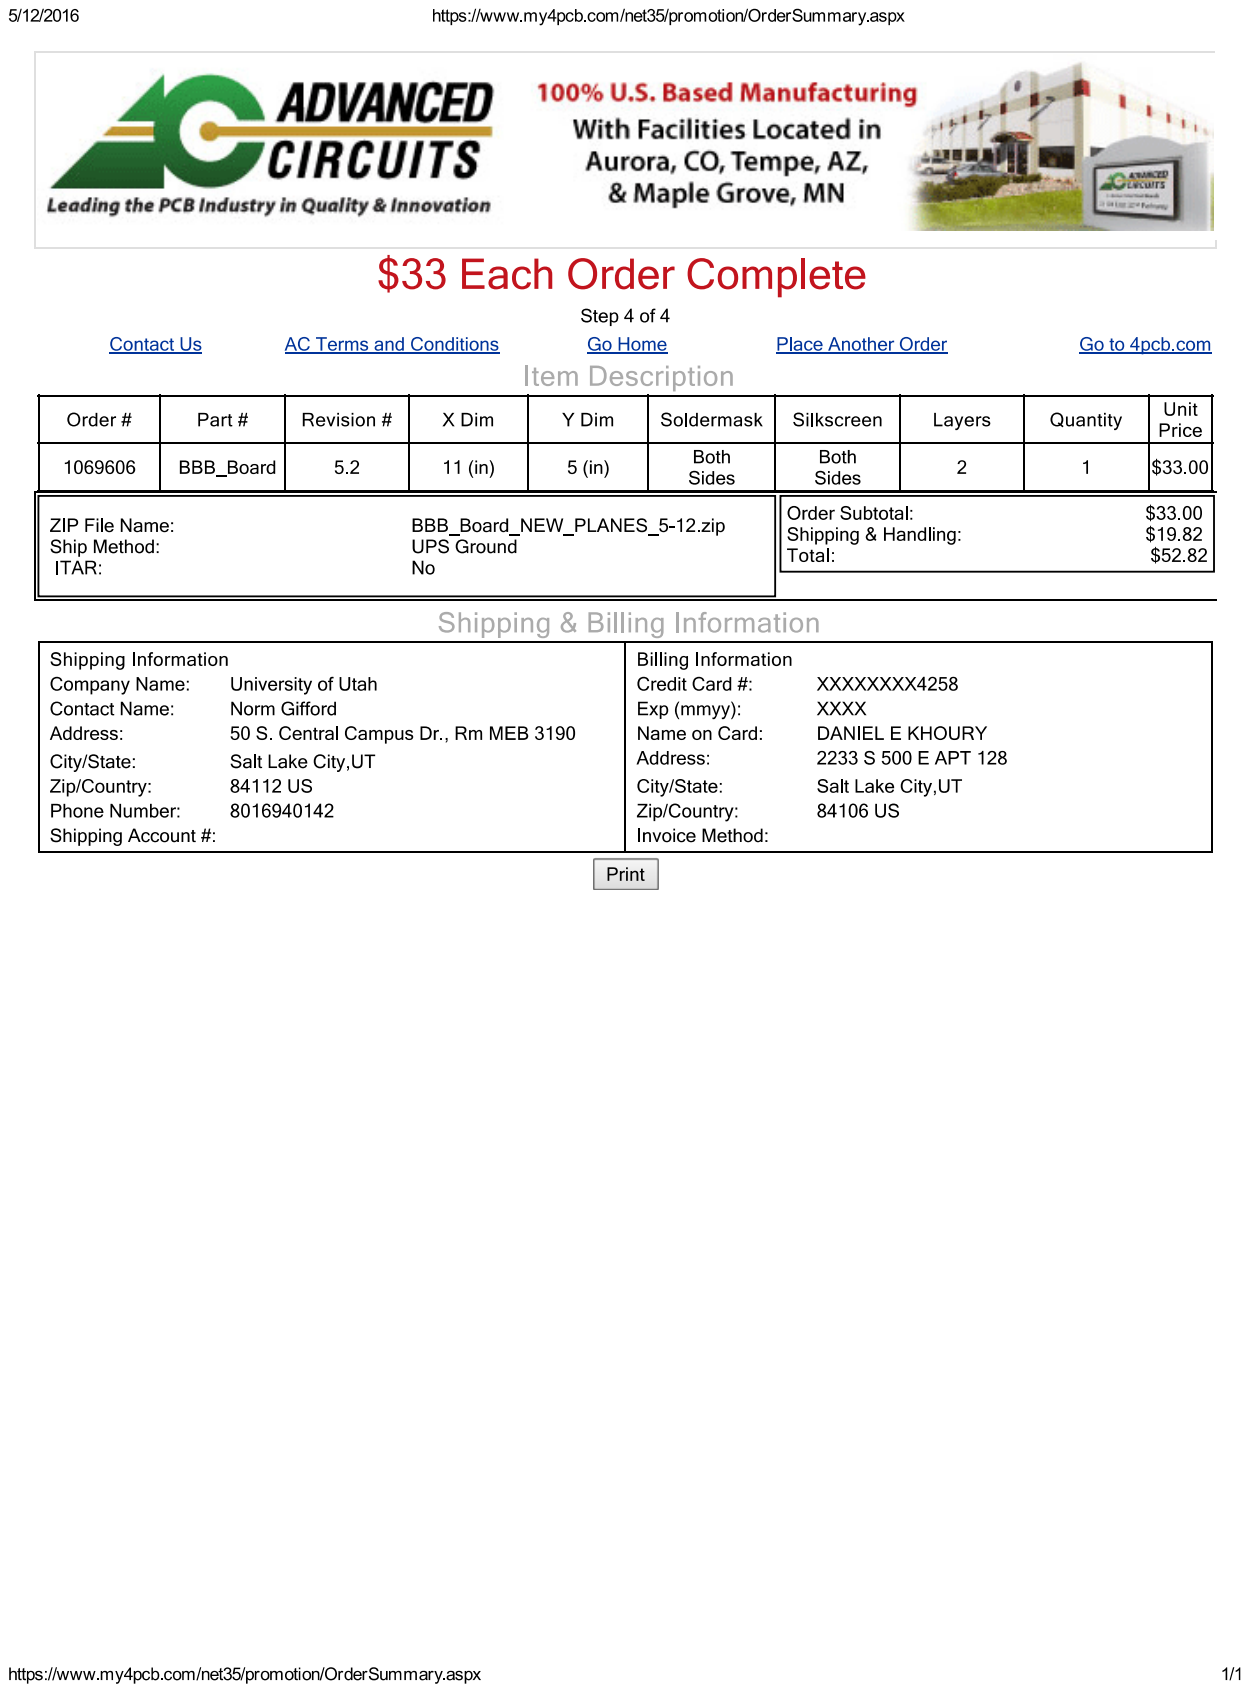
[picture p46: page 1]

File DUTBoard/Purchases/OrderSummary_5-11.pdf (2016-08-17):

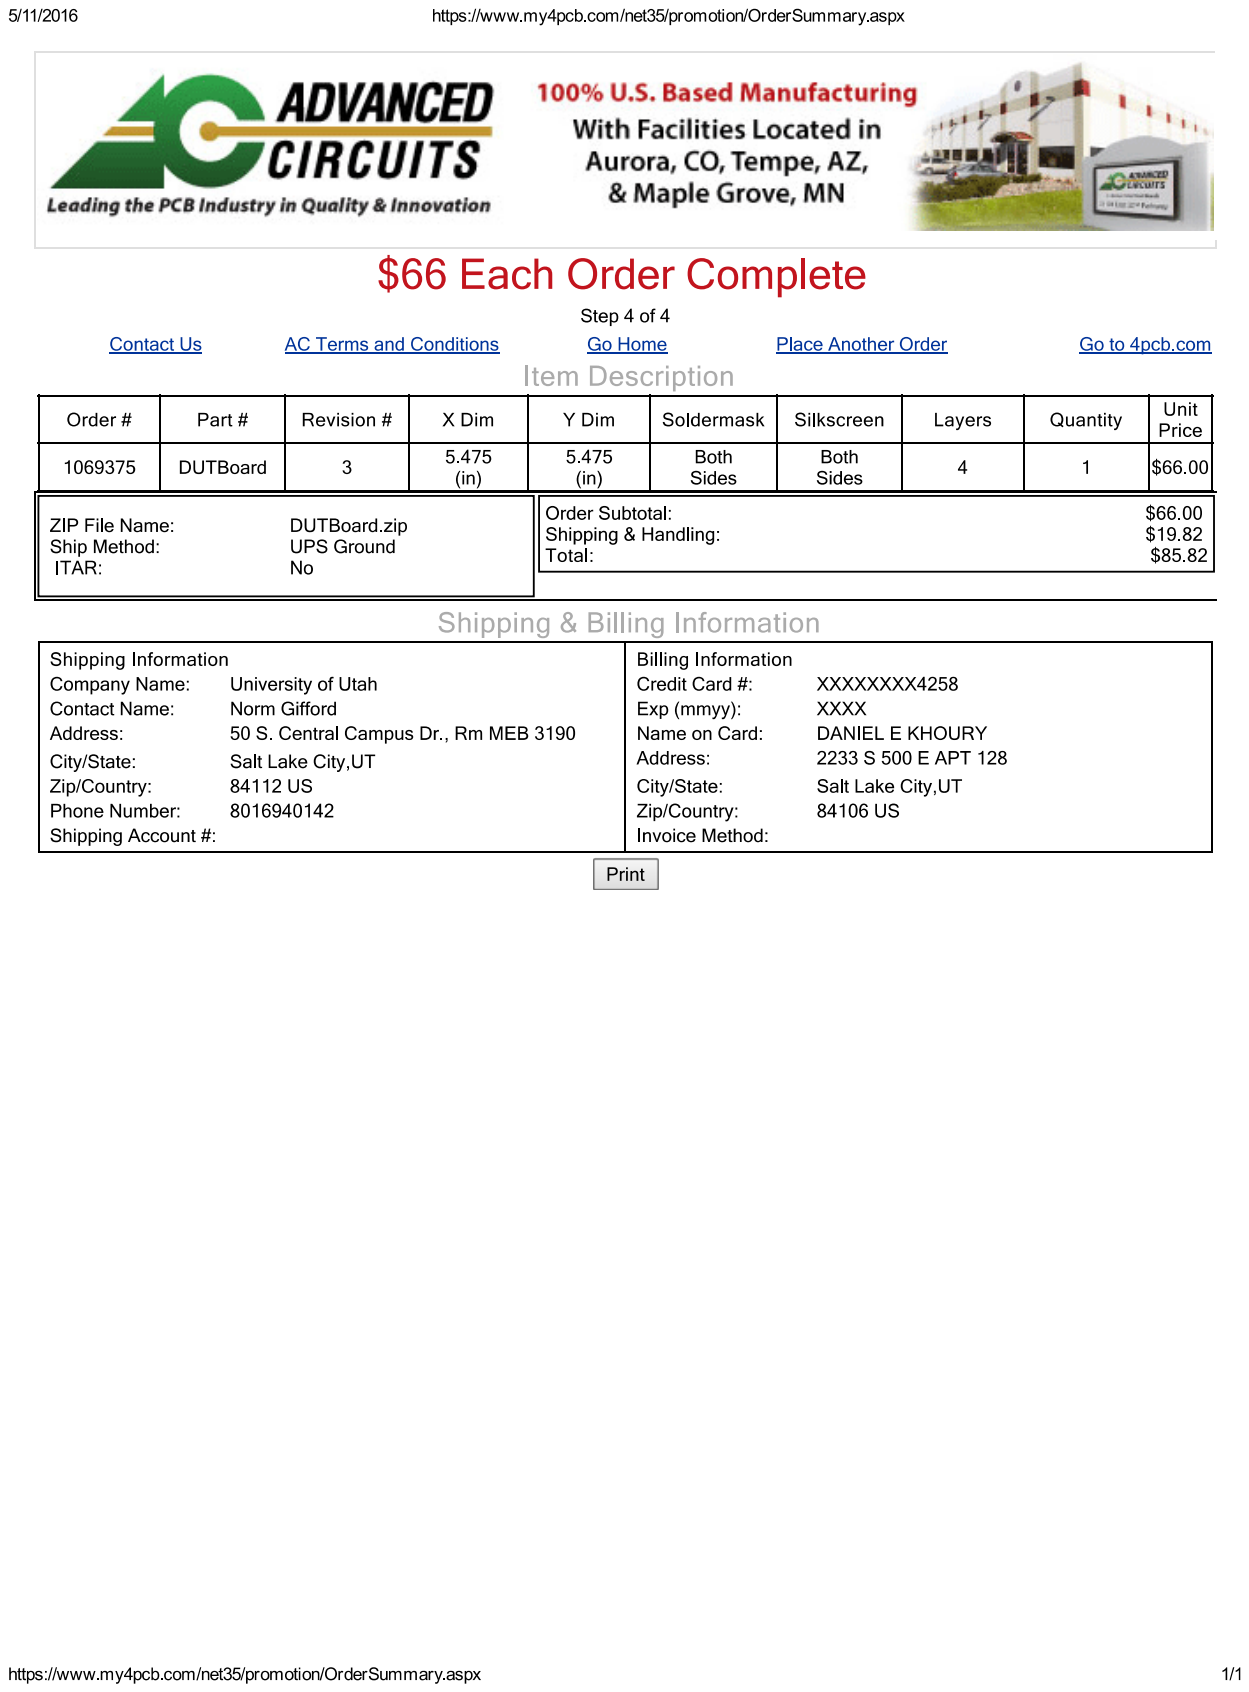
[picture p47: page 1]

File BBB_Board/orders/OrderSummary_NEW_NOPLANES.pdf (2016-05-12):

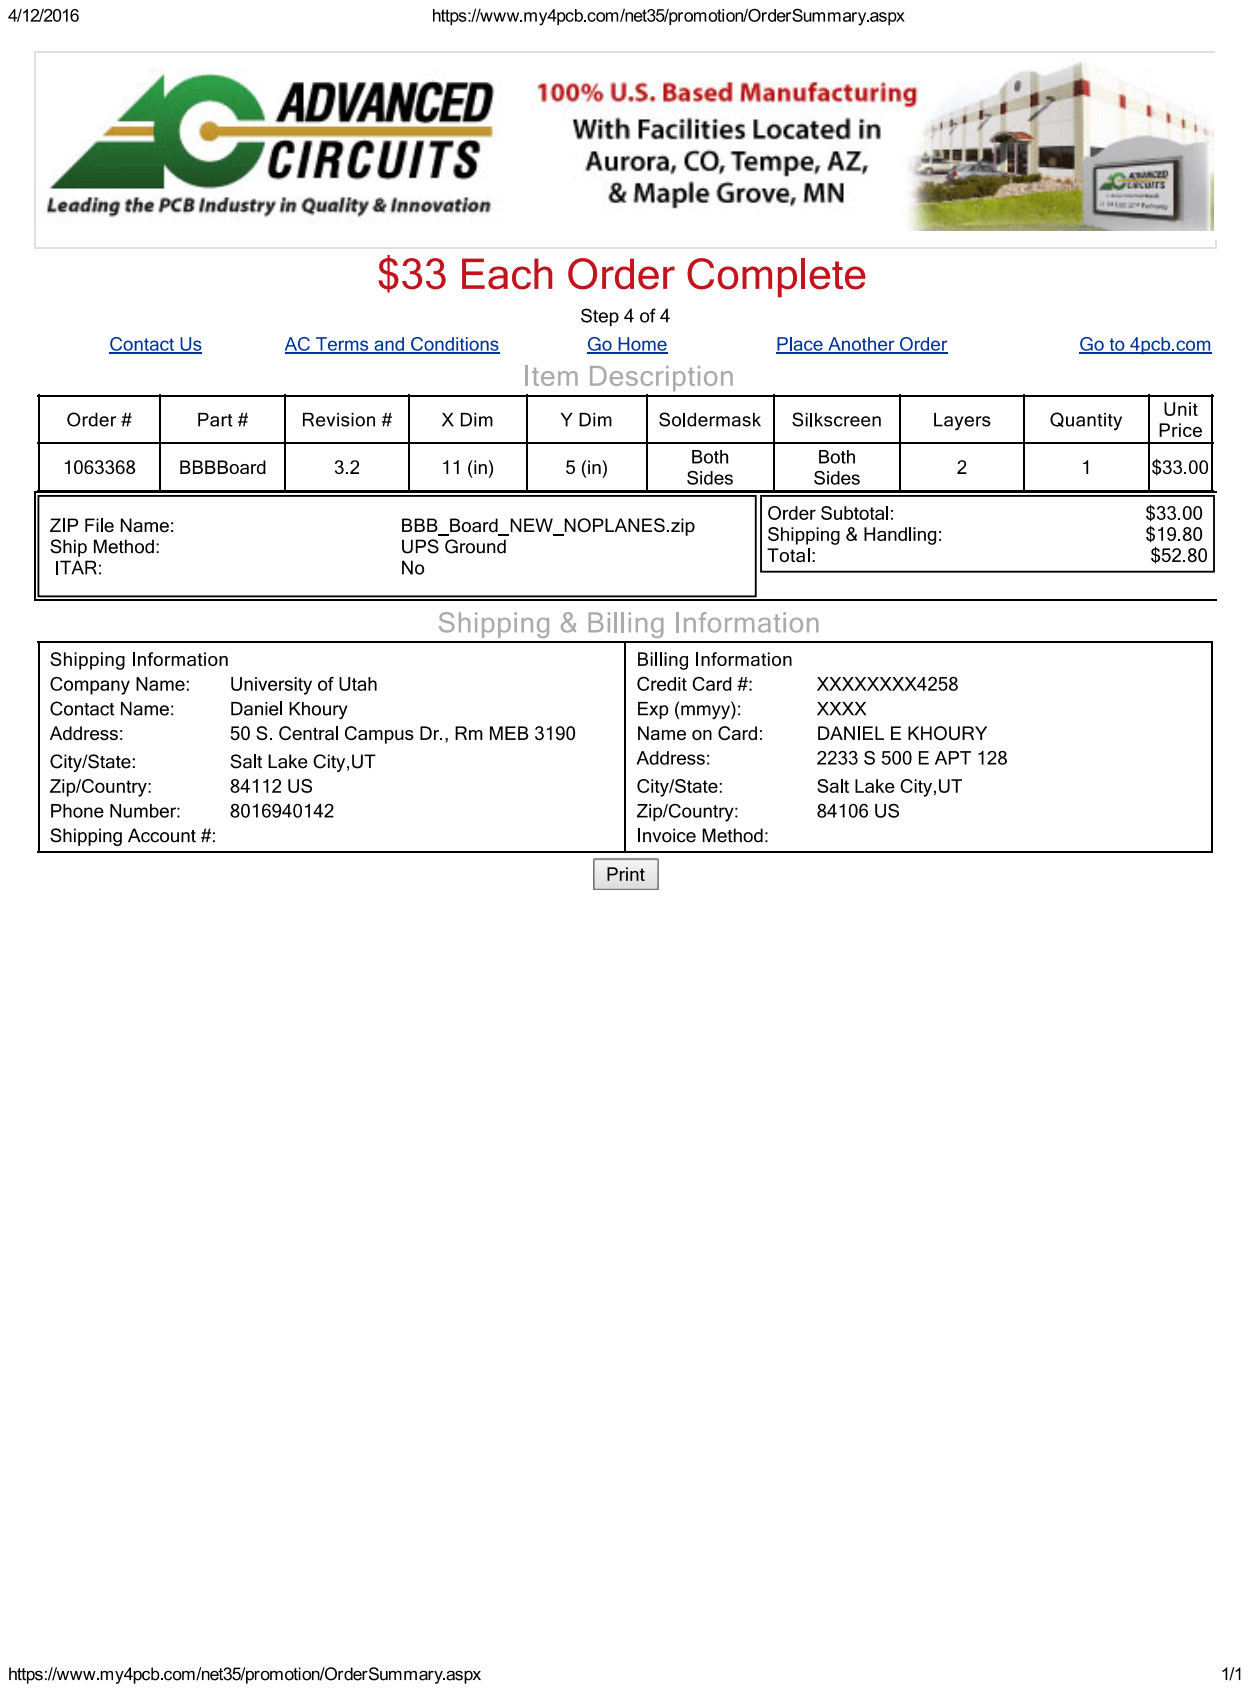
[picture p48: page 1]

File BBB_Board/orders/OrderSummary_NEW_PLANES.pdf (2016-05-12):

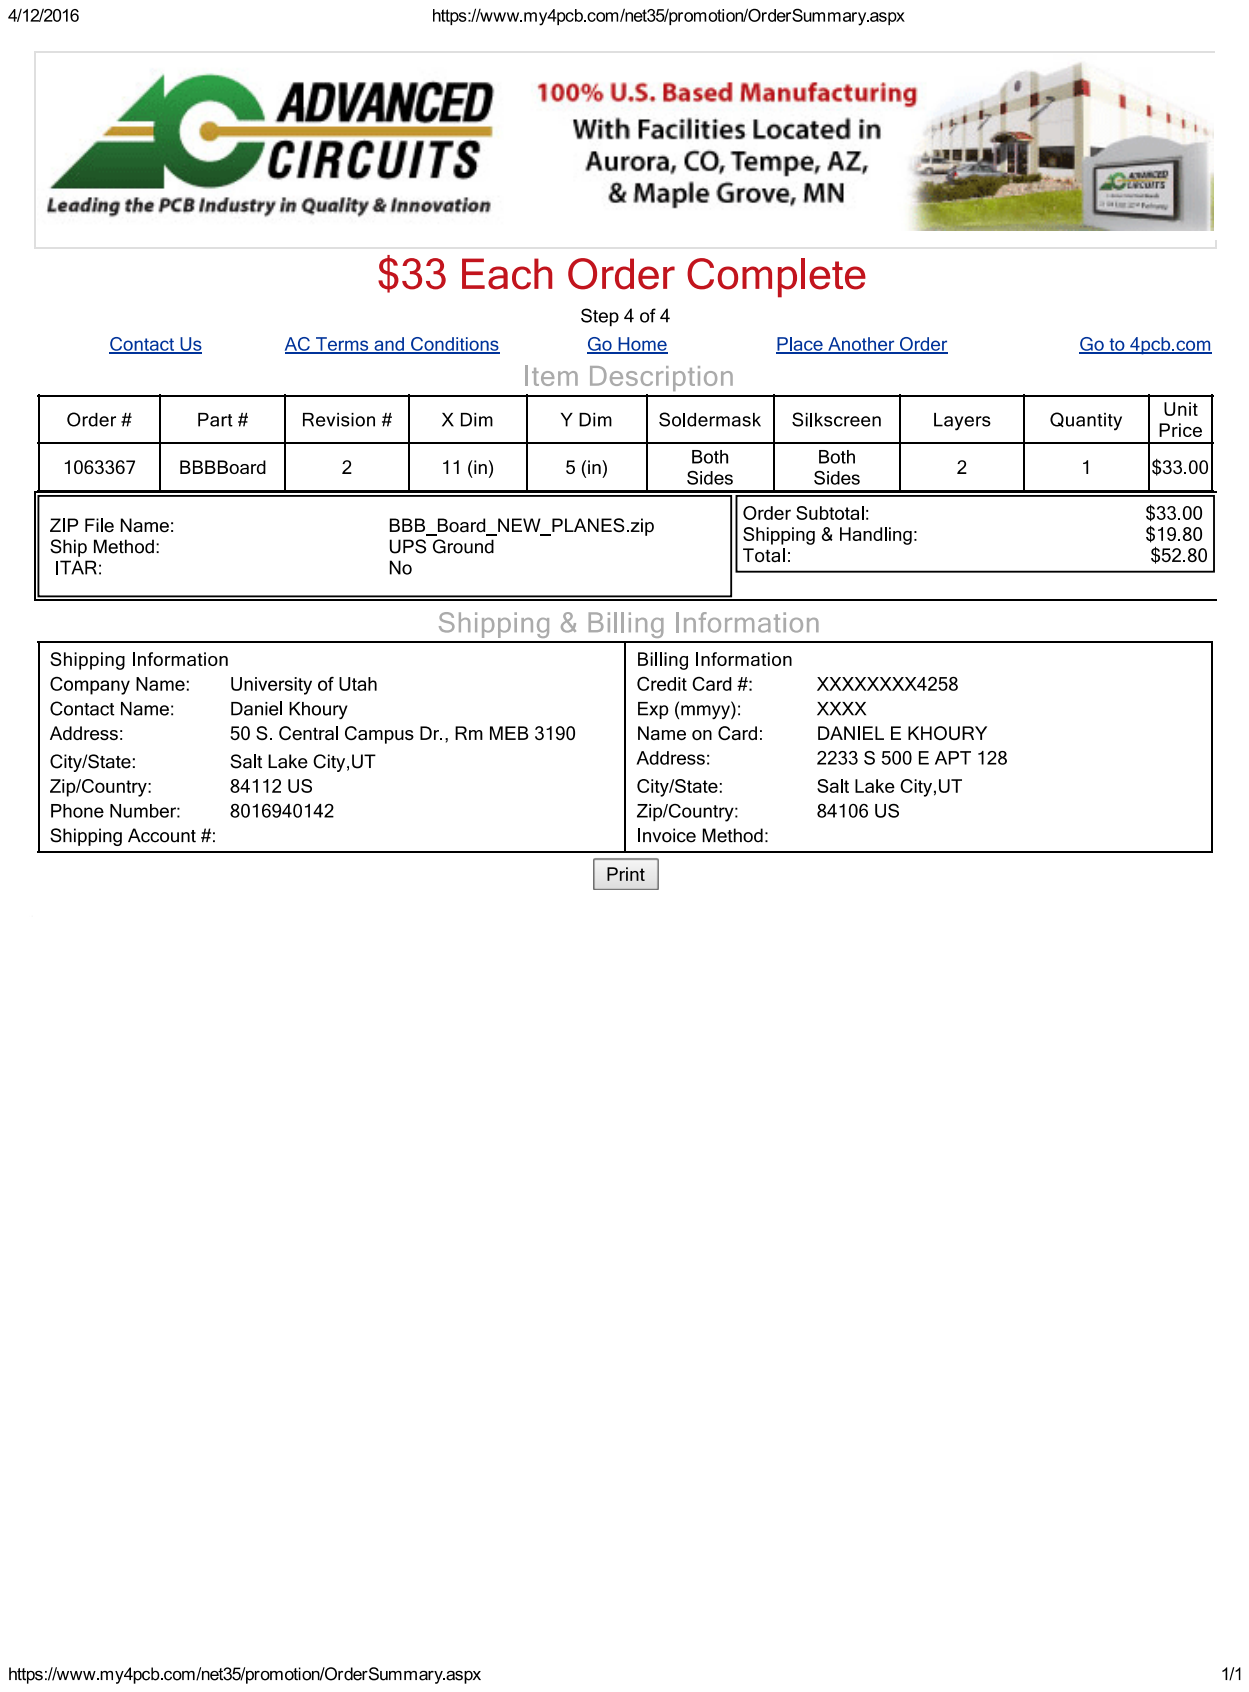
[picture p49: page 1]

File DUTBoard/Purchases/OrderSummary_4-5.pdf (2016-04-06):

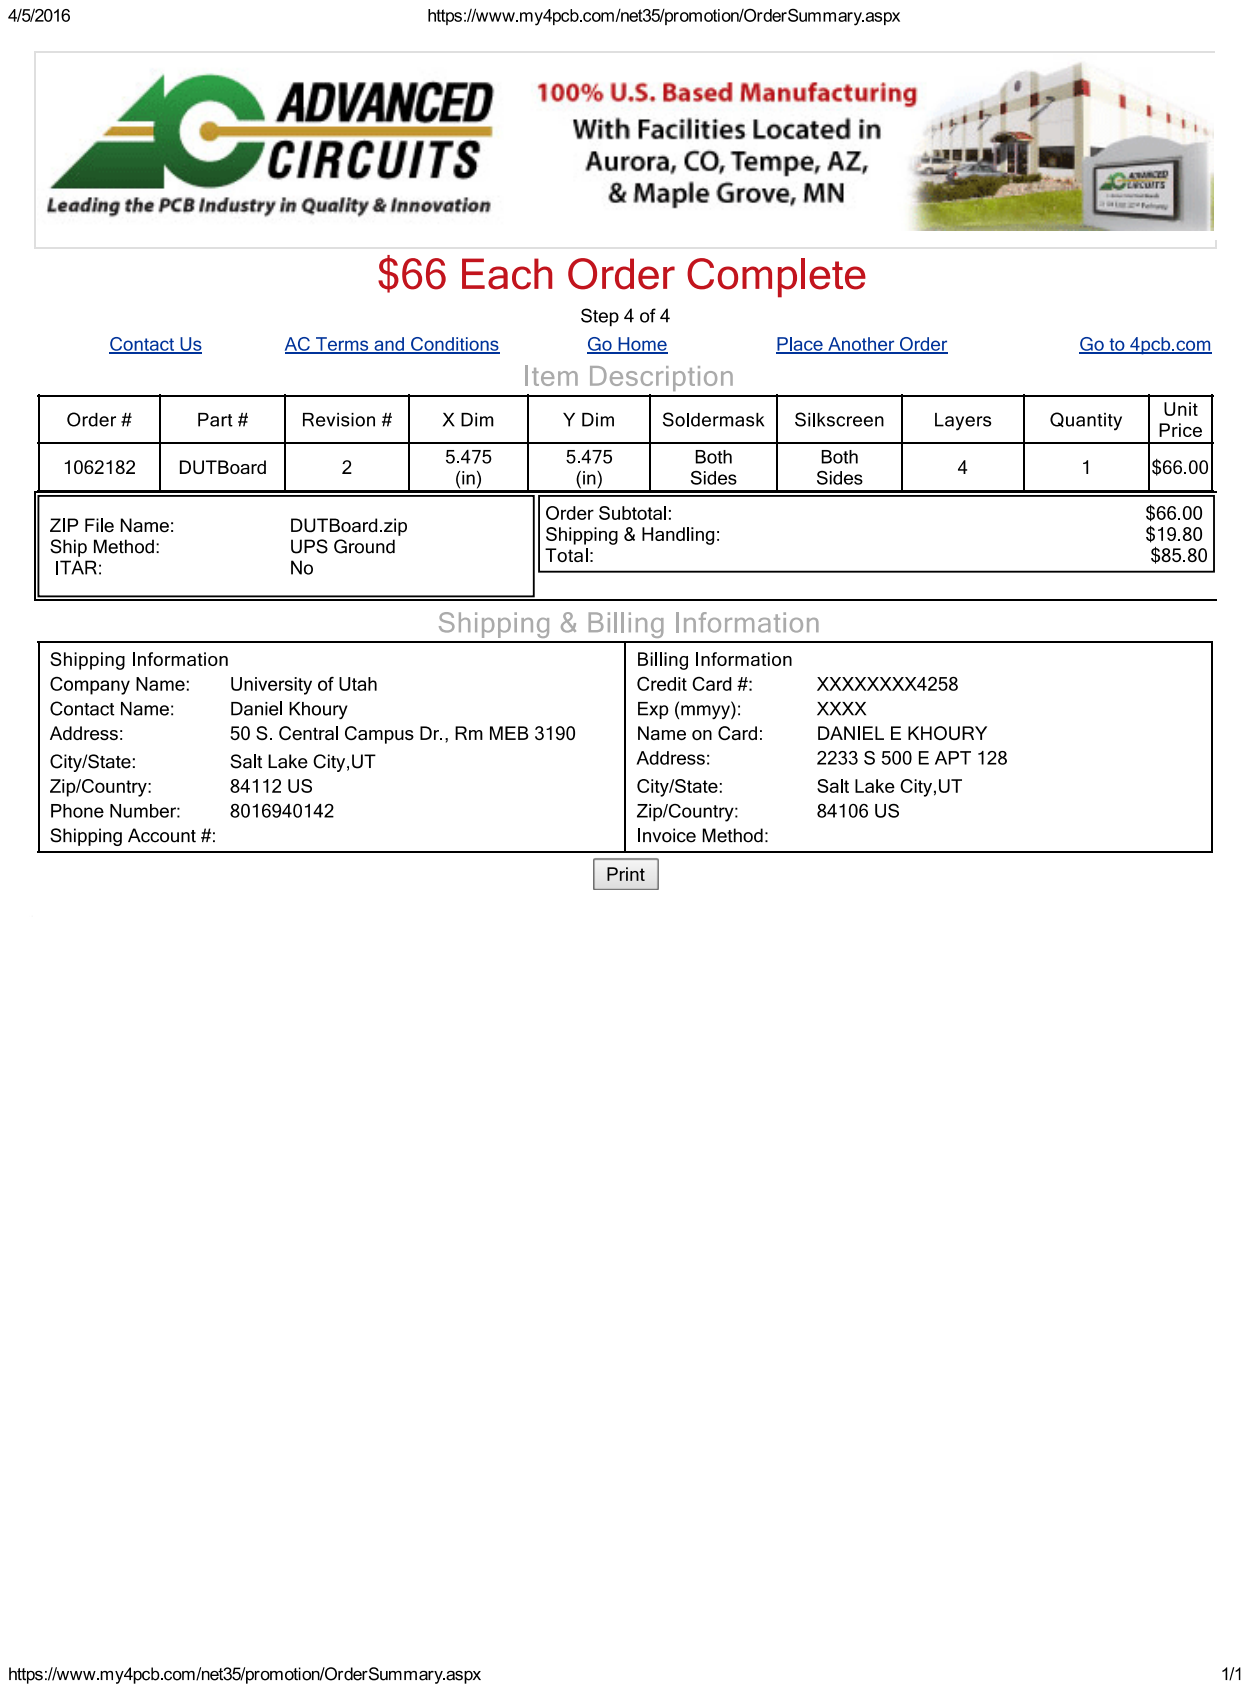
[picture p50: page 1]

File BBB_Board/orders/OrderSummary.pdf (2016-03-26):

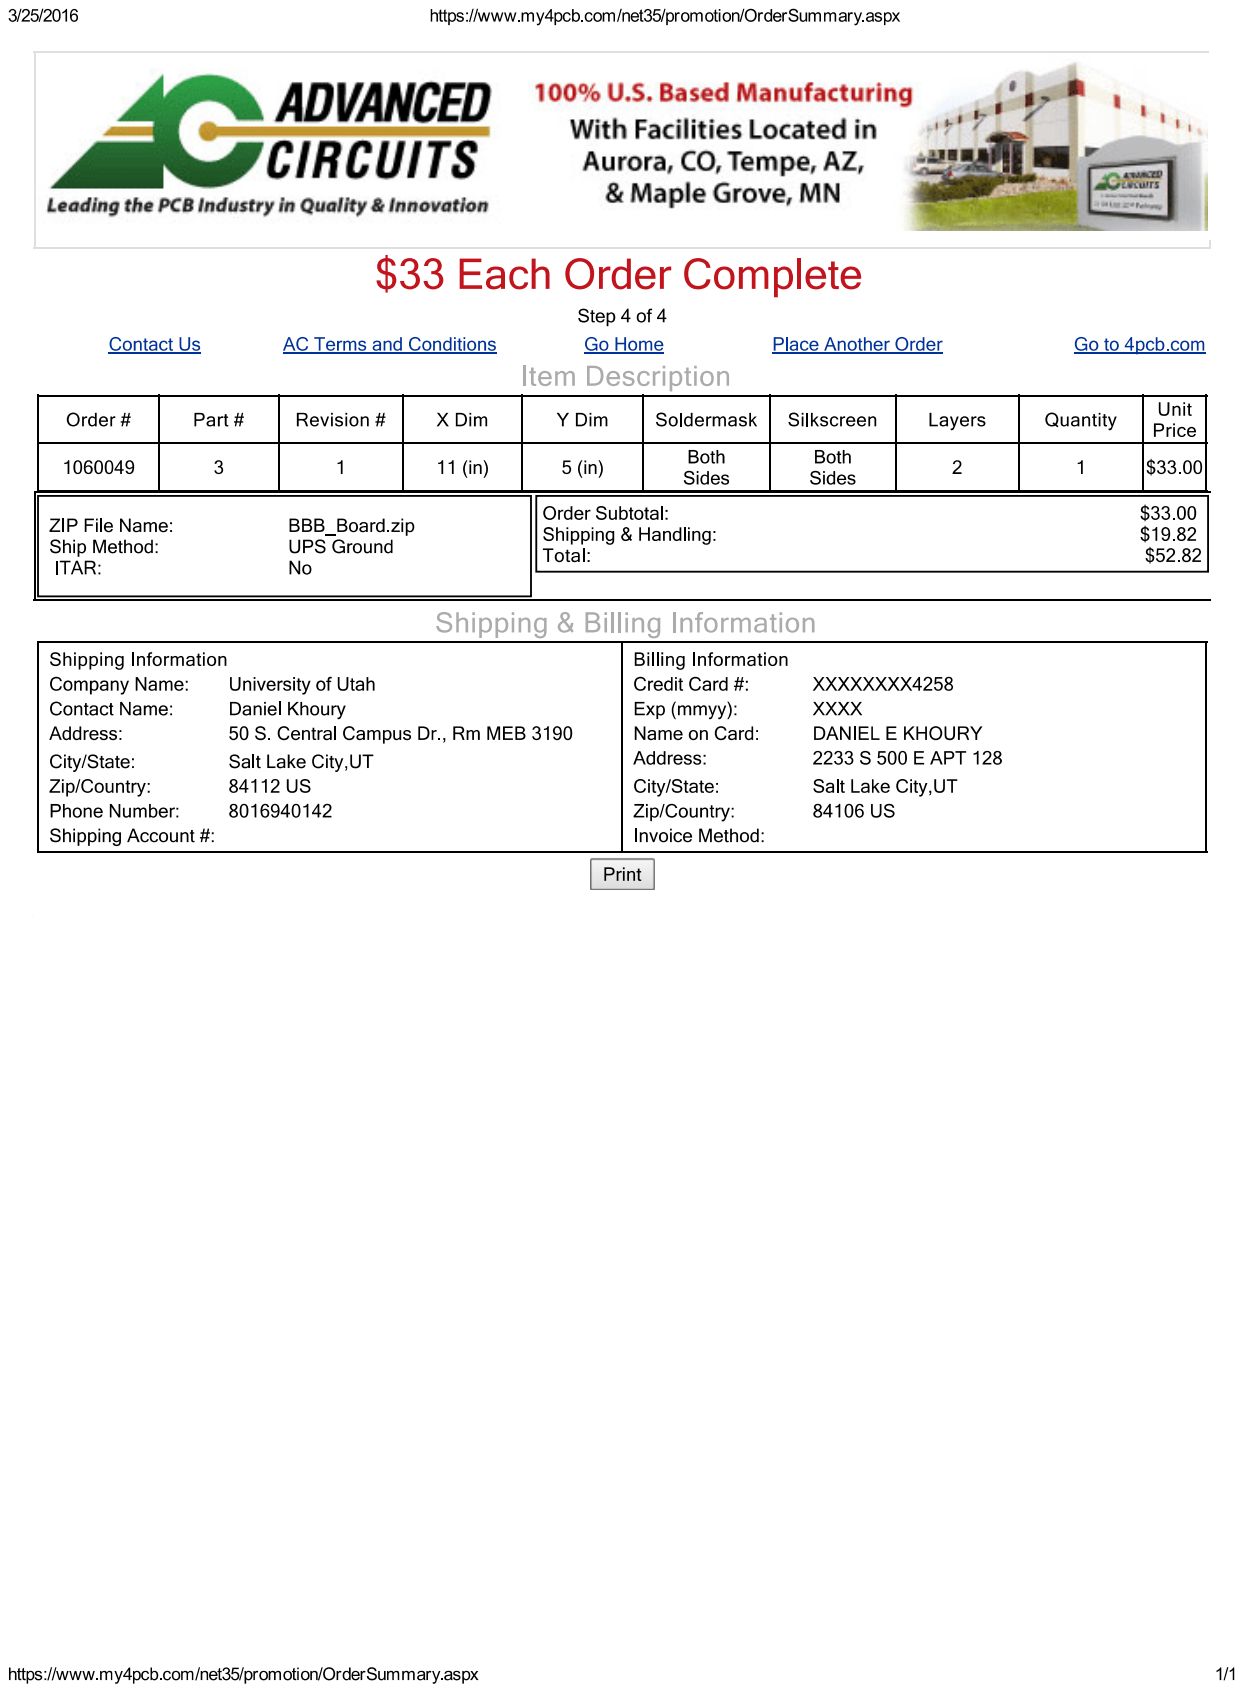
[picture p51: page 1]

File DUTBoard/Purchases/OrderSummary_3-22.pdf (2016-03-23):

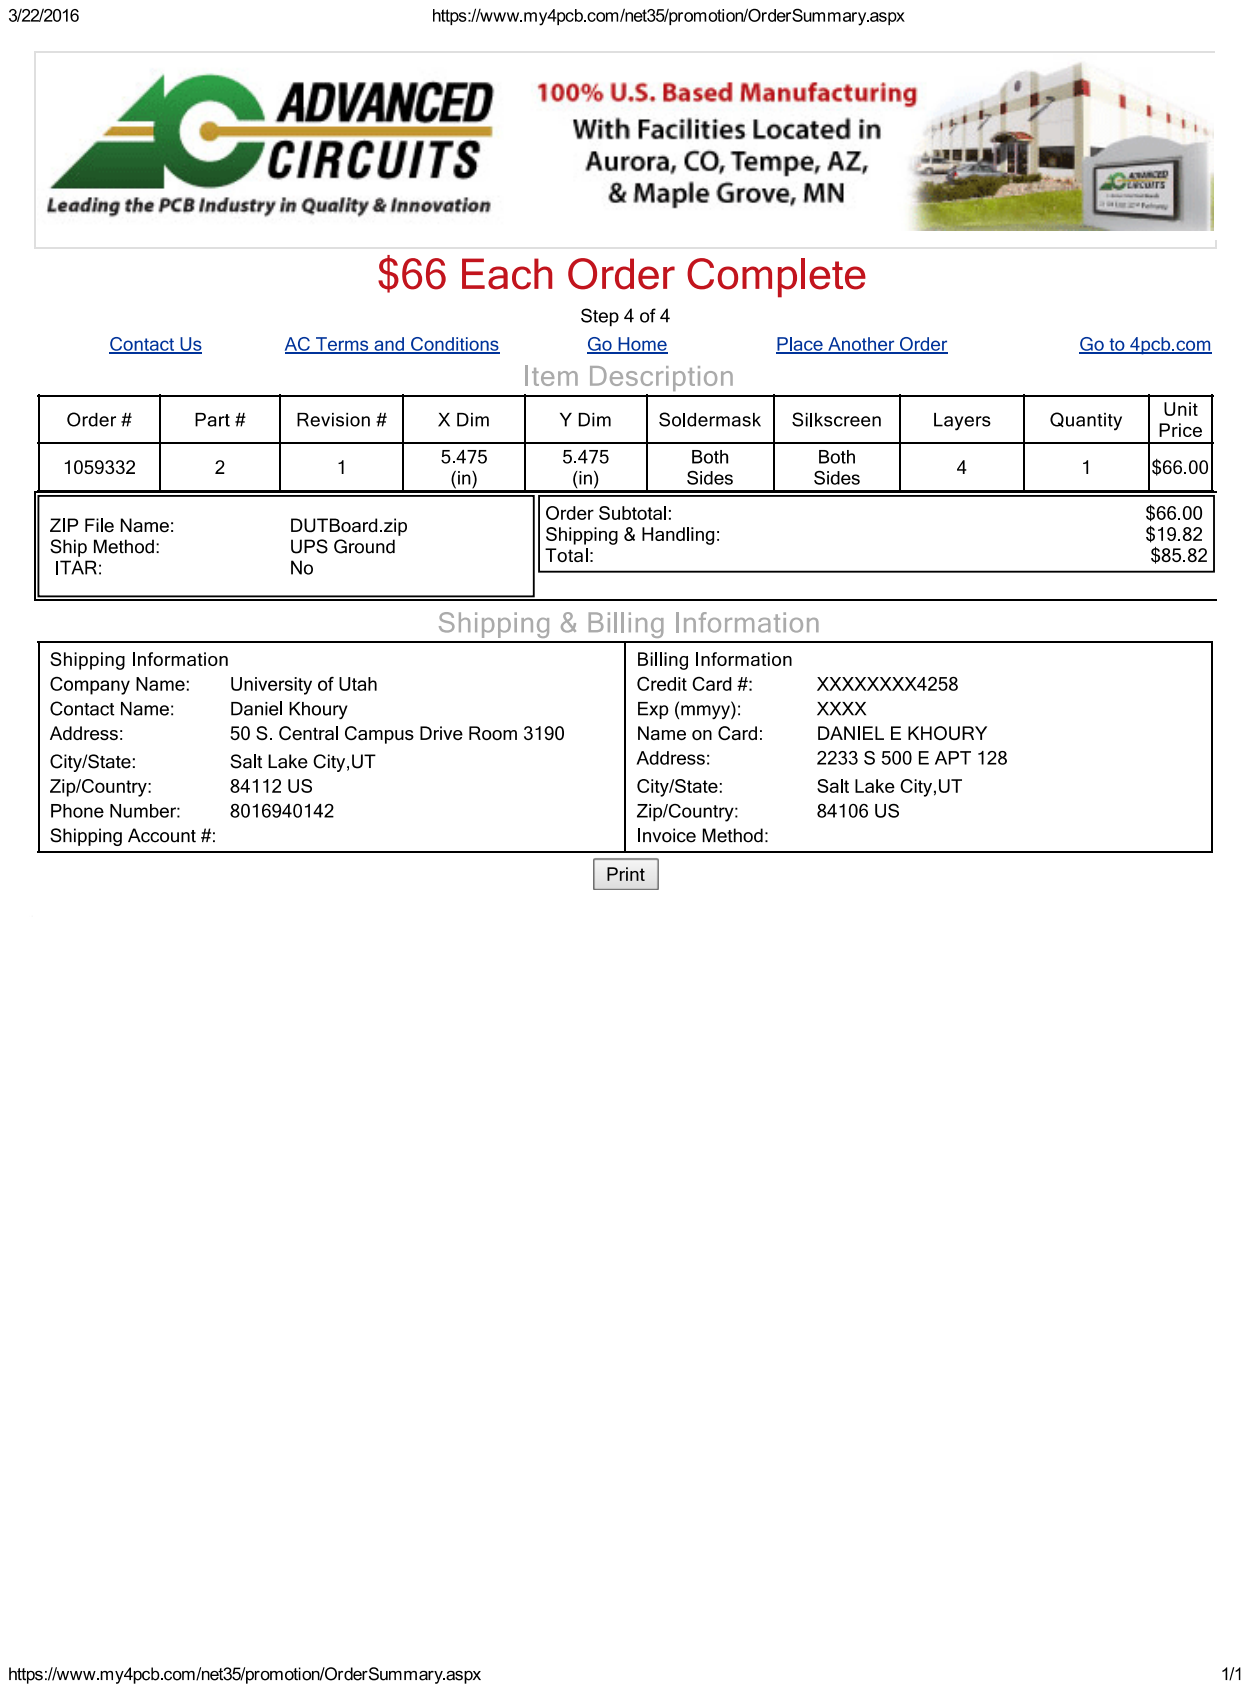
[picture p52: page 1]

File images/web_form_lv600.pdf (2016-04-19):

# Web Form

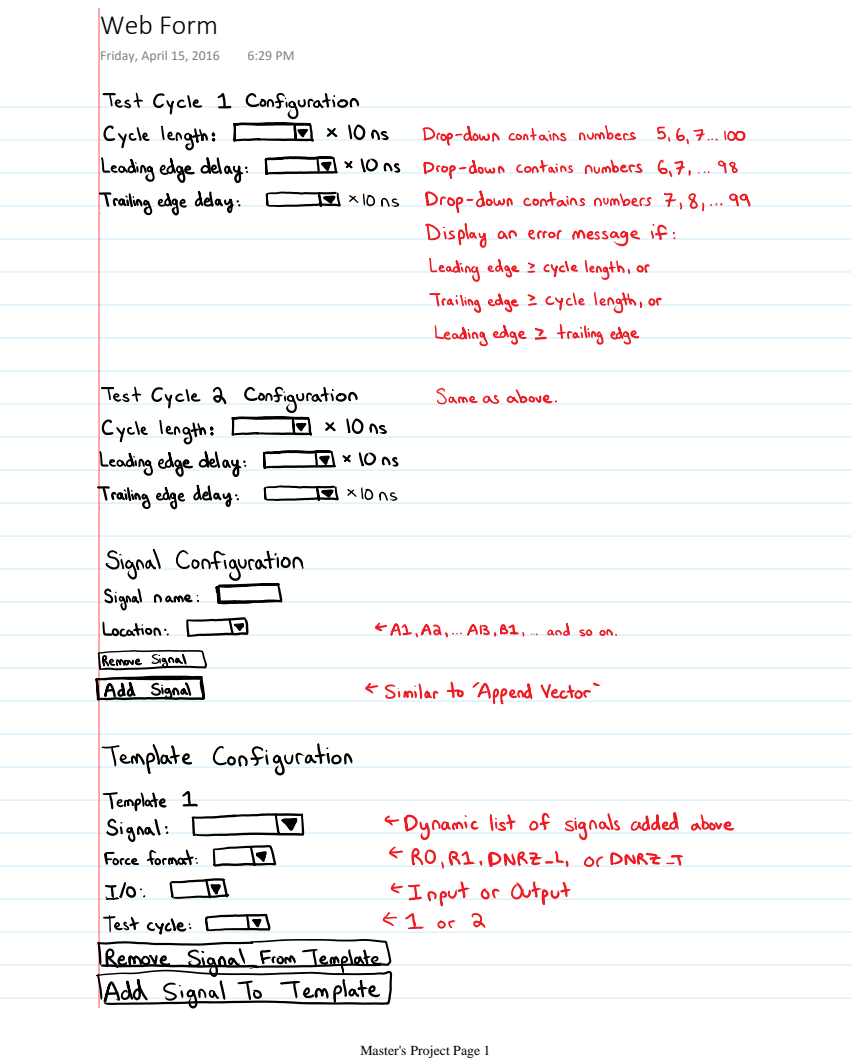
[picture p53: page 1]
Friday, April 15, 2016

Master's Project Page 1

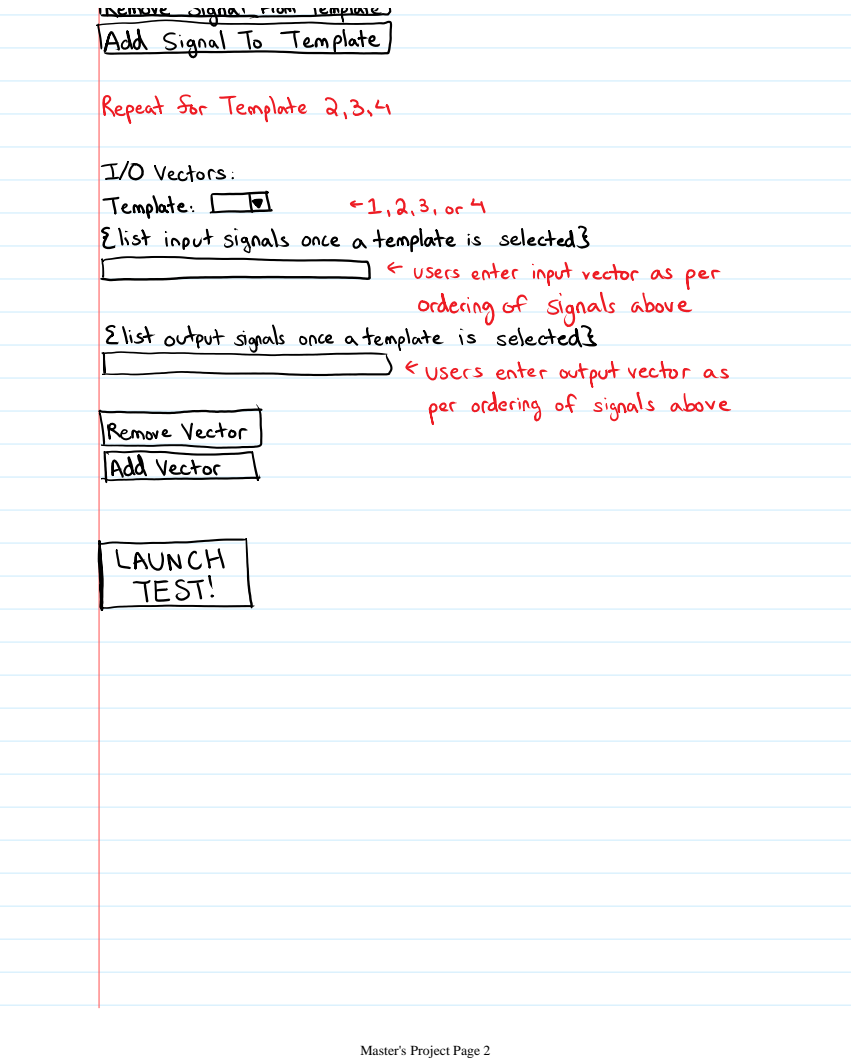
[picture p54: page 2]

Master's Project Page 2

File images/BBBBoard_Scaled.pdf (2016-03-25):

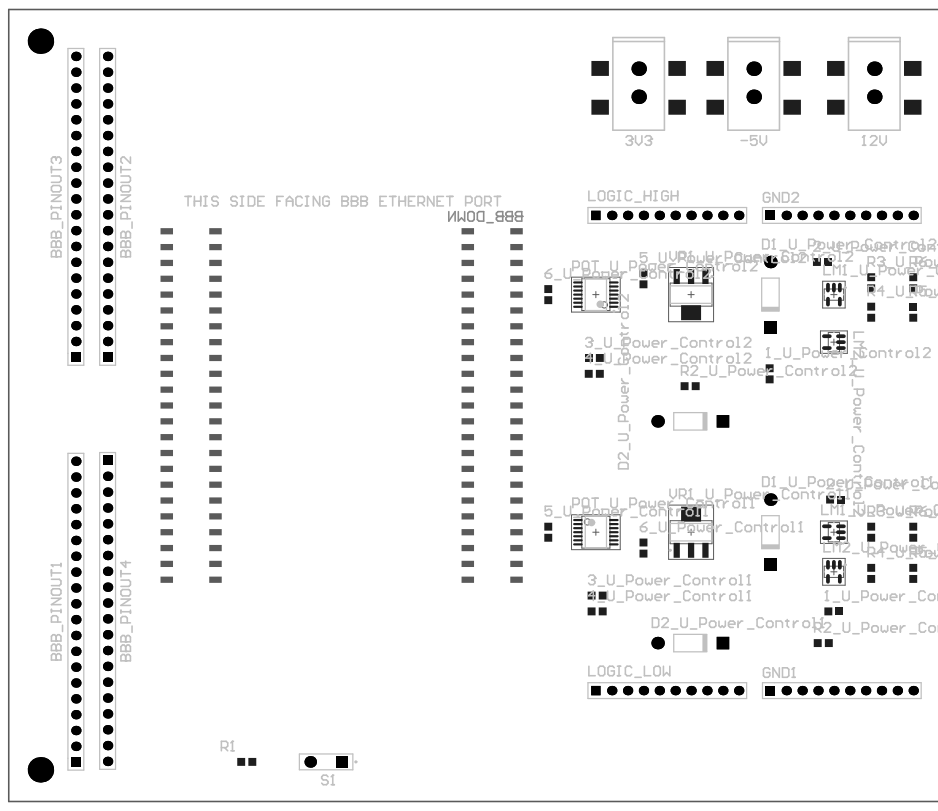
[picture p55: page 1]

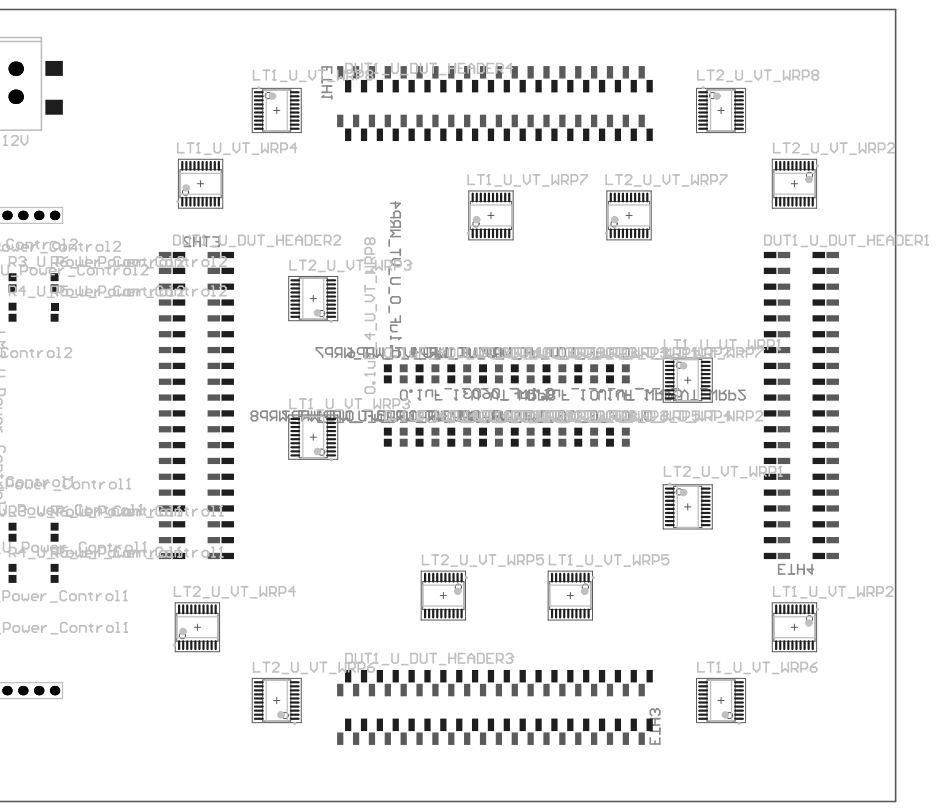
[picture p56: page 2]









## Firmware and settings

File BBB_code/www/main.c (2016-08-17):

#include <assert.h>
#include <stdint.h>
#include <stdio.h>
#include "spi_lib.h"
#include "uart_lib.h"

// Locations range between columns A through N, rows 1 through 13.  
// Includes null character.
#define LOCATION_SIZE ((3 + 1) * sizeof(char))
#define BIT_SIZE ((1 + 1) * sizeof(char))
#define ZIF_ROWS 13
#define ZIF_COLS 13

// ZIF mapping.
// Row mapping (index to row): 0->A, 1->B, ... 12->N
// Column mapping (index to col): 0->1, 1->2, ... 12->13
int ZIF[ZIF_ROWS][ZIF_COLS] = {17, 18, 19, 20, 21, 22, 1, 2, 3, 4, 5, 6, 169, 
                               23, 24, 25, 26, 27, 28, 7, 8, 9, 10, 11, 12, 168, 
                               80, 75, 29, 30, 31, 32, 13, 14, 15, 16, 55, 60, 167, 
                               79, 74, 70, 129, 128, 96, 50, 49, 127, 51, 56, 61, 166, 
                               78, 73, 69, 135, 134, 133, 132, 131, 130, 52, 57, 62, 165, 
                               77, 72, 68, 66, 140, 139, 138, 137, 136, 53, 58, 63, 164, 
                               76, 71, 67, 65, 145, 144, 143, 142, 141, 54, 59, 64, 163, 
                               84, 88, 91, 93, 150, 149, 148, 147, 146, 41, 37, 33, 162, 
                               83, 87, 90, 156, 155, 154, 153, 152, 151, 42, 38, 34, 161, 
                               82, 86, 89, 92, 94, 95, 48, 47, 45, 43, 39, 35, 160, 
                               81, 85, 112, 111, 110, 109, 126, 125, 46, 44, 40, 36, 159, 
                               108, 107, 106, 105, 104, 103, 124, 123, 122, 121, 120, 119, 158, 
                               102, 101, 100, 99, 98, 97, 118, 117, 116, 115, 114, 113, 157};

/*
 * Removes all instances of character c from a string str.
 */
void remove_char(char *str, char c) {
  char *src, *dst;

  for (src = dst = str; *src != '\0'; src++) {
    *dst = *src;
    if (*dst != c) { 
      dst++;
    }
  }
  
  *dst = '\0';
}

/*
 * Removes [ and ] from [token1, token2, ...] json-encoded data.
 */
void trim_brackets(char* arr) {
  remove_char(arr, '[');
  remove_char(arr, ']');
}

// Inputs: arr_len, names, locations_in, ffs_in, directions_in, cycles_in.
// Outputs: locations_out, ffs_out, directions_out, cycles_out. 
// Note that this function allocates memory for the output arrays. 
void process_template(int    arr_len, 
		      char*  names, 
		      char*  locations_in, 
		      char*  ffs_in, 
		      char*  directions_in, 
		      char*  cycles_in, 
		      char** locations_out, 
		      char** ffs_out, 
		      char** directions_out, 
		      char** cycles_out) {

  // Inputs arrive as "[token1, token2, ...]"
  const char s[2] = ",";
  char *token;
  int index;

  // Remove brackets from strings.
  trim_brackets(names);
  trim_brackets(locations_in);
  trim_brackets(ffs_in);
  trim_brackets(directions_in);
  trim_brackets(cycles_in);

  // If no data, just set all output buffers to NULL.
  if (arr_len == 0) {
    locations_out = NULL;
    ffs_out = NULL;
    directions_out = NULL;
    cycles_out = NULL;
    return;
  }

  // Pin locations.
  locations_out = (char**) calloc(arr_len, LOCATION_SIZE);
  assert(locations_out != NULL);

  token = strtok(locations_in, s);

  index = 0;
  while(token != NULL && strcmp(token, "null") != 0) {
    locations_out[index] = token;
    index += LOCATION_SIZE;

    token = strtok(NULL, s);
  }

  // Force-formats.
  ffs_out = (char**) calloc(arr_len, BIT_SIZE);
  assert(ffs_out != NULL);

  token = strtok(ffs_in, s);

  index = 0;
  while(token != NULL && strcmp(token, "null") != 0) {
    ffs_out[index] = token;
    index += BIT_SIZE;

    token = strtok(NULL, s);
  }

  // Pin directions.
  directions_out = (char**) calloc(arr_len, BIT_SIZE);
  assert(directions_out != NULL);

  token = strtok(directions_in, s);

  index = 0;
  while(token != NULL && strcmp(token, "null") != 0) {
    ffs_out[index] = token;
    index += BIT_SIZE;

    token = strtok(NULL, s);
  }

  // Test cycles.
  cycles_out = (char**) calloc(arr_len, BIT_SIZE);
  assert(cycles_out != NULL);

  token = strtok(cycles_in, s);
  index = 0;
  while(token != NULL && strcmp(token, "null") != 0) {
    cycles_out[index] = token;
    index += BIT_SIZE;

    token = strtok(NULL, s);
  }
}

// Converts the arrays from the web form into 16-byte arrays for UART.
void convert_to_bytes(int len, 
		      char** locations_in,
		      char** ffs_in, 
		      char** directions_in, 
		      char** cycles_in,
		      char** ffs_out, 
		      char** directions_out, 
		      char** cycles_out
		      )
{
  // Notes: 
  // 1) locations_in will look like [A1, B1, ...], depending on the user input. 
  //    That is a C array, not a json-encoded array.
  //    Likewise for the other types of input arrays, e.g. ffs_in.
  // 2) If you look at the Verilog (see UART_CTRL.v), you can get a sense of the 
  //    BBB-FPGA communication protocol. Also have a look at uart_lib.h, which 
  //    abstracts the protocol. 
  // 3) Basically, you will want to create an array of 16 bytes (I am using char, 
  //    uint8_t would have been a better choice but oh well) like follows: 
  //    [{template bit 1} {template bit 0} {data for ZIF pin 125} {data for ZIF pin 125} ... {data for ZIF pin 0}]
  //    Once you set up the appropriate array, call the appropriate method in uart_lib.h.
  // 4) NOTE: Notice that there is no locations_out array. The locations_in array is used for indexing into the ffs, directions, 
  //          and cycles arrays. Example: In the ZIF table near the top of this file, 
  //          A1 maps to index 16 (17 - 1, since the table above is one-indexed).
  // 
  // Say the web form input is as follows (if I'm testing the inverter on the MOSIS demo chip): 
  // * One template (01), consisting of two pins: (C1, input) and (D2, output). Leading edge 2 is used for C1.
  // * One test vector, using template 01, assigns 1 to C1 with force-format DNRZ_L and expects D2 = 0. 
  // 
  // First, the output vector needs to be stored somewhere. I don't think the web form (results.php) takes care of that yet, so 
  // be sure to handle that at some point.
  // Next, notice that using the table near the top of this file, C1 maps to index 19 - 1 = 18 and D2 maps to index 24 - 1 = 23.
  // So, we create arrays as follows: 
  // ffs_out: [All zeroes, but index 18 is set to 1, not 0, since that corresponds to DNRZ_L.]
  // directions_out: [All ones (NOT zeroes), but index 18 is set to 0 since that index maps to an input pin.]
  // cycles_out: [All zeroes, but index 18 is set to 1 since that index maps to leading edge 2 associated with pin C1.]
  //
  // Let me know if you have any questions.

  // TODO  
}

int main(int argc, char *argv[])
{
  int len;

  // Signal names.
  // NOTE: For now, these are not used. 
  // In the future, they should be used to help users understand their test results.
  //char **t1_sig_names;
  //char **t2_sig_names;
  //char **t3_sig_names;
  //char **t4_sig_names;

  // Signal locations.
  char** t1_sig_locs = NULL;
  char** t2_sig_locs = NULL;
  char** t3_sig_locs = NULL;
  char** t4_sig_locs = NULL;

  // Force formats.
  char** t1_ffs = NULL;
  char** t2_ffs = NULL;
  char** t3_ffs = NULL;
  char** t4_ffs = NULL;

  // Pin directions.
  char** t1_dirs = NULL;
  char** t2_dirs = NULL;
  char** t3_dirs = NULL;
  char** t4_dirs = NULL;

  // Test cycles (for each pin).
  char** t1_cycles = NULL;
  char** t2_cycles = NULL;
  char** t3_cycles = NULL;
  char** t4_cycles = NULL;

  // Template 1.
  len = atoi(argv[1]);
  process_template(len, 
		   argv[2],
		   argv[3],
		   argv[4],
		   argv[5],
		   argv[6],
		   t1_sig_locs,
		   t1_ffs,
		   t1_dirs,
		   t1_cycles);

  // Template 2.
  len = atoi(argv[7]);
  process_template(len, 
		   argv[8],
		   argv[9],
		   argv[10],
		   argv[11],
		   argv[12],
		   t2_sig_locs,
		   t2_ffs,
		   t2_dirs,
		   t2_cycles);

  // Template 3.
  len = atoi(argv[13]);
  process_template(len, 
		   argv[14],
		   argv[15],
		   argv[16],
		   argv[17],
		   argv[18],
		   t3_sig_locs,
		   t3_ffs,
		   t3_dirs,
		   t3_cycles);

  // Template 4.
  len = atoi(argv[19]);
  process_template(len, 
		   argv[20],
		   argv[21],
		   argv[22],
		   argv[23],
		   argv[24],
		   t4_sig_locs,
		   t4_ffs,
		   t4_dirs,
		   t4_cycles);

  // Convert each bit-vector (ffs, dirs, cycles) into 16 bytes, then use appropriate
  // uart_lib.h command.
  // TODO

  // Then, accumulate input vectors and transfer them to FPGA.
  // TODO

  // Finally, execute tests.
  // TODO

  // Request as many output vectors as input vectors, then make comparisons.

  return 0;
}

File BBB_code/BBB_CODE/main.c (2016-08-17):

#include "spi_lib.h"
#include "uart_lib.h"

// Right now, let's just test the SPI driver...
int main(int argc, char* argv) {
  device d_10 = device1_0;
  device d_20 = device2_0;
  int databits = 0;
  
  int ret = initialize_spi_drivers();
  if (ret == 0) {
    printf("Something went wrong when initializing SPI drivers.\n");
  }

  print_rx_buf(d_20);
    
  ret = ready_command(d_20, RESET_TO_MIDSCALE, 0);
  if (ret == 0) {
    printf("Something went wrong when readying a command.\n");
  }

  print_rx_buf(d_20);

  ret = transfer_and_receive(d_20);
  if (ret == 0) {
    printf("Something went wrong when transferring/receiving.\n");
  }

  print_rx_buf(d_20);

  ret = ready_command(d_20, READ_CONTROL_REG, 0);
  if (ret == 0) {
    printf("Something went wrong when readying a command.\n");
  }

  ret = transfer_and_receive(d_20);
  if (ret == 0) {
    printf("Something went wrong when transferring/receiving.\n");
  }

  print_rx_buf(d_20);

  ret = ready_command(d_20, ENABLE_WRITE, 0);
  if (ret == 0) {
    printf("Something went wrong when readying a command.\n");
  }

  ret = transfer_and_receive(d_20);
  if (ret == 0) {
    printf("Something went wrong when transferring/receiving.\n");
  }

  ret = ready_command(d_20, READ_CONTROL_REG, 0);
  if (ret == 0) {
    printf("Something went wrong when readying a command.\n");
  }

  ret = transfer_and_receive(d_20);
  if (ret == 0) {
    printf("Something went wrong when transferring/receiving.\n");
  }

  print_rx_buf(d_20);

  ret = ready_command(d_20, WRITE_WIPER_POS, 0xFF);
  if (ret == 0) {
    printf("Something went wrong when readying a command.\n");
  }

  ret = transfer_and_receive(d_20);
  if (ret == 0) {
    printf("Something went wrong when transferring/receiving.\n");
  }

  ret = ready_command(d_20, READ_CONTROL_REG, 0);
  if (ret == 0) {
    printf("Something went wrong when readying a command.\n");
  }

  ret = transfer_and_receive(d_20);
  if (ret == 0) {
    printf("Something went wrong when transferring/receiving.\n");
  }

  print_rx_buf(d_20);

  ret = ready_command(d_20, READ_WIPER_POS, 0);
  if (ret == 0) {
    printf("Something went wrong when readying a command.\n");
  }

  ret = transfer_and_receive(d_20);
  if (ret == 0) {
    printf("Something went wrong when transferring/receiving.\n");
  }

  ret = ready_command(d_20, READ_CONTROL_REG, 0);
  if (ret == 0) {
    printf("Something went wrong when readying a command.\n");
  }

  ret = transfer_and_receive(d_20);
  if (ret == 0) {
    printf("Something went wrong when transferring/receiving.\n");
  }

  print_rx_buf(d_20);

  ret = ready_command(d_20, WRITE_WIPER_POS, 0xFE);
  if (ret == 0) {
    printf("Something went wrong when readying a command.\n");
  }

  ret = transfer_and_receive(d_20);
  if (ret == 0) {
    printf("Something went wrong when transferring/receiving.\n");
  }

  print_rx_buf(d_20);

  ret = ready_command(d_20, SHUTDOWN_DEVICE, 0);
  if (ret == 0) {
    printf("Something went wrong when readying a command.\n");
  }

  ret = transfer_and_receive(d_20);
  if (ret == 0) {
    printf("Something went wrong when transferring/receiving.\n");
  }

  print_rx_buf(d_20);

  ret = ready_command(d_20, READ_CONTROL_REG, 0);
  if (ret == 0) {
    printf("Something went wrong when readying a command.\n");
  }

  ret = transfer_and_receive(d_20);
  if (ret == 0) {
    printf("Something went wrong when transferring/receiving.\n");
  }

  print_rx_buf(d_20);

  /*
  ret = ready_command(d_20, RESET_TO_MIDSCALE, 0);
  if (ret == 0) {
    printf("Something went wrong when readying a command.\n");
  }

  ret = transfer_and_receive(d_20);
  if (ret == 0) {
    printf("Something went wrong when transferring/receiving.\n");
  }
  */

  // Done with GPIO pins.
  unexport_gpio_pins();
}

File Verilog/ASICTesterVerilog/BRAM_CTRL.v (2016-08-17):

`timescale 1ns / 1ps

/*
 * Module:                BRAM_CTRL
 * Function:              A wrapper around the BRAM. 
 * 			              Reads/writes an input vector (126 bits) and the corresponding 
 *                        template (2 bits). 
 * 			              Two clock cycles are needed to complete a read or write request.
 * 			 
 * Inputs: 
 * 	CLK
 * 	RST
 *	   INPUT_WRITE:        128-bit write {2 template bits, 126 input vector bits} 		
 * 	TEMPLATE_WRITE: 	  128-bit write {2 template bits, 126 template-config bits}	
 * 	FF_WRITE: 		 	  128-bit write {2 template bits, 63 sets of 2-bit FF configs}
 *    TC_WRITE:           128-bit write {2 template bits, 126 cycle-config bits}
 * 	WRITE_DATA_0: 		  128-bit write input.
 * 	WRITE_DATA_1: 		  128-bit write input (for FF_WRITE only).
 * 	
 * Outputs: 
 * 	READ_DATA_0: 		  128-bit read output.
 * 	READ_DATA_1: 		  128-bit read output (for FF_READ only).
 * 	TEMPLATE_READ:      128-bit read {2 template bits, 126 template-config bits}
 * 	TEMPLATE_BITS:      When performing a TEMPLATE_READ or FF_READ, two template bits 
 * 						     must be provided naturally.
 *    INPUT_READ:         128-bit read {2 template bits, 126 input vector bits}
 *    FF_READ:            128-bit read {2 template bits, 64 sets of 2-bit FF configs}
 *    TC_READ:            128-bit read {2 template bits, 126 cycle-config bits}
 *    TEMPLATE_CHANGE: 	  Indicates if the read template is different from the last read template.
 *    READY: 		        Read/write operation is not in progress.
 *    MORE_TO_READ:       Always 1 unless this controller has finished reading the last input vector.
 *                        Reading again will cause the first input vector to be read.
 * 
 */
module BRAM_CTRL(CLK, RST, RESET_READ_COUNTER,
					  INPUT_WRITE, TEMPLATE_WRITE, FF_WRITE, TC_WRITE,
					  WRITE_DATA,
					  TEMPLATE_READ, TEMPLATE_BITS, INPUT_READ, FF_READ, TC_READ,
					  READ_DATA,
					  TEMPLATE_CHANGE, READY,
					  MORE_TO_READ);					  
					  
	`include "BRAM_CTRL_PARAMS.v"
	
	input CLK;
	input RST;
	input RESET_READ_COUNTER;
	
	input INPUT_WRITE;
	input TEMPLATE_WRITE;
	input FF_WRITE;
	input TC_WRITE;
	input [127:0] WRITE_DATA;
	
	input TEMPLATE_READ;
	input [1:0] TEMPLATE_BITS;
	input INPUT_READ;
	input FF_READ;
	input TC_READ;
	
	output reg [127:0] READ_DATA;
	output reg TEMPLATE_CHANGE;
	output READY;
	output MORE_TO_READ;
	
	assign READY = (PS == IDLE);
	assign MORE_TO_READ = (input_vectors_written != input_vectors_read);
	
	wire write_en = PS == INPUT_WRITE_1 || PS == INPUT_WRITE_2 || 
						 PS == TEMPLATE_WRITE_1 || PS == TEMPLATE_WRITE_2 || 
						 PS == FF_WRITE_1 || PS == FF_WRITE_2 || 
						 PS == TC_WRITE_1 || PS == TC_WRITE_2;

	reg [63:0] din;
	wire [63:0] dout;

	reg [12:0] addr_a;
	reg [12:0] addr_b;
	
	reg [2:0] prev_temp;
	reg [1:0] curr_temp;
	
	reg [6:0] input_write_posA;
	reg [6:0] input_read_posA;
	reg [6:0] input_write_posB;
	reg [6:0] input_read_posB;
	
	// Right now, only 240 input vectors are allowed.
	reg [7:0] input_vectors_written;
	reg [7:0] input_vectors_read;
	
	BRAM bram0(.CLK(CLK), .EN_A(1'b1), .EN_B(1'b1), .WE_A(write_en), .WE_B(write_en), 
				  .DIN_A(din[31:0]), .DIN_B(din[63:32]), .ADDR_A(addr_a), .ADDR_B(addr_b), 
				  .DOUT_A(dout[31:0]), .DOUT_B(dout[63:32]));
				  
	reg [4:0] PS;
	reg [4:0] NS;
	
	// Present-state logic.
	always@(posedge CLK) begin
		if (RST) begin
			PS <= IDLE;
		end
		else begin
			PS <= NS;
		end
	end
	
	// Next-state logic.
	always@(*) begin
		case (PS)
			IDLE: begin
				if (INPUT_WRITE) begin
					NS = INPUT_WRITE_1;
				end
				else if (TEMPLATE_WRITE) begin
					NS = TEMPLATE_WRITE_1;
				end
				else if (FF_WRITE) begin
					NS = FF_WRITE_1;
				end
				else if (TC_WRITE) begin
					NS = TC_WRITE_1;
				end
				else if (INPUT_READ) begin
					NS = INPUT_READ_0;
				end
				else if (TEMPLATE_READ) begin
					NS = TEMPLATE_READ_0;
				end
				else if (FF_READ) begin
					NS = FF_READ_0;
				end
				else if (TC_READ) begin
					NS = TC_READ_0;
				end
				else begin
					NS = IDLE;
				end
			end
			
			INPUT_WRITE_1: begin
				NS = INPUT_WRITE_2;
			end
			
			INPUT_WRITE_2: begin
				NS = IDLE;
			end
			
			TEMPLATE_WRITE_1: begin
				NS = TEMPLATE_WRITE_2;
			end
			
			TEMPLATE_WRITE_2: begin
				NS = IDLE;
			end
			
			FF_WRITE_1: begin
				NS = FF_WRITE_2;
			end
			
			FF_WRITE_2: begin
				NS = IDLE;
			end
			
			TC_WRITE_1: begin
				NS = TC_WRITE_2; 
			end
			
			TC_WRITE_2: begin
				NS = IDLE;
			end
			
			INPUT_READ_0: begin
				NS = INPUT_READ_1;
			end
			
			INPUT_READ_1: begin
				NS = INPUT_READ_2;
			end
			
			INPUT_READ_2: begin
				NS = CHECK_TEMPLATE;
			end
			
			TEMPLATE_READ_0: begin
				NS = TEMPLATE_READ_1;
			end
			
			TEMPLATE_READ_1: begin
				NS = TEMPLATE_READ_2;
			end
			
			TEMPLATE_READ_2: begin
				NS = IDLE;
			end
			
			FF_READ_0: begin
				NS = FF_READ_1;
			end
			
			FF_READ_1: begin
				NS = FF_READ_2;
			end
			
			FF_READ_2: begin
				NS = IDLE;
			end
			
			TC_READ_0: begin
				NS = TC_READ_1;
			end
			
			TC_READ_1: begin
				NS = TC_READ_2;
			end
			
			TC_READ_2: begin
				NS = IDLE;
			end
			
			CHECK_TEMPLATE: begin
				NS = IDLE;
			end
			
			default: begin
				// Should never get here.
				NS = IDLE;
			end
		endcase
	end
	
	// Logic to update number of input vectors read and written.
	always@(posedge CLK) begin
		if (RST) begin
			input_vectors_written <= 8'd0;
			input_vectors_read <= 8'd0;
		end
		else if (RESET_READ_COUNTER) begin
			input_vectors_read <= 8'd0;
		end
		else begin
			if (PS == INPUT_WRITE_2) begin
				input_vectors_written <= input_vectors_written + 8'd1;
			end
			else if (PS == INPUT_READ_1) begin
				// Delay by a clock cycle so we can reset this counter in time.
				// (See below.)
				input_vectors_read <= input_vectors_read + 8'd1;
			end
			
			if (input_vectors_read == input_vectors_written) begin
				 // Saturate the read count.
				input_vectors_read <= input_vectors_read;
			end
		end
	end
	
	// Logic to update read and write addresses for input vectors.
	always@(posedge CLK) begin
		if (RST) begin
			input_write_posA <= INPUT_START_ADDR_A;
			input_write_posB <= INPUT_START_ADDR_B;
			input_read_posA <= INPUT_START_ADDR_A;
			input_read_posB <= INPUT_START_ADDR_B;
		end
		else if (RESET_READ_COUNTER) begin
			input_read_posA <= INPUT_START_ADDR_A;
			input_read_posB <= INPUT_START_ADDR_B;
		end
		else begin
			if (PS == INPUT_WRITE_1 || PS == INPUT_WRITE_2) begin
				input_write_posA <= input_write_posA + INPUT_INCR_FACTOR;
				input_write_posB <= input_write_posB + INPUT_INCR_FACTOR;
			end
			else if (PS == INPUT_READ_0 || PS == INPUT_READ_1) begin
				input_read_posA <= input_read_posA + INPUT_INCR_FACTOR;
				input_read_posB <= input_read_posB + INPUT_INCR_FACTOR;
			end
		end
	end
	
	// Combinational logic.
	always@(*) begin
		din = 64'd0;
		addr_a = 14'd0;
		addr_b = 14'd0;
		case (PS)
			IDLE: begin
				// Do nothing.
			end
			
			INPUT_WRITE_1: begin
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

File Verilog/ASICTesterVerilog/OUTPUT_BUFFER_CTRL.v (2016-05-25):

`timescale 1ns / 1ps

/*
 * Module:               OUTPUT_BUFFER_CTRL 
 * Function:             Controller for parallel-to-serial shift registers (output buffers).
 *                       Datasheet: http://www.nxp.com/documents/data_sheet/74HC_HCT597.pdf
 *
 * Inputs: 
 *    CLK
 *    RST
 * 	CLEAR_BUFFER:      Resets the output buffers.
 *    CAPTURE_SRAM_DATA: When high, this controller latches onto the SRAM data
 *                       and then clocks it in.
 *    Q:                 Serial data from daisy-chained output buffers.
 *    
 * Outputs: 
 *    READY:             When high, the controller has completed the last-requested operation.
 * 							 When low, the controller is in the middle of an operation.
 *	 	SRAM_DATA:         128-bit SRAM data fetched from output buffers.
 *    MR_BAR: 				 Master reset (active-low).
 *    PL_BAR:            Enables parallel load (active-low).
 *    SCHP:              Shift-register clock.
 *    STCP:              Storage (parallel) register clock.
 * 
 * Using this controller: 
 * 1) Raise CAPTURE_SRAM_DATA for one clock cycle to latch and retrieve SRAM data.
 * 2) When READY is high, SRAM_DATA is ready to retrieve. 
 */
module OUTPUT_BUFFER_CTRL(CLK, RST, CLEAR_BUFFER, CAPTURE_SRAM_DATA, 
								  READY, SRAM_DATA, Q, MR_BAR, PL_BAR, SHCP, STCP);
	input CLK;
	input RST;
	output reg READY;
	
	input CLEAR_BUFFER; 
	input CAPTURE_SRAM_DATA; 
	output reg [127:0] SRAM_DATA;
	input Q;
	output reg MR_BAR;
	output reg PL_BAR;
	output reg SHCP;
	output reg STCP;
	
	parameter IDLE = 0;
	parameter RESET_BUFFER = 1;
	parameter LATCH_DATA = 2;
	parameter RETRIEVE_DATA = 3;
	
	// These output buffers are (intentionally) very slow, to ensure that daisy-chaining
	// the buffers does not cause timing issues.
	// The datasheet suggests that at 3.3V, 1000 nanoseconds should be a safe waiting time.
	reg [7:0] serial_counter;
	reg [6:0] propagation_delay_counter;
	
	reg enable_delay_counter;
	reg reset_delay_counter;
	reg enable_serial_counter;
	reg reset_serial_counter;

	parameter MAX_DELAY = 100;
	parameter SERIAL_LIMIT = 128;
	
	reg [1:0] PS;
	reg [1:0] NS;
	
	// Counters used when clocking out data from output buffer and
	// taking the slow propagation speed of the chip into account.
	// Note that a data retrieval operation requires about 50 us.
	always@(posedge CLK) begin
		if (RST) begin
			serial_counter <= 7'd0;
			propagation_delay_counter <= 7'd0;
		end
		else begin
			if (enable_delay_counter) begin
				propagation_delay_counter <= propagation_delay_counter + 7'd1;
			end
			else if (reset_delay_counter) begin
				propagation_delay_counter <= 7'd0; 
			end
			if (enable_serial_counter) begin
				serial_counter <= serial_counter + 7'd1;
			end
			else if (reset_serial_counter) begin
				serial_counter <= 7'd0;
			end
		end
	end
	
	// Present-state logic.
	always@(posedge CLK) begin
		if (RST) begin
			PS <= IDLE;
		end
		else begin
			PS <= NS;
		end
	end
	
	// Next-state logic.
	always@(*) begin
		case (PS)
			IDLE: begin
				if (CLEAR_BUFFER) begin
					NS = RESET_BUFFER;
				end
				else if (CAPTURE_SRAM_DATA) begin
					NS = LATCH_DATA; 
				end
				else begin
					NS = IDLE;
				end
			end
			RESET_BUFFER: begin
				if (propagation_delay_counter == MAX_DELAY) begin
					NS = IDLE;
				end
				else begin
					NS = RESET_BUFFER;
				end
			end
			LATCH_DATA: begin
				if (propagation_delay_counter == MAX_DELAY) begin
					NS = RETRIEVE_DATA;
				end
				else begin
					NS = LATCH_DATA;
				end
			end
			RETRIEVE_DATA: begin
				if (serial_counter == SERIAL_LIMIT) begin
					NS = IDLE;
				end
				else begin
					NS = RETRIEVE_DATA;
				end
			end
			default: begin
				// Should never get here.
				NS = IDLE;
			end
		endcase
	end
	
	reg shcp_internal; // Double-buffered to avoid glitches.
	reg stcp_internal;
	always@(posedge CLK) begin
		if (RST) begin
			SHCP <= 1'b0;
			STCP <= 1'b0;
		end
		else begin
			SHCP <= shcp_internal;
			STCP <= stcp_internal;
		end
	end
	
	// Combinational logic.
	always@(*) begin
		MR_BAR = 1'b1;
		PL_BAR = 1'b1;
		shcp_internal = 1'b0;
		stcp_internal = 1'b0;
		READY = 1'b0;

		enable_serial_counter = 1'b0;
		reset_serial_counter = 1'b0;
		
		enable_delay_counter = 1'b0;
		reset_delay_counter = 1'b0;

		case (PS) 
			IDLE: begin
				READY = 1'b1;
				reset_serial_counter = 1'b1;
				reset_delay_counter = 1'b1;
			end
			
			RESET_BUFFER: begin
				if (propagation_delay_counter < (MAX_DELAY >> 1)) begin
					MR_BAR = 1'b0;
				end
				else begin
					MR_BAR = 1'b1;
				end
			
				if (propagation_delay_counter == MAX_DELAY) begin
					reset_delay_counter = 1'b1;
				end
				else begin
					enable_delay_counter = 1'b1;
				end
			end
			
			LATCH_DATA: begin
				if (propagation_delay_counter < (MAX_DELAY >> 1)) begin
					PL_BAR = 1'b0;
					stcp_internal = 1'b0;
				end
				else begin
					PL_BAR = 1'b0;
					stcp_internal = 1'b1;
				end
			
				if (propagation_delay_counter == MAX_DELAY) begin
					reset_delay_counter = 1'b1;
				end
				else begin
					enable_delay_counter = 1'b1;
				end
			end
			
			RETRIEVE_DATA: begin
				if (propagation_delay_counter == 0) begin
					enable_serial_counter = 1'b1;
				end
				else if (propagation_delay_counter < (MAX_DELAY >> 1)) begin
					shcp_internal = 1'b0;
				end
				else begin
					shcp_internal = 1'b1;
				end
			
				if (propagation_delay_counter == MAX_DELAY) begin
					reset_delay_counter = 1'b1;
				end
				else begin
					enable_delay_counter = 1'b1;
				end
			end
			
			default: begin
				// Should never get here.
			end
		endcase
	end
	
	// Clocks in serial data.
	always@(posedge CLK) begin
		if (RST) begin
			SRAM_DATA <= 127'd0;
		end
		else if (enable_serial_counter) begin
			SRAM_DATA[8'd127 - serial_counter] <= Q;
		end
	end
	
endmodule

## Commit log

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2015-10-14 Adding slightly-fixed clock code.
    [ReconfigurableClockGeneratorTB_isim_beh.exe_main.nt64.obj, ReconfigurableClockGenerator_pad.csv, ReconfigurableClockGenerator_pad.txt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]
2015-11-05 Results of clocking scheme seem promising, but more rigorous testing is needed.
    [CLOCK_GEN_pad.csv]
2015-11-16 Fixed some bugs and adapted the code for Numato Saturn. Things appear to be working OK.
    [CLOCK_GEN_pad.csv]
2015-11-23 Uploading a PSpice design that allows for modulating GND and VDD!
    [ADJUSTABLEVOLTAGEREGULATOR.DSN]
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2016-01-08 Beginning work for Numato shield, with equilibrium tracing.
    [NumatoShield.PcbDoc, NumatoShield.PcbLib, NumatoShield.PrjPcb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]
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2016-01-10 One header is now fully routed, with all traces within 1/5 of an inch of each other. Once another header is done, the rest of the routing will just be symmetry.
    [NumatoShield.PcbDoc]
2016-01-11 Routed half of another header. Once I finish routing this header, the rest is symmetry.
    [NumatoShield.PcbDoc]
2016-01-11 Two full headers are now routed. Two headers remain, both containing ground. Goal is to have Gerber files ready by Friday of this week.
    [NumatoShield.PcbDoc]
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2016-01-14 Redoing routing since the previous footprints were wrong. 20 pins routed (half of a header).
    [NumatoShield.PcbDoc, NumatoShield.PcbLib, NumatoShield.PrjPcb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]
2016-01-14 Almost done with routing all of one header.
    [NumatoShield.SchDoc, NumatoShieldWithVias.PcbDoc]
2016-01-15 One header fully routed. Three left to go! (When two are routed, the rest is still symmetry.)
    [NumatoShieldWithVias.PcbDoc]
2016-01-18 Routed 20 pins of the second header. I will try to route as many pins tomorrow as I can.
    [NumatoShield.SchDoc, NumatoShieldWithVias.PcbDoc]
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2016-01-20 20 more pins routed. 20 more on Wednesday, Thursday, and then Friday.
    [NumatoShield.PrjPcb, NumatoShield.SchDoc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]
2016-01-20 20 more pins routed. There are 10 ground pins that will be easy to route, so really there are just 30 more pins to route. Still on track to finish by Friday.
    [NumatoShieldWithVias.PcbDoc]
2016-01-21 12 more pins routed. Tomorrow, I'll route the last 20 pins and GND. On Friday, I'll add the top/bottom overlays, verify that 4PCB and everything else is correct (pinout, layout and all) and then subm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
    [NumatoShieldWithVias.PcbDoc]
2016-01-21 The Numato headers are 1.55 (not 1.5) inches apart. Fixed.
    [NumatoShieldWithVias.PcbDoc]
2016-01-23 Finally, all pins routed! Ground plane included, all traces within 200 mil tolerance. Will add labels tomorrow.
    [NumatoShieldWithVias.PcbDoc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]
2016-01-24 All done! Sending for fabrication. DRC checked and manually inspected more than once.
    [NumatoShieldWithVias.GBL, NumatoShieldWithVias.GBO, NumatoShieldWithVias.GBP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]
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2016-01-25 Board updated so that the distance between the innermost pins of the Numato headers is 1525.59 millinches. Board sent for fabrication.
    [NumatoShield.PcbDoc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]
2016-01-27 Adding a 44TSOP breakout board Altium project to the repo. Will fabricate locally.
    [44TSOPBreakout.PcbDoc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]
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2016-02-15 Synthesized demo, but SRAM values are glitchy. Need to redo demo to account for careful timing.
    [TOP_pad.csv]
2016-02-16 SRAM/counter demo working. Will upload a video to the website.
    [TOP_pad.csv]
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2016-02-20 Committing updated version of power circuit to include protection circuitry via voltage divider and op-amp buffer.
    [ADJUSTABLEVOLTAGEREGULATOR2.DSN]
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2016-02-20 Committing DUTBoard project. Schematic library almost done (working on output buffer schematic library part).
    [DUTBoard.PrjPcb, DUTBoard.SchDoc, DUTBoard.SchLib]
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2016-02-29 Adding my schematic for the DUT board. It's not entirely complete (for instance, I need to go through the datasheets and see if I need any extra components, like bypass capacitors for the voltage tra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
    [COUNTER_BANK.SchDoc, COUNTER_WRP.SchDoc, DUTBoard.PrjPcb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]
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2016-03-06 Cleaned up the DUT board hierarchy, added bypass capacitors to voltage translators.
    [COUNTER_BANK.SchDoc, COUNTER_WRP.SchDoc, DUTBoard.PrjPcb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]
2016-03-08 Getting rid of history ZIP files. I'm basically done with my schematic -- there are some errors when trying to create the PCB but I can deal with them on Spring Break. For the remainder of this week,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
    [COUNTER_WRP.SchDoc, DUTBoard.PcbLib, DUTBoard.PrjPcb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]
2016-03-11 Schematic appears to be OK, PCB components ready to be routed.
    [COUNTER_BANK.SchDoc, COUNTER_WRP.SchDoc, DUTBoard.PcbLib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]
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2016-03-14 I placed my DUT board components where I want them to be, and I think routing this thing is possible! Note: I need to modify the female headers (both sides) by replacing the ground signals with other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
    [COUNTER_BANK.SchDoc, COUNTER_WRP.SchDoc, DUTBoard.PcbDoc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]
2016-03-15 Updated my schematic and PCB accordingly. I should be ready to route now. Before I route, I need to verify that I have all proper signals and connections.
    [COUNTER_BANK.SchDoc, DUTBoard.PcbDoc, DUTBoard.PcbLib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]
2016-03-16 Updated DUTBoard layout to include voltage translator capacitors. Board is ready to route now.
    [DUTBoard.PcbDoc, DUTBoard.PcbLib, DUTBoard.PrjPcb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]
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2016-03-17 Updated the schematic/layout to include duplicate SRAM pins, removed LOW_POWER pin.
    [DUTBoard.PcbDoc, DUTBoard.PrjPcb, DUTBoard_Sandbox.PcbDoc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]
2016-03-17 I modified some of the schematics (tristate, voltage translator, shift register) so that their port sizes are all 16 bits. This change should make routing much easier. TODO: Need to create connection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
    [BBB_Board.PrjPCB, BBB_Board.SchDoc, DUTBoard.PcbDoc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]
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2016-03-17 Fixed a major bug with the headers in the DUTBoard schematic/layout.
    [BOTTOM_HEADER_WRP.SchDoc, COMBINED_HEADER_WRP.SchDoc, DUTBoard.PcbDoc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]
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2016-03-17 Fixed some routing issues with my board.
    [BBB_Board.SchDoc, DUTBoard.PcbDoc, DUTBoard.PcbLib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]
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2016-03-19 Fixed some bugs in DUTBoard, routed everything but SRAM corners. Routing is sloppy, need to clean later.
    [BOTTOM_HEADER_WRP.SchDoc, COMBINED_HEADER_WRP.SchDoc, DUTBoard.PcbDoc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]
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2016-03-21 DUTBoard routed! I'm still waiting for FreeDFM results but I pass DRC with no errors, using somewhat conservative constraints.
    [BBB_Board.PrjPCB, BOTTOM_HEADER_WRP.SchDoc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]
2016-03-22 Made some fixes to BBB_Board. The NumatoShield has two more grounds than it should have, and I added some connections to the top schematic.
    [BBB_Board.SchDoc, DUTBoard.PrjPcb, DUT_HEADER.SchDoc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]
2016-03-22 fixed errors
    [BBB_Board.SchDoc]
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2016-03-24 I'm pushing the work I have now. I don't think we need external tristate buffers and template registers anymore; we can just plcae them inside the FPGA!
    [BBB_Board.PcbDoc, BBB_Board.PcbLib, BBB_Board.PrjPCB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]
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2016-03-25 Made some fixes to the BBB_Board PCB layout. Autorouter completes in about 15 minutes. Need to add labels and verify connections.
    [BBB_Board.PcbDoc, BBB_Board.PcbLib, BBB_Board.PrjPCB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]
2016-03-25 Fixed some issues with aligning of BBB SMD pads for other boards. I believe the board is ready to route now.
    [BBB_Board.PcbDoc, BBB_Board.PrjPCB, DUTBoard.PrjPcb]
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2016-04-06 Made a few tweaks to the DUTBoard's Top Overlay.
    [DUTBoard.GBL, DUTBoard.GBO, DUTBoard.GBP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]
2016-04-09 Added BRAM_CTRL (need to test). UART_CTRL appears to work OK.
    [UART_CTRL_pad.csv]
2016-04-11 Tested (not super exhaustively though) block RAM controller (appears to be OK after a few fixes). Also adding testbench for block RAM.
    [BRAM_CTRL.v, BRAM_CTRL_TB.v]
2016-04-12 Fixed a ton of errors with BBB Board. Ready to route I believe.
    [BBB_Board.PcbDoc, BBB_Board.PcbLib, BBB_Board.PrjPCB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]
2016-04-12 New BBB board designs (no planes and planes, fixed schematic errors, improved design overall).
    [BBB_Board.PrjPCB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]
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2016-04-23 TOP_MODULE (i.e. CENTRAL_FSM) now synthesizes without errors, but I am using too many slice LUTs (about 108% of what's available). Need to perform some hardware optimization to reduce the number of L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
    [CENTRAL_FSM.v]
2016-04-23 Reduced the area constraint to 70 (from 115) by removing TRAILING_EDGE_2 and CYCLE_LENGTH_2 and just providing LEADING_EDGE_2 instead. Synthesizes with no warnings or errors, so ready to begin testbe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
    [CENTRAL_FSM.v]
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2016-04-25 Fixed some bugs in the Verilog code. It appears to work now (note: be wary of ground bouncing on RST line...).
    [TOP_MODULE_pad.csv]
2016-04-27 Cleanup and bug fixes in Verilog.
    [TOP_MODULE_pad.csv, UART_CTRL_pad.csv]
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2016-05-12 Fixed the power network
    [BBB_Board.PrjPCB, BBB_Board.SchDoc]
2016-05-12 Corrected boards are now routed.
    [BBB_Board.PrjPCB, BBB_Board_NEW.PcbDoc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]
2016-05-17 A little bit of repo cleanup done. I think it's best to wait until the final end of the project before we clean the repo...
    [DUTBoard.GBL, DUTBoard.GBO, DUTBoard.GBP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]
2016-05-17 Getting rid of this folder since we never used it.
    [Schlib1.SchLib, buff_board.SchDoc, buffer_board.PrjPcb]
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
